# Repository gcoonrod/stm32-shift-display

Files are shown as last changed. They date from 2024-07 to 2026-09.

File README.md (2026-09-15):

# STM32 Shift Display

A proof-of-concept STM32 based development board designed for experimentation with 74x595 driven 7-segment LED character displays. The sponsored revision of the board is built out as a desk clock, the "STM32 Shift Clock".

> **Building or hacking on this?** [`docs/DEVELOPMENT.md`](./docs/DEVELOPMENT.md) covers prerequisites, build and flash, the USB command set, the pin map, and what is still unimplemented.

## Current Revision — rev 2
Sponsored by: 

PCBWay

Due to a generous sponsorship from PCBWay the current hardware revision (rev 2) includes a number of substantial design changes over the first revision:
-  All SMD components from rev 0 moved to the back.
-  Most THT components from rev 0 changed to hand-solder friendly SMD components.
-  Supercap backup for VBAT switched to more common CR2032 battery holder.
-  Addition of ESD IC for the USB connection and a correction for an issue with the USB FS series and pull-up resistors.
-  Move to a 4 layer PCB and use of via-in-pad resin plug with copper capping to simplify routing.
-  Addition of an aluminum sheet metal stand.
-  Remap latch OE pin and user LED pins to PWM capable outputs.
-  Break out UART3 "just in case".

Full schematic for this revision: [STM32ShiftDisplayRev2.pdf](./hardware/assets/STM32ShiftDisplayRev2.pdf)

### Revision Objectives
Issues with the USB connection in the first revision made a new revision necessary in order to support UART communication over the USB connection. While the USB termination bug was the primary driver for spinning a new board, there were also a few other short comings of the original design that became apparent during firmware development. The choice of shift registers to drive the LED displays instead of multiplexing made writing the display driver code simple but gave up the brightness control (from PoV) that comes "for free" with that approach. The 74HC595 has an output enable control signal that _maybe_ could be used to achieve a similar effect, so this revision includes a remapping of some of the signals, including the user LEDs, to pins on the MCU that support hardware PWM. 

As the objective of this project is as much learning as arriving at a finished "product", I took the opportunity to try out a number of new things as well. Did you know that PCBWay does sheet metal bending?

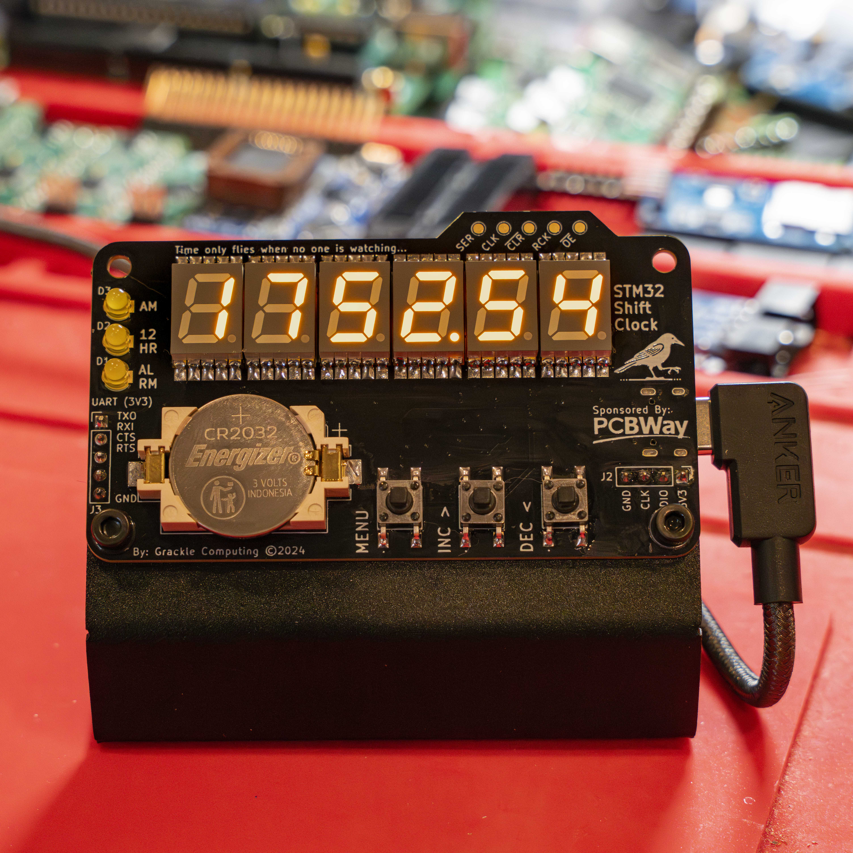
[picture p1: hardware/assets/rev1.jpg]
final product


### Pushing the Envelope
With a green light to "showcase capabilities" from PCBWay, I wanted to make something worth showing off. After reviewing the website and discovering their 3D printing/CNC milling service I decided to design something that would take advantage of more than just PCBWay's PCB printing capabilities. While the core of this project would remain a development board for STM32F1 hardware and software design, this sponsored revision would be the "STM32 Shift Clock". After a brief affair with a split board design I landed on the simple board and stand design above. This design allowed me to highlight three of PCBWay's capabilities that make them great board partners for hobbyists and professionals alike. First, the PCB is a 4-layer design utilizing [via-in-pad to simplify the routing](./hardware/assets/via-in-pad.PNG) between the shift registers and LEDs characters. PCBWay's engineers were great to work with on this and made the process of indicating which vias needed to be filled and capped simple. Which was really great because KiCad does not currently have a way to indicate if a specific via should be filled. Second, I moved all of the tiny (i.e. too hard to hand solder) components to the back of the board and relied on PCBWay's turnkey PCB assembly service to source the parts and do the hard work of getting all those tiny bits in the right spots. Again, PCBWay's engineers made the process of approving the parts selection and confirming placement and orientation easy. I used LCSC as the supplier for all of the parts on this board and all I had to do was indicate the LCSC part numbers and PCBWay took care of the rest. Their engineers even sent pictures of the boards in production so that I could visually inspect all of the parts placements. And finally, the stand. I've only ever dabbled in 3D printing and certainly never with metal. So when I saw that PCBWay could do low volume sheet metal bending I had to try it out. What followed was a caffeine fueled afternoon of YouTube tutorials and frustrating attempts to get the idea in my head out into FreeCAD. In the end I went with a very simple design that displays the PCB nicely while keeping it from tipping/sliding when pressing the buttons. I chose 5052 Aluminum with a bead blasted and anodized finish to match the PCB. Given the materials and manual labor involved I was really pleased with how reasonable the quoted cost was per piece. All in all I was very impressed with my interactions with PCBWay for this project. From the initial design submissions to the engineering verification and the customer service interactions PCBWay helped me take an idea from mind to matter and I look forward to working with them again on my future projects.

### A note on revision numbers

This board is called **rev 2** here and in `stm32-shift-display.kicad_sch`, but the
sources disagree and all of them describe this same physical board:

| Source | Says |
| --- | --- |
| Schematic title block, `STM32ShiftDisplayRev2.pdf` | rev 2 |
| Git branch `feature/board-rev2`, commit "Initial rev2 design" | rev 2 |
| `stm32-shift-display.kicad_pcb` title block | rev 1 *(stale)* |
| Photo and model assets — `rev1.jpg`, `board_and_stand_rev1.jpg`, `stm32-shift-display_rev1.step` | rev 1 *(same board)* |

The `.kicad_pcb` title block is corrected only when the board is next opened in
KiCad — see [Hardware files](./docs/DEVELOPMENT.md#hardware-files) for why that is
deliberately deferred.

## Firmware

The firmware keeps time on the MCU's RTC and exposes a small command console over
USB CDC, which [`software/timesync`](./software/timesync) uses to compare and correct
the clock against NTP. The on-device menu and display brightness control are not
finished. [`docs/DEVELOPMENT.md`](./docs/DEVELOPMENT.md) has the command set, the
known defects, and what is left to build.

## Schematic
current schematic

## Board Render
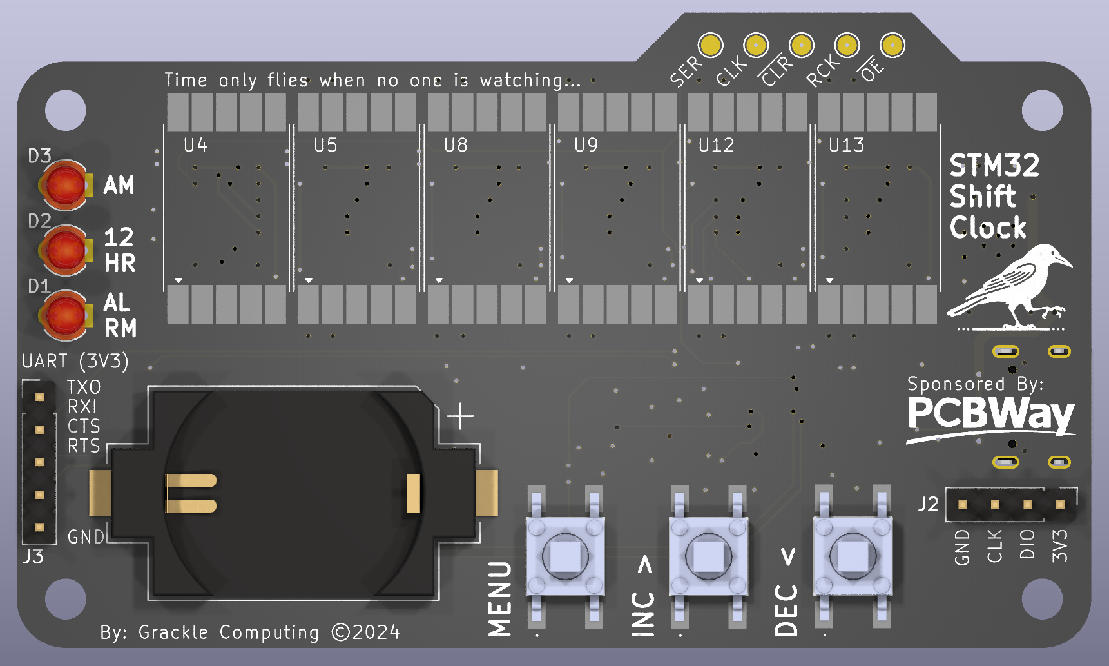
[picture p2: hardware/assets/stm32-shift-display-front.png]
current board


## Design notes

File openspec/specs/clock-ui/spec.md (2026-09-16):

# clock-ui Specification

## Purpose

Defines what the device shows and how it is operated from the board itself: the idle time display and its RTC-driven redraw, hours presented in the selected 12/24-hour mode, the three user LEDs as indicators of mode and alarm state, a three-button menu that can be entered, scrolled, backed out of, and timed out of, field editors that show which field is under edit, and a glyph table that covers every character the interface renders.

## Requirements

### Requirement: The display shows the current time at rest
When not in a menu, the display SHALL show the current time of day and SHALL update as the time advances. It SHALL be shown at the configured display brightness.

"At rest" excludes the brief fade that runs when the display returns from the menu. During that fade the digits are deliberately unequal in brightness; once it completes, they SHALL be equal again.

#### Scenario: Time is displayed and advances
- **WHEN** the device is powered and not in a menu
- **THEN** the display shows hours, minutes, and seconds, and the seconds change once per second

#### Scenario: Redraw is driven by the RTC, not by polling
- **WHEN** the time has not changed since the last redraw
- **THEN** the displayed content is not recomputed, so the idle path stays as cheap as it is today

#### Scenario: Shown at the configured brightness
- **WHEN** the display is showing the time and no fade is running
- **THEN** every lit segment is at the configured display brightness, and all six digits are equally bright

#### Scenario: Brightness and content are independent
- **WHEN** the brightness changes
- **THEN** the displayed characters are unaffected — nothing is re-shifted, no digit flickers or glitches, and the decimal point keeps its state

### Requirement: Hours are presented in the selected 12/24-hour mode
The display SHALL present hours according to the selected mode, showing 0–23 in 24-hour mode and 1–12 in 12-hour mode. The RTC SHALL remain configured in 24-hour format regardless of the selected display mode, so that the conversion is a presentation concern only.

In 12-hour mode the leading zero SHALL be suppressed: an hour below ten SHALL show a blank in the tens position rather than a zero. In 24-hour mode the leading zero SHALL be kept.

#### Scenario: Midnight in 12-hour mode
- **WHEN** the RTC hour is 0 and 12-hour mode is selected
- **THEN** the display shows 12, not 0

#### Scenario: Noon and afternoon in 12-hour mode
- **WHEN** the RTC hour is 12 and then 13, with 12-hour mode selected
- **THEN** the display shows 12 and then 1

#### Scenario: 24-hour mode is unaffected
- **WHEN** 24-hour mode is selected and the RTC hour is 0 or 13
- **THEN** the display shows 00 or 13 respectively

#### Scenario: The RTC format is untouched
- **WHEN** the display mode is changed
- **THEN** the RTC's own hour format is not reconfigured, and time read back over serial is unchanged by the switch

#### Scenario: Single-digit hours lose the leading zero
- **WHEN** the displayed hour is between 1 and 9 in 12-hour mode
- **THEN** the tens position is blank, with no segments lit

#### Scenario: Two-digit hours keep both digits
- **WHEN** the displayed hour is 10, 11 or 12 in 12-hour mode
- **THEN** both digits are shown

#### Scenario: The blank is consistent wherever the time appears
- **WHEN** the time is shown while an alarm is firing
- **THEN** the leading zero is suppressed exactly as it is on the idle display

### Requirement: The LEDs indicate mode and alarm state
The three user LEDs SHALL be driven from the authoritative device state, and SHALL be updated whenever that state changes. All three are active high, and each SHALL be driven at the configured indicator brightness rather than simply on or off.

#### Scenario: AM/PM indicator
- **WHEN** 12-hour mode is selected and the time is before 12:00
- **THEN** the top LED (PB8, schematic D3) is lit, and it is unlit from 12:00 onward

#### Scenario: AM/PM is meaningless in 24-hour mode
- **WHEN** 24-hour mode is selected
- **THEN** the top LED is unlit regardless of the time

#### Scenario: Mode indicator
- **WHEN** 12-hour mode is selected
- **THEN** the middle LED (PB7, schematic D2) is lit, and it is unlit in 24-hour mode

#### Scenario: Alarm indicator
- **WHEN** an alarm is armed
- **THEN** the bottom LED (PB6, schematic D1) is lit steadily

#### Scenario: Lit means the configured brightness
- **WHEN** any indicator is lit
- **THEN** it is driven at the configured indicator brightness, and an indicator that is unlit draws no current

#### Scenario: One writer owns the pins
- **WHEN** an indicator's state changes
- **THEN** it is changed through the single path that owns the LED pins, so no code path can reconfigure a pin away from its timer and silently stop the others

### Requirement: Indicator brightness is user-settable
The brightness of the three indicator LEDs SHALL be adjustable by the user as a single level covering all three, settable from the on-device menu and over the serial console, and SHALL persist across a power cycle.

#### Scenario: Adjusting from the menu
- **WHEN** the indicator brightness is changed through the menu and committed
- **THEN** the indicators are visibly dimmer or brighter, and reading the level back reports the new value

#### Scenario: Live preview while adjusting
- **WHEN** the level is being adjusted in the editor
- **THEN** the indicators track the value as it changes, so the choice is made by eye rather than by number

#### Scenario: Round-trips over serial
- **WHEN** the indicator level is set over serial and read back
- **THEN** the value read matches the value set, and a value outside the valid range is rejected without changing the level

#### Scenario: Survives a power cycle
- **WHEN** the level is set and power is removed and restored
- **THEN** the indicators return at the level that was set

#### Scenario: Levels are perceptually even
- **WHEN** the level is stepped from lowest to highest
- **THEN** each step is a comparable change in apparent brightness, rather than the whole range appearing to happen at the bottom of the scale

#### Scenario: The dimmest level is still visible
- **WHEN** the level is at its minimum
- **THEN** each lit indicator remains visible in a dark room, so the setting cannot be mistaken for a failed LED

### Requirement: Display brightness is user-settable
The brightness of the seven-segment display SHALL be adjustable by the user, settable from the on-device menu and over the serial console, and SHALL persist across a power cycle. It is a single level covering the whole display, because the output-enable line is shared by all six digits.

Per-digit brightness, where it is used, SHALL multiply this level rather than replace it: the user's display brightness setting SHALL remain the control that dims every digit together, and no per-digit level SHALL make a digit brighter than that setting allows.

#### Scenario: Adjusting from the menu
- **WHEN** the display brightness is changed through the menu and committed
- **THEN** the display is visibly dimmer or brighter, and reading the level back reports the new value

#### Scenario: The display previews itself
- **WHEN** the level is being adjusted in the editor
- **THEN** the display tracks the value as it changes, so the choice is made by eye against the thing being adjusted

#### Scenario: Round-trips over serial
- **WHEN** the display level is set over serial and read back
- **THEN** the value read matches the value set, and a value outside the valid range is rejected without changing the level

#### Scenario: Survives a power cycle
- **WHEN** the level is set and power is removed and restored
- **THEN** the display returns at the level that was set

#### Scenario: Levels are perceptually even
- **WHEN** the level is stepped from lowest to highest
- **THEN** each step is a comparable change in apparent brightness, rather than the whole range appearing to happen at the bottom of the scale

#### Scenario: The dimmest level is still legible
- **WHEN** the level is at its minimum
- **THEN** the time can still be read in a dark room, so a dimmed clock is never mistaken for a failed one

#### Scenario: No visible flicker
- **WHEN** the display is viewed at any brightness, including at the edge of vision and while the eyes are moving
- **THEN** no flicker is perceptible

#### Scenario: Indicator brightness is separate
- **WHEN** the display brightness is changed
- **THEN** the indicator LEDs are unaffected, and vice versa

#### Scenario: A per-digit level cannot escape the global one
- **WHEN** the global display brightness is set to its minimum while a digit is at full relative brightness
- **THEN** that digit is no brighter than the global minimum allows

### Requirement: Individual digits can be dimmed relative to the display
The display SHALL support dimming individual character positions relative to the rest of the display, by lighting a digit in only some of the refresh cycle's time slices rather than all of them.

A digit's relative brightness SHALL be proportional to the number of slices it is lit in, and SHALL be independent of which slices those are and of the phase relationship with the output-enable line.

A digit at full relative brightness SHALL be indistinguishable from the same digit on a display with no per-digit dimming in use.

#### Scenario: A dimmed digit is visibly dimmer
- **WHEN** one character position is set below full relative brightness while the others stay at full
- **THEN** that digit is visibly dimmer than the others, and remains legible

#### Scenario: Full relative brightness changes nothing
- **WHEN** every character position is at full relative brightness
- **THEN** the display is indistinguishable from the same content shown without per-digit dimming

#### Scenario: Relative brightness is proportional
- **WHEN** a digit's slice count is stepped from lowest to highest
- **THEN** its brightness increases monotonically, and equal slice counts on different character positions produce equal brightness

#### Scenario: A dimmed digit does not flicker
- **WHEN** a digit is held at a low relative brightness
- **THEN** it shows no flicker, beat or shimmer distinct from the rest of the display

#### Scenario: Zero slices blanks the digit
- **WHEN** a character position is set to zero slices
- **THEN** that position shows no lit segments, and the other positions are unaffected

### Requirement: The two brightness mechanisms compose without visible interaction
Global brightness on the output-enable line and per-digit brightness in the data path are independent modulations that multiply. Their periods SHALL be related such that every time slice contains a whole number of output-enable periods, so that each slice carries the same output-enable on-time regardless of the phase between them.

The timer constants that establish this relationship SHALL be derived at build time from the output-enable frequency and the core clock, rather than written as independent literals. The build SHALL fail if the relationship is not exact.

#### Scenario: No beat between the two rates
- **WHEN** the display is held at any combination of global brightness and per-digit brightness
- **THEN** no slow flutter, beat or breathing is visible that is not commanded

#### Scenario: Digits at equal slice counts are equally bright
- **WHEN** two character positions are set to the same slice count at any global brightness
- **THEN** they are equally bright, with no fixed difference attributable to where their slices fall

#### Scenario: Global brightness still covers everything
- **WHEN** the global display brightness is changed while per-digit levels are in use
- **THEN** every digit changes brightness together, keeping their relative proportions

#### Scenario: Retuning the output-enable frequency cannot silently break the lock
- **WHEN** the output-enable PWM frequency is changed and the slice period would no longer contain a whole number of output-enable periods
- **THEN** the build fails, rather than producing firmware with per-digit brightness errors

### Requirement: The output-enable line has a single owner
The shift registers' output-enable line SHALL be driven by exactly one mechanism. Any operation that blanks or restores the display SHALL go through that owner rather than writing the pin directly, because a direct write would reconfigure the pin away from its timer and silently stop the brightness control.

The output-enable line shares a GPIO port with the shift registers' data, clock, latch and clear lines. Code driving those lines SHALL address only the pins it owns, and SHALL NOT write the port as a whole, because a whole-port write reaches across the output-enable line whatever its intent.

This SHALL hold for writes performed by a peripheral as well as by the CPU. Where the port is driven from precomputed words replayed by hardware, those words SHALL be constructed so that they cannot address the output-enable pin, and that property SHALL be enforced at build time rather than left to inspection — nothing in the instruction stream shows such a mistake.

#### Scenario: Blanking and restoring go through the owner
- **WHEN** code blanks or re-enables the display
- **THEN** it does so through the brightness owner, and the pin is never written directly

#### Scenario: Restoring returns to the configured brightness
- **WHEN** the display is blanked and then re-enabled
- **THEN** it returns to the configured brightness rather than to full

#### Scenario: The display is blank through reset
- **WHEN** the MCU is in reset or has not yet configured the pin
- **THEN** the display is blank rather than showing whatever the shift registers powered up holding

#### Scenario: Shifting data does not disturb brightness
- **WHEN** data is shifted out, latched, or the registers are cleared
- **THEN** the output-enable line is unaffected and the display's brightness does not change

#### Scenario: Port-wide writes are not used
- **WHEN** the display driver drives its pins
- **THEN** it addresses them individually rather than writing the whole port, so no operation can reach a pin it does not own

#### Scenario: Peripheral-written words cannot reach the output-enable pin
- **WHEN** a word destined for the port is constructed for replay by hardware
- **THEN** it addresses only the data, clock, latch and clear pins, and a word that would set or clear the output-enable pin fails the build

### Requirement: The menu is reachable and navigable with three buttons
Clicking SET from the idle display SHALL open a top-level menu. PLUS and MINUS SHALL move between menu entries, wrapping at the ends. Clicking SET SHALL enter the highlighted entry. Holding SET SHALL leave the current level without committing a change.

#### Scenario: Entering the menu
- **WHEN** SET is clicked while the clock is displayed
- **THEN** the first menu entry is shown

#### Scenario: Scrolling wraps
- **WHEN** MINUS is pressed on the first menu entry
- **THEN** the last entry is shown

#### Scenario: Backing out discards
- **WHEN** SET is held while inside an entry whose value has been altered but not committed
- **THEN** the previous level is shown and the altered value is not saved

#### Scenario: Menu state actually advances
- **WHEN** a menu transition is requested
- **THEN** the state machine commits the pending menu state, so successive transitions move through the tree rather than repeating the same state

### Requirement: Field editors show which field is being edited
Inside an editor, the field under edit SHALL be visually distinguished by blinking. PLUS and MINUS SHALL adjust the field, wrapping at its limits, and SHALL repeat while held. Clicking SET SHALL advance to the next field, and SHALL commit the value after the last field.

#### Scenario: The edited field blinks
- **WHEN** the hour field is being edited
- **THEN** the hour digits alternate between visible and blank while the remaining digits stay lit

#### Scenario: Values wrap at their limits
- **WHEN** PLUS is pressed with the minute field at 59
- **THEN** the minute field becomes 0

#### Scenario: Holding repeats
- **WHEN** PLUS is held
- **THEN** the field advances repeatedly without further presses

#### Scenario: Committing writes through
- **WHEN** SET is clicked on the last field of the time editor
- **THEN** the new time is written to the RTC and the display returns to showing it

### Requirement: The menu does not strand the device
The menu SHALL return to the idle time display after a period with no button activity, so the device cannot be left showing a menu indefinitely.

#### Scenario: Inactivity returns to the clock
- **WHEN** no button is pressed for the inactivity period while a menu or editor is open
- **THEN** the display returns to the time, with no uncommitted value saved

### Requirement: Returning to the clock from the menu fades the digits in
When the display returns to the idle time display from the menu or an editor, the digits SHALL fade in one at a time, left to right, rather than appearing at once. This SHALL apply whether the return was by backing out, by committing an edit, or by the inactivity timeout.

The fade SHALL be driven by elapsed time rather than by counting steps, so that a delayed pass through the main loop shortens the fade rather than stretching it.

The fade SHALL change brightness only. The displayed content SHALL NOT be recomputed or re-shifted on its account.

The fade SHALL always end with every character position at full relative brightness and the display at the configured global brightness. If anything interrupts it — a button press, a re-entry to the menu, an alarm firing — it SHALL be abandoned and every position returned to full immediately, so that no path can leave a digit dim.

#### Scenario: Backing out of the menu fades in
- **WHEN** the menu is backed out of and the display returns to the time
- **THEN** the digits appear one at a time from left to right, and all six are at full brightness when the fade completes

#### Scenario: Committing an edit fades in
- **WHEN** an editor's last field is advanced past and the value is committed
- **THEN** the display returns to the time with the same fade

#### Scenario: Timing out fades in
- **WHEN** the inactivity timeout returns the display to the time
- **THEN** the display returns with the same fade

#### Scenario: Dismissing an alarm does not fade
- **WHEN** a firing alarm is dismissed and the display returns to the time
- **THEN** the time is shown at once, at full brightness, with no fade

#### Scenario: Interrupting the fade does not strand a dim digit
- **WHEN** a button is pressed, the menu is re-entered, or an alarm fires while the fade is running
- **THEN** the fade is abandoned and every character position is at full relative brightness immediately

#### Scenario: The fade ends at the user's brightness, not above or below it
- **WHEN** the fade completes at any configured display brightness, including the minimum
- **THEN** the display is at exactly the brightness it would have been had there been no fade

#### Scenario: A blanked position stays blank through the fade
- **WHEN** the leading hour position is blank in 12-hour mode and the fade runs
- **THEN** nothing appears at that position at any point in the fade, and the remaining digits keep their timing

#### Scenario: The fade does not recompute content
- **WHEN** the fade is running and the time has not changed
- **THEN** the displayed characters are not recomputed or re-shifted, so the idle path stays as cheap as it is today

#### Scenario: A slow loop shortens the fade rather than stretching it
- **WHEN** the main loop is delayed during a fade
- **THEN** the fade reaches full brightness at the time it would have anyway, skipping intermediate levels rather than running long

### Requirement: The glyph table covers the characters the UI renders
The display driver SHALL render every character the user interface asks it to draw. The glyph table and the character-range validation SHALL be extended together, so that a character added to one is never rejected by the other.

#### Scenario: Menu labels render
- **WHEN** a menu label is written to the display
- **THEN** every character in it renders as its intended glyph, not as the invalid-character indicator

#### Scenario: Unsupported characters still fail visibly
- **WHEN** a character with no glyph is written
- **THEN** the invalid-character indicator is shown, rather than a blank or an arbitrary pattern

### Requirement: The display refreshes without CPU involvement
The display SHALL be refreshed continuously by a hardware peripheral replaying a precomputed waveform, rather than by the CPU clocking bits out on demand. The refresh SHALL continue at its full rate while the CPU is busy elsewhere, and SHALL NOT require the main loop to run at any particular rate.

Changing what is displayed SHALL be a matter of writing to the waveform buffer. No caller SHALL be required to shift or latch anything for the change to appear.

#### Scenario: The refresh survives a busy CPU
- **WHEN** the main loop is occupied for longer than one refresh period
- **THEN** the display continues refreshing at the same rate, with no flicker, dimming or corruption

#### Scenario: Writing the buffer is enough
- **WHEN** new content is written to the display
- **THEN** it appears without the caller shifting or latching, within one refresh period

#### Scenario: The refresh rate is above the flicker threshold
- **WHEN** the display is viewed at the edge of vision, or while the eyes are moving across it
- **THEN** no flicker is perceptible at any brightness

#### Scenario: Nothing is shown before the engine is configured
- **WHEN** the MCU has reset and the engine has not yet been started
- **THEN** the display is blank rather than showing whatever the shift registers powered up holding

### Requirement: The shift-out stays within the shift registers' timing limits
The rate at which data is clocked into the shift registers SHALL be slow enough for the devices fitted, at the voltage they run at, with margin. The limit SHALL be established by measurement on the assembled board rather than by calculation alone, because the binding constraint is the serial propagation delay accumulated through a chain of six devices, and the parts are specified at a higher voltage than the board supplies.

Where the rate is set by a timer rather than by instruction timing, it SHALL be a chosen frequency derived from the core clock, not a consequence of what the compiler emitted. The chosen rate SHALL still be justified against the measured failure point.

#### Scenario: The safe rate is measured, not assumed
- **WHEN** the shift rate is chosen
- **THEN** it is derived from an observed failure point on the assembled hardware, and the margin between the two is recorded

#### Scenario: Corruption is made visible during measurement
- **WHEN** the shift rate is swept to find the failure point
- **THEN** the pattern on the display is one where corruption is unmistakable, since the end of the chain is not wired back and no electrical readback exists

#### Scenario: The display is correct at the chosen rate
- **WHEN** the display is exercised at the chosen rate across all six digits and the full glyph set
- **THEN** every character renders correctly, with no intermittent wrong segments

#### Scenario: The rate is stated where it can be found
- **WHEN** someone asks why the shift runs at the rate it does
- **THEN** the measured failure point, the chosen rate and the margin between them are recorded, rather than left as an unexplained constant

#### Scenario: A timer-set rate is exact
- **WHEN** the shift clock is produced by a timer
- **THEN** its frequency follows from the core clock and the timer's reload value, and is stated as a number rather than estimated from instruction counts

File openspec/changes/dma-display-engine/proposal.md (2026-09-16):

## Why

Brightness today is global because the hardware makes it so: `~OE` is a single net across
all six shift registers, so TIM2's PWM dims every digit together. There is no wire that
would let one digit be dimmer than another.

But brightness does not have to come from `~OE`. If the segment data is re-shifted fast
enough, a digit lit in three refreshes out of eight is three-eighths as bright as one lit
in all eight — brightness as a property of the *data* rather than the output-enable line.
That gives per-digit and per-segment control that the wiring cannot.

The obstacle is cost. Data-path dimming needs the display re-shifted continuously at
kilohertz rates, and doing that from the CPU means spending the loop on it forever.

DMA removes the obstacle entirely. `BSRR` takes a 32-bit word whose low half sets pins and
whose high half clears them, so an entire shift waveform can be precomputed as an array of
words and replayed by a DMA channel on a timer's tick, with the CPU uninvolved:

```
RAM buffer, one BSRR word per edge:

  [ SER set,   SRCLK clear ]   present the bit
  [ SRCLK set              ]   rising edge clocks it in
  [ SER clear, SRCLK clear ]
  [ SRCLK set              ]
  ... 96 words for 48 bits ...
  [ RCLK set ] [ RCLK clear ]  latch

  TIM1 update ──▶ DMA1 Ch5 ──▶ GPIOA->BSRR
    every N ticks   one word per event
```

In **circular** mode the buffer replays forever. The display stops being something the CPU
draws and becomes something that refreshes itself.

All seven DMA1 channels are free — the only DMA symbols in the current image are two-byte
default interrupt stubs. TIM1 and TIM3 are unused; TIM2 and TIM4 belong to display
brightness and the indicator LEDs and stay untouched.

## What Changes

- A timer-driven, circular DMA channel replays a precomputed `BSRR` waveform to GPIOA,
  refreshing the display continuously with no CPU involvement.
- The waveform holds **N time-slices**. A digit's brightness is how many slices it appears
  lit in, giving per-digit — and in principle per-segment — brightness.
- The timer period sets the shift clock **exactly**, which also settles the 74HC595-at-3.3 V
  timing question far better than instruction counting can: the rate is a number you choose
  rather than a consequence of what the compiler emitted.
- Global `~OE` brightness stays as it is. Per-digit brightness multiplies with it rather
  than replacing it.
- The first use is the one that prompted this: **dimming the leading hour digit in 12-hour
  mode** rather than blanking it.

## What this costs

The numbers are the argument, in both directions.

For a flicker-free cycle the whole slice set must repeat well above the eye's threshold.
At 8 slices and roughly 100 words per full shift, a 1 kHz cycle rate needs

```
8 slices × 100 words × 1000 Hz  =  800,000 words/second
                                =  ~400 kHz shift clock   (comfortably within the parts)
                                =  3,200 bytes of RAM      (8 × 100 × 4)
```

3.2 KB against 20 KB total, on top of the 4.9 KB already used — call it 39% of RAM. Four
slices halves it at the cost of coarser steps.

Against that: the CPU cost of refreshing the display drops to zero, and stays zero no
matter how fast it refreshes.

## Capabilities

### New Capabilities
_None._

### Modified Capabilities
- `clock-ui`: "Display brightness is user-settable" currently states that brightness is a
  single level for the whole display because the output-enable line is shared. That
  reasoning stops being the whole story once brightness can also come from the data path,
  so the requirement needs to say how the two interact. The capability also gains per-digit
  brightness, and a requirement that the display refreshes without CPU involvement.

## Impact

- **Firmware**: `firmware/lib/ShiftDisplay/` substantially — the driver stops shifting bits
  and starts maintaining a waveform buffer. `firmware/src/main.cpp` where brightness and
  rendering meet.
- **Peripherals**: claims a timer (TIM1 or TIM3) and a DMA1 channel. Neither is used today,
  and TIM2/TIM4 are deliberately left alone.
- **RAM**: 1.6–3.2 KB depending on slice count, against 15.6 KB free.
- **Risk**: this is the largest single change contemplated for this firmware. It replaces a
  working display driver with a peripheral configuration, and DMA faults are harder to
  diagnose than a wrong `digitalWrite`. There is also **no readback**: `U15`'s `QH'` is
  unconnected, so correctness is confirmed by eye.
- **Two PWMs multiplying**: data-path slices and `~OE` gating interact. Beat frequencies
  between the slice rate and the `~OE` rate are the thing to watch, and the reason the two
  rates should not be close or harmonically related.

## Ordering

`bsrr-shift-out` should land first. It establishes the cached port, the cached masks and
the explicit `BSRR` discipline that this engine builds on, and it produces the measured
safe clock rate that this change needs in order to choose a timer period. Doing this one
first would mean guessing that number twice.

## Not in scope

- **Blanking** the leading hour digit, which needs no engine at all — writing a space
  instead of a zero is a few lines in the render path and should not wait for this.
- Any change to what the display shows, beyond the brightness of individual digits.
- Replacing `analogWrite` on `~OE`; global brightness stays on TIM2 exactly as it is.

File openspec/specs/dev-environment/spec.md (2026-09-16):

# dev-environment Specification

## Purpose

Defines what a working development environment for this project must provide: PlatformIO Core invocable from a plain shell, a firmware build that succeeds from a clean tree, flashing over SWD via ST-Link, a board reachable over USB CDC, a reproducible Python environment for the host tooling in `software/timesync/`, explicit serial port selection, and a single documented readiness check.

## Requirements

### Requirement: PlatformIO Core is invocable from a shell
The development environment SHALL provide PlatformIO Core as a `pio` executable resolvable on `PATH` from a non-interactive shell, so that builds and flashes can be driven from a terminal or an agent session without an IDE.

#### Scenario: pio resolves in a fresh shell
- **WHEN** `pio --version` is run in a newly started shell
- **THEN** it prints a PlatformIO Core version and exits 0

#### Scenario: PlatformIO is not tied to an editor installation
- **WHEN** the `pio` executable's location is inspected
- **THEN** it resolves outside any VS Code extension directory, so terminal and IDE use do not depend on each other

### Requirement: Firmware builds from a clean tree
The repository SHALL build to completion with the toolchain installed on this machine, starting from a tree with no prior build artifacts.

#### Scenario: Clean build succeeds
- **WHEN** `firmware/.pio/` is removed and `pio run -d firmware` is run
- **THEN** PlatformIO fetches the `ststm32` platform, the ARM toolchain, and the three `lib_deps`, and the build exits 0

#### Scenario: Build produces a flashable image
- **WHEN** the build completes
- **THEN** `firmware/.pio/build/bluepill_f103c8_128k/firmware.elf` and `firmware.bin` exist and are newer than the build start

### Requirement: Firmware flashes over SWD
The environment SHALL flash the connected board through the attached ST-Link, since the board offers no DFU or bootloader upload path.

#### Scenario: Upload to the attached board
- **WHEN** the ST-Link is connected to the board's SWD header and `pio run -d firmware -t upload` is run
- **THEN** the upload completes successfully and the MCU restarts running the new image

#### Scenario: Missing debugger is reported clearly
- **WHEN** an upload is attempted with no ST-Link attached
- **THEN** the failure names the missing probe rather than presenting as a build error

### Requirement: The board answers over USB CDC
The environment SHALL be able to open the board's USB CDC port and exchange commands with the running firmware.

#### Scenario: Device reports its time
- **WHEN** `GT\r\n` is written to the board's CDC port
- **THEN** the device replies with a single integer Unix timestamp

#### Scenario: CDC port is discoverable
- **WHEN** the board is attached and serial devices are enumerated
- **THEN** the STM32 CDC device is identifiable by its USB descriptor rather than only by a machine-specific device-node name

### Requirement: Host tooling runs from a reproducible environment
The `software/timesync` tool SHALL run from an environment that pins its interpreter and dependencies and is recreatable from files committed to the repository, without depending on whichever interpreter happens to be first on `PATH`.

#### Scenario: Environment is recreated from a clean checkout
- **WHEN** the environment directory is absent and the documented setup command is run in `software/timesync/`
- **THEN** the environment is created with the pinned interpreter and `pyserial` and `ntplib` importable

#### Scenario: Tool runs against the device
- **WHEN** the board is attached and the timesync tool is run in read-only mode
- **THEN** it prints the NTP time, the device time, and the skew between them, and exits 0

#### Scenario: No dependence on an absent interpreter
- **WHEN** the environment is inspected for the interpreter it resolves to
- **THEN** that interpreter exists on this machine, and no committed file references a Homebrew `python@3.12.4` path

### Requirement: Serial port selection is explicit
The timesync tool SHALL NOT silently fall back to a device node hardcoded for one machine. It SHALL select a port that it discovered, or one the caller supplied, and SHALL fail with an actionable message when neither is available.

#### Scenario: Port supplied by the caller
- **WHEN** the tool is invoked with an explicit port argument
- **THEN** it uses that port and does not consult any default

#### Scenario: No device attached
- **WHEN** the tool is run with no port argument and no STM32 CDC device is present
- **THEN** it exits non-zero with a message naming the missing device and how to specify a port

### Requirement: Environment readiness is verifiable in one step
The repository SHALL provide a documented way to check the prerequisites for firmware and host-tool development, reporting each one's presence rather than failing at the first gap.

#### Scenario: Readiness check on a configured machine
- **WHEN** the documented check is run on a machine with the toolchain installed
- **THEN** it reports PlatformIO, the Python environment, the attached ST-Link, and the attached CDC device as present

#### Scenario: Readiness check on an unconfigured machine
- **WHEN** the check is run where PlatformIO is absent
- **THEN** it reports that specific prerequisite as missing and names the command that installs it

### Requirement: The toolchain is not pinned to a superseded core line
The firmware SHALL build against a currently published Arduino STM32 core, and SHALL NOT depend on a platform version whose framework package the PlatformIO registry no longer serves. Where a version constraint is kept, it SHALL be a floor or a range that continues to resolve, not a pin to a single superseded release.

#### Scenario: Build resolves without a platform pin
- **WHEN** `firmware/platformio.ini` names no exact platform version and `pio run -d firmware` is run
- **THEN** PlatformIO resolves the current `ststm32` platform and the build exits 0

#### Scenario: Library constraints admit the versions that work
- **WHEN** the `lib_deps` constraints are resolved against the registry
- **THEN** each one resolves to a version that compiles against the core in use, and no dependency is listed that the project neither includes nor calls

#### Scenario: Registry purge does not strand the build
- **WHEN** a framework package older than the one in use is purged from the registry
- **THEN** the project's own constraints still resolve, because they do not name it

### Requirement: A toolchain change is verified on hardware
A change that alters the compiler, core, or library versions the firmware is built against SHALL be verified by running the resulting image on the board, not by compilation alone. Compiling proves the source is accepted; it does not prove the peripherals still behave.

#### Scenario: The image runs after a toolchain change
- **WHEN** firmware built against the new toolchain is flashed to the board
- **THEN** the display shows the time and the digits advance, confirming the RTC seconds interrupt still fires

#### Scenario: The command console survives the change
- **WHEN** the board is addressed over USB CDC after the change
- **THEN** it enumerates with USB descriptor `0483:5740` and answers `TEST` with `TEST` and `GT` with an integer Unix timestamp

#### Scenario: Timekeeping survives the change
- **WHEN** the clock is set over CDC and read back after at least a minute
- **THEN** the time has advanced by the elapsed interval, confirming the LSE clock source and RTC configuration still work

#### Scenario: A regression is attributable
- **WHEN** behavior differs from before the toolchain change
- **THEN** the change under test contains no unrelated source edits, so the difference is attributable to the toolchain

### Requirement: Flash headroom is known and protected
The firmware's flash usage SHALL be reportable on demand, expressed against the device's fixed capacity. A change that materially increases it SHALL be a deliberate choice rather than something discovered when a build stops fitting.

#### Scenario: Usage is reportable
- **WHEN** the environment readiness check is run
- **THEN** it reports the current flash usage and the remaining headroom, without requiring a separate build step to be remembered

#### Scenario: A regression is attributable
- **WHEN** flash usage grows materially between two builds
- **THEN** the growth can be attributed to the change that caused it, because the figure is recorded per change rather than only observed at the end

#### Scenario: The budget is stated, not implied
- **WHEN** someone asks how much room is left
- **THEN** the answer comes from the documented capacity and current usage rather than from reading a build log

#### Scenario: Headroom survives a size-reduction effort
- **WHEN** space is reclaimed by a change whose purpose is reclaiming it
- **THEN** the new figure is recorded, so later work starts from a known baseline rather than from the last number anyone happened to notice

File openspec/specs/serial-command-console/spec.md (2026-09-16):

# serial-command-console Specification

## Purpose

Defines the USB CDC command console: the existing `TEST`, `GT`, `ST`, `SO`, and `GO` commands preserved exactly so host tooling keeps working, serial access to every setting the on-device menu can change, and argument validation that rejects missing or out-of-range values instead of applying partial or clamped ones.

## Requirements

### Requirement: The existing command set is preserved exactly
The commands `TEST`, `GT`, `ST`, `SO`, and `GO` SHALL keep their current names, arguments, replies, and framing. Host tooling written against them SHALL continue to work without modification. Their internal implementation may change freely, provided the bytes on the wire do not.

The one permitted exception is the calendar month, which SHALL be represented consistently as 1–12 by every path that reads or writes it. A date set over serial and a date set from the on-device menu SHALL agree with each other and with the RTC.

#### Scenario: Existing commands answer as before
- **WHEN** `TEST`, `GT`, and `GO` are sent
- **THEN** they reply `TEST`, a Unix timestamp, and the timezone offset respectively, as they did before this change

#### Scenario: Setting the time still works
- **WHEN** `ST` is sent with a Unix timestamp
- **THEN** it replies `OK` and the clock is set, and reading the time straight back with `GT` returns the timestamp that was set

#### Scenario: The host tool is unaffected
- **WHEN** the existing timesync tool is run against the device
- **THEN** it reports the device time and corrects it exactly as it did before this change, with no edit to the tool

#### Scenario: Framing is unchanged
- **WHEN** commands are sent terminated by carriage return and newline with space-separated arguments
- **THEN** they are parsed as before, within the existing receive buffer size

#### Scenario: The two ways of setting the date agree
- **WHEN** a date is set from the on-device menu and then read over serial
- **THEN** the month reported matches the month that was entered, and the same holds in reverse for a date set over serial and then viewed in the menu

#### Scenario: Replies are byte-identical
- **WHEN** any command's reply is compared against the same command's reply from the previous firmware
- **THEN** the bytes match exactly, including error messages, separators and line endings

### Requirement: The new device state is reachable over serial
Every setting the on-device menu can change SHALL also be readable and writable over the serial console, so the device can be configured and tested from a host.

#### Scenario: Display mode round-trips
- **WHEN** the 12/24-hour mode is set over serial and read back
- **THEN** the value read matches the value set, and the display and mode LED reflect it

#### Scenario: Alarm time round-trips
- **WHEN** the alarm time is set over serial and read back
- **THEN** the value read matches the value set

#### Scenario: Armed state round-trips
- **WHEN** the alarm is armed over serial and the armed state is read back
- **THEN** it reports armed, and the bottom LED is lit

#### Scenario: Menu changes are visible to the host
- **WHEN** a setting is changed using the buttons and then read over serial
- **THEN** the value read reflects the change made on the device

### Requirement: Commands validate their arguments
A command given a missing or out-of-range argument SHALL report an error and leave device state unchanged, rather than applying a partial or clamped value.

#### Scenario: Missing argument
- **WHEN** a command requiring an argument is sent without one
- **THEN** it replies with an error and no state changes

#### Scenario: Out-of-range argument
- **WHEN** a command is sent a value outside the valid range for its field
- **THEN** it replies with an error naming the problem and no state changes

#### Scenario: Unrecognized commands are still reported
- **WHEN** an unknown command is sent
- **THEN** the existing unrecognized-command reply is produced

### Requirement: Persisted settings are diagnosable from a host
The device SHALL report the raw contents of its settings storage over the serial console, including the values read at start-up before any code could overwrite them. Settings loss that cannot be reproduced on demand is otherwise indistinguishable from settings that were never saved, and the two have opposite causes.

#### Scenario: Start-up values are reported as they were read
- **WHEN** the raw settings storage is read over serial
- **THEN** the report includes what the start-up read returned, distinct from what the storage holds at the time of the query

#### Scenario: A self-inflicted overwrite is distinguishable from lost storage
- **WHEN** settings have unexpectedly returned to their defaults
- **THEN** the report shows whether start-up saw valid stored settings, which separates storage that failed to retain from firmware that overwrote good values with defaults

#### Scenario: The expected validity marker is reported alongside
- **WHEN** the report is read
- **THEN** it includes the value the firmware treats as marking initialised storage, so a mismatch is visible without consulting the source

### Requirement: Command replies do not depend on formatted-output machinery
Command replies SHALL be produced without pulling a general-purpose formatted-output implementation into the image. The text of every reply is fixed by "The existing command set is preserved exactly"; how it is assembled is not, and the assembly method SHALL be chosen so that the cost of the whole `printf` family is not paid for `%d` and `%s`.

#### Scenario: The formatted-output engine is absent
- **WHEN** the linked image is inspected for the general-purpose formatted-output implementation
- **THEN** it is not present

#### Scenario: Replies are unchanged by the substitution
- **WHEN** every command that previously used formatted output is exercised, including its error paths
- **THEN** each reply is byte-identical to the previous firmware's

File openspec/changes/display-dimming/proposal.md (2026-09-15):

## Why

The display runs at one brightness: full. Six digits are driven statically — six
74HC595s, 48 segment resistors, every lit segment conducting continuously — so a clock
showing `12 34 56` has upwards of twenty segments on at all times. On a desk that is
right. At 3am it is a lamp.

The hardware was built for this. `~OE` is on PA0, which is `TIM2_CH1`, and TIM2 is
entirely unclaimed (the variant reserves TIM3 for `tone()` and TIM4 for `Servo`). The
netlist shows `~OE` as a single net reaching all six registers:

```
        PA0 ──┬── R12 10k ── VCC        pull-up: blanked through reset
              │
              ├──▶ U6.13  ~OE  digit 1
              ├──▶ U7.13  ~OE  digit 2
              ├──▶ U10.13 ~OE  digit 3
              ├──▶ U11.13 ~OE  digit 4
              ├──▶ U14.13 ~OE  digit 5
              └──▶ U15.13 ~OE  digit 6
```

That topology makes PWM dimming close to an ideal case rather than a compromise. On a
multiplexed display, dimming fights the refresh scan — modulating a signal that is
already chopped, producing beats and uneven digits. Here there is no scan to fight.
Duty becomes the only variable and the instantaneous segment current stays at its design
point at every brightness, so the LEDs never drift toward the low-current region where
efficiency and colour go strange. `~OE` to output on an HC595 is tens of nanoseconds,
four orders of magnitude faster than the shortest duty step worth using, so the shift
registers are nowhere near the limit.

The dead `irq_timer_led()` in `main.cpp` is a software attempt at the same idea —
toggling `display.enable()`/`disable()` from a timer callback that nothing ever calls.
The hardware can do it properly.

## What Changes

- Drive `~OE` from TIM2_CH1 PWM, giving global display brightness across all six digits.
- **A brightness level in the menu**, persisted like the other settings, with the display
  itself as the live preview while adjusting — the one setting whose effect you can see
  as you change it.
- Gamma-mapped levels, for the same perceptual reason as the indicator LEDs.
- **A minimum brightness floor.** The lowest selectable level stays legible; a clock
  dimmed to nothing reads as a dead clock, and someone will conclude the board has
  failed.
- PWM frequency in the low kilohertz. Flicker, not resolution, is the constraint: at
  72 MHz even 10 kHz leaves 7,200 duty steps, far more than the handful of levels a user
  will ever see, whereas a few hundred hertz on a bright point source in a dark room is
  exactly where eye movement makes flicker visible.
- **`ShiftDisplay::enable()`/`disable()` become brightness operations.** They currently
  `digitalWrite` PA0, which once TIM2 owns the pin in alternate-function mode would
  reconfigure it back to plain GPIO and silently stop the PWM. Every caller has to go
  through the new path.
- Serial get/set for the brightness level.
- Consume the dead `irq_timer_led()` hook, which this change replaces with hardware.

## Capabilities

### New Capabilities
_None._

### Modified Capabilities
- `clock-ui`: "The display shows the current time at rest" gains brightness as a property
  of the display, and the capability gains a requirement that display brightness is
  user-settable, persisted, and floored above invisibility.
- `alarm`: only if the firing flash moves onto `~OE` — see below. If it stays
  buffer-based, `alarm` is untouched.

## Impact

- **Firmware**: `firmware/lib/ShiftDisplay/` (`enable()`/`disable()` semantics, timer
  ownership), `firmware/src/main.cpp` (timer setup, settings, menu, serial).
- **Timer**: claims TIM2. Note that PA0–PA3 are TIM2_CH1–CH4 and those are the `~OE`,
  `~SRCLR`, `RCLK` and `SER` lines — TIM2 is the shift-register timer by pin allocation,
  but only CH1 is wanted and the other channels staying unconfigured leaves those pins as
  ordinary GPIO.
- **Backup domain**: one more persisted value. DR8 and DR9 are free; DR1, DR4, DR6, DR7
  and DR10 are spoken for.
- **Flash**: about 17 KB free at 74.2% used.
- **Failsafe is already correct** and should stay that way: R12 pulls `~OE` high whenever
  PA0 is high-impedance, so the display is blank from power-on until firmware drives it,
  rather than showing whatever garbage the registers powered up with.

## Open question for the design

The alarm currently flashes by rewriting the six-character buffer and re-shifting 48
bits. With `~OE` as a brightness knob, flashing could instead be a duty change — cheaper,
and it would blank the decimal point too, which the buffer approach does not.

But the field-edit blink **cannot** move: it blanks only the field being edited, and
`~OE` is all-or-nothing across the whole display. So taking the cheap win for the alarm
means carrying two different blanking mechanisms. That tradeoff belongs in design.md, not
here.

## Not in scope

- Indicator LED brightness — that is `indicator-led-dimming`, on TIM4.
- Automatic dimming by time of day. A night schedule is a policy layered on top of this
  mechanism, and it needs this manual level to exist first: a schedule is just something
  that chooses between two of these values. Worth doing, worth doing separately.
- Per-digit or per-segment dimming, which the single `~OE` net makes impossible without
  cutting traces.

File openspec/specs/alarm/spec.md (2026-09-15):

# alarm Specification

## Purpose

Defines the device's single daily alarm: an alarm time settable from the on-device menu and over the serial console, an armed state independent of that time, firing at the set time each day without re-arming, a visual signal that any button dismisses, and persistence of the alarm and 12/24-hour settings across power loss in the backup domain.

## Requirements

### Requirement: A daily alarm time can be set
The device SHALL hold a single alarm time expressed as an hour and a minute, settable from the on-device menu and over the serial console.

#### Scenario: Setting from the menu
- **WHEN** the alarm time is set through the menu and committed
- **THEN** reading the alarm back reports the hour and minute that were set

#### Scenario: Setting over serial
- **WHEN** the alarm time is set over the serial console
- **THEN** the on-device menu shows the same value

#### Scenario: Out-of-range values are rejected
- **WHEN** an hour outside 0–23 or a minute outside 0–59 is supplied over serial
- **THEN** the command reports an error and the stored alarm time is unchanged

### Requirement: The alarm can be armed and disarmed
Arming SHALL be independent of the alarm time, so the time can be set without the alarm sounding and the alarm can be disarmed without losing the time. The armed state SHALL be reflected by the bottom LED.

#### Scenario: Arming lights the indicator
- **WHEN** the alarm is armed
- **THEN** the bottom LED is lit steadily

#### Scenario: Disarming clears the indicator
- **WHEN** the alarm is disarmed
- **THEN** the bottom LED is unlit and the alarm time is retained

#### Scenario: Changing the time while armed
- **WHEN** the alarm time is changed while armed
- **THEN** the alarm remains armed and will next fire at the new time

### Requirement: The alarm fires at the set time each day
While armed, the device SHALL signal when the time of day reaches the alarm time, and SHALL do so again on subsequent days without needing to be re-armed.

#### Scenario: Firing
- **WHEN** the time of day reaches the alarm time while armed
- **THEN** the device enters the firing state

#### Scenario: Firing repeats daily
- **WHEN** an alarm has fired and been dismissed, and twenty-four hours pass
- **THEN** the alarm fires again without the user re-arming it

#### Scenario: Disarmed alarms do not fire
- **WHEN** the time of day reaches the alarm time while disarmed
- **THEN** nothing happens

### Requirement: Firing is signalled visibly and can be dismissed
The board has no sounder, so the alarm SHALL signal visually: the display flashes and the bottom LED breathes, fading smoothly up and down rather than switching on and off. Any button press SHALL dismiss it.

#### Scenario: Visual signal
- **WHEN** the alarm is firing
- **THEN** the display flashes and the bottom LED breathes, distinguishing it from the steady armed indication

#### Scenario: Breathing is smooth
- **WHEN** the bottom LED is breathing
- **THEN** its brightness changes in steps fine enough that the fade reads as continuous rather than as visible stepping

#### Scenario: Breathing respects the configured brightness
- **WHEN** the alarm breathes while the indicator brightness is set low
- **THEN** the breath peaks at the configured brightness rather than overriding it to full

#### Scenario: Any button dismisses
- **WHEN** any of the three buttons is pressed while the alarm is firing
- **THEN** the signalling stops, the display returns to showing the time, and that button press does not also act on the menu

#### Scenario: The alarm stays armed after dismissal
- **WHEN** a firing alarm is dismissed
- **THEN** the alarm remains armed for the following day

#### Scenario: Timekeeping is unaffected
- **WHEN** the alarm fires and is left signalling
- **THEN** the clock continues to keep time, and the time read back over serial is correct

#### Scenario: Firing is observable from a host
- **WHEN** the alarm is firing and the LED state is read over serial repeatedly
- **THEN** the reported bottom-LED value varies as the LED breathes, so a firing alarm can be detected without looking at the board

### Requirement: Alarm and mode settings survive power loss
The alarm time, the armed state, and the 12/24-hour mode SHALL persist across a power cycle, stored in backup domain registers held up by the coin cell. Storage SHALL NOT use the registers the RTC library reserves for its own date storage.

#### Scenario: Settings survive a power cycle
- **WHEN** the alarm is armed at a set time in 12-hour mode and power is removed and restored
- **THEN** the alarm is still armed at the same time and the display is still in 12-hour mode

#### Scenario: The date is not corrupted
- **WHEN** settings are written and the device is power cycled
- **THEN** the date read back is the date that was set, confirming the settings did not overwrite the library's reserved date registers

#### Scenario: Uninitialized backup memory is detected
- **WHEN** the device starts with backup memory that has never held settings
- **THEN** defaults are applied rather than arbitrary values being treated as settings

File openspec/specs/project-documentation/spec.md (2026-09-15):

# project-documentation Specification

## Purpose

Defines what the repository's committed documentation must assert and keep true: the current hardware revision, the MCU pin map, the USB CDC command set, commands that run as written, honest labeling of unfinished firmware behavior and toolchain version drift, clear marking of machine-specific facts, and agent-facing context that reflects the project.

## Requirements

### Requirement: Documentation states the current hardware revision
The committed documentation SHALL identify the current board revision as the one the KiCad source describes, and SHALL present superseded revisions as history rather than as the current state.

#### Scenario: Current revision matches the design files
- **WHEN** the README's stated current revision is compared with the `rev` field in `hardware/stm32-shift-display.kicad_sch`
- **THEN** they agree

#### Scenario: Earlier revision history is preserved
- **WHEN** the README is read after the correction
- **THEN** the rev 1 design narrative and the PCBWay sponsorship acknowledgement are still present, marked as prior-revision history

#### Scenario: Revision assets are reachable
- **WHEN** a reader looks for the current schematic
- **THEN** the documentation links the rev 2 schematic asset rather than only rev 1 renders

### Requirement: Documented pin map matches the firmware
Documentation of the MCU-to-peripheral pin assignments SHALL match the pin definitions in the firmware source, and SHALL name the source file as the authority.

#### Scenario: Pin map agrees with source
- **WHEN** each documented pin assignment is compared with the corresponding `#define` in `firmware/src/main.cpp`
- **THEN** every assignment agrees

#### Scenario: Authority is named
- **WHEN** a reader needs to confirm a pin assignment
- **THEN** the documentation points at the firmware defines and the KiCad schematic as the source of truth

### Requirement: Documented serial protocol matches the firmware
The documented USB CDC command set SHALL list exactly the commands the firmware registers, with their arguments, replies, and framing.

#### Scenario: Command list is complete and accurate
- **WHEN** the documented commands are compared with the `SerialCommand` objects registered in `setup()`
- **THEN** the sets match, and each documented command's argument and reply match its handler

#### Scenario: Framing is documented
- **WHEN** a reader wants to talk to the board by hand
- **THEN** the documentation states the `\r\n` terminator, the space-separated argument format, and the command buffer size

#### Scenario: Unregistered handlers are not presented as available
- **WHEN** handlers exist in the source but are never registered
- **THEN** the documentation does not list them as usable commands

### Requirement: Documented commands are executable as written
Every build, flash, monitor, and host-tool command in the documentation SHALL run as written on a machine configured per the environment setup, with no undocumented prerequisite.

#### Scenario: Commands run verbatim
- **WHEN** each documented command is copied and run from the stated directory on a configured machine
- **THEN** it executes without modification

#### Scenario: Missing prerequisites are stated, not assumed
- **WHEN** a documented command depends on a tool that is not installed by default
- **THEN** the documentation names that prerequisite and how to install it

### Requirement: Unfinished firmware behavior is labeled
The documentation SHALL distinguish firmware behavior that works today from behavior that is incomplete, so a reader is not misled by aspirational description.

#### Scenario: Incomplete areas are called out
- **WHEN** a reader looks for the state of the on-device menu and display brightness control
- **THEN** the documentation identifies them as unimplemented and names the code that would carry them

#### Scenario: Known defects are recorded
- **WHEN** a defect has been identified in committed code but not yet fixed
- **THEN** the documentation records it with enough detail to locate it in the source

### Requirement: Toolchain version drift is recorded
The documentation SHALL record where an installed tool's version differs from the format of the committed files it opens, together with the consequence of using it.

#### Scenario: KiCad version mismatch is documented
- **WHEN** a reader opens the hardware design
- **THEN** the documentation states the KiCad file-format version of the committed files, the version installed on this machine, and that saving migrates the files irreversibly

#### Scenario: Stance on migration is explicit
- **WHEN** a reader decides whether to open the hardware files
- **THEN** the documentation states that the files are deliberately left unmigrated and what to do if migration becomes necessary

### Requirement: Machine-specific facts are marked as such
Documentation SHALL distinguish facts about this particular workstation from facts about the project, so a reader on another machine knows what will not transfer.

#### Scenario: Device identifiers are attributed
- **WHEN** a specific serial device node or USB serial number appears in the documentation
- **THEN** it is identified as observed on this machine, alongside how to discover the equivalent elsewhere

### Requirement: Agent and planning context reflect the project
The repository's agent-facing context SHALL describe the project's stack, workflow, and conventions, so generated artifacts inherit them instead of re-deriving them.

#### Scenario: OpenSpec context is populated
- **WHEN** `openspec/config.yaml` is read
- **THEN** its `context` block describes the firmware stack, the host tooling, and the repository's branch and licensing conventions

#### Scenario: Agent guidance agrees with the corrected documentation
- **WHEN** `CLAUDE.md` is compared with the README and the environment setup documentation
- **THEN** they state the same hardware revision, commands, and prerequisites

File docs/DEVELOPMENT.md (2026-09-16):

# Development

How to build, flash, and talk to the STM32 Shift Clock. Every command here was run
on macOS (Darwin 25.6.0, Apple Silicon) on 2026-09-15; where something could not be
verified from a script, it says so.

## Prerequisites

| Tool | Why | Install |
| --- | --- | --- |
| [uv](https://docs.astral.sh/uv/) | installs PlatformIO and manages the Python tool environment | `curl -LsSf https://astral.sh/uv/install.sh \| sh` |
| PlatformIO Core | builds and flashes the firmware | `uv tool install platformio` |
| ST-Link probe | the only way to flash — the board has no DFU or serial bootloader path | hardware |
| KiCad 8 | *optional*, only to open `hardware/` — see [Hardware files](#hardware-files) first | [kicad.org](https://www.kicad.org/) |
| FreeCAD | *optional*, only to edit `mechanical/desk-stand.FCStd` | [freecad.org](https://www.freecad.org/) |

PlatformIO is installed as a standalone CLI rather than through the VS Code
PlatformIO IDE extension, so builds work from any terminal and from agent sessions.
`firmware/.vscode/extensions.json` still recommends the extension; installing it is
optional and independent. If you do, keep in mind it carries its own PlatformIO
copy in `~/.platformio/penv`, which can drift from the CLI one.

### Check the environment

```bash
./scripts/check-dev-env.sh
```

Reports PlatformIO, uv, the Python environment, the ST-Link, and the board's CDC
interface. It checks all of them before exiting, names the fix for anything
missing, and exits non-zero if there is a gap.

## Firmware

All PlatformIO commands work from the repo root with `-d firmware`, or from inside
`firmware/` without it.

```bash
pio run -d firmware                # build
pio run -d firmware -t upload      # build + flash over the ST-Link
pio run -d firmware -t clean       # drop build output
pio device list --serial           # find the board's CDC port
```

The first build downloads the platform, the ARM toolchain, and the libraries —
several hundred MB, a few minutes. Later builds take about 25 seconds. A successful
build reports roughly:

```
RAM:   [===       ]  31.6% (used 6476 bytes from 20480 bytes)
Flash: [======    ]  58.5% (used 38360 bytes from 65536 bytes)
```

Uploading needs the ST-Link on the SWD header. The board's default upload protocol
is already `stlink`, so no `upload_protocol` setting is needed. A good flash ends
with `** Verified OK **` and `** Resetting Target **`.

> **Do not pipe `pio run` through `tee`.** The exit status you get back is `tee`'s,
> so a failed build looks like a success. Redirect instead: `pio run > build.log 2>&1`.

### The display shift-out

The driver writes the shift registers through `BSRR` rather than `digitalWrite`. `begin()`
resolves each pin to its port and bit once and precomputes the `BSRR` words; the inner loop
is then a select and two stores, about **9 instructions per bit** against roughly 117
before. A full 48-bit refresh went from **~117 µs to ~9 µs**, a shift clock of roughly
410 kHz to about **5.3 MHz**.

> These figures were first written as 78 µs → 6.7 µs and 615 kHz → 7 MHz. That was
> arithmetic done at an assumed 72 MHz; **this board runs at 48 MHz** (`SystemCoreClock`
> reports 48000000, and `WD` prints it). 117 instructions × 48 bits ÷ 72 MHz is 78 µs
> exactly, which is how the original numbers arose. The conclusion is unchanged — no
> failure was observed at the fastest rate the loop can produce — only the rate that
> describes it.

`~OE` shares GPIOA with the data, clock, latch and clear lines and belongs to the
brightness timer, so **every write names the pins it owns**. A port-wide write
(`GPIOA->ODR = …`) would reach across it however careful the intent.

## The DMA display engine

The display refreshes itself. TIM1 and two DMA1 channels replay a precomputed waveform
into `GPIOA->BSRR`; the CPU writes content into a buffer and is otherwise uninvolved.

```
TIM1 update -> DMA1 ch5 -> GPIOA->BSRR   48 words per slice, incrementing
TIM1 CC1    -> DMA1 ch2 -> GPIOA->BSRR   one constant word (SRCLK high), no increment
```

| | | |
|---|---|---|
| Core clock | **48 MHz** | not 72; `SystemCoreClock` says so |
| Timer reload | ARR 249, CCR1 125 | derived, never written as literals |
| Bit clock | 192 kHz | `PWM_FREQ_HZ x 48`; 28x margin |
| Frame rate | 500 Hz | `PWM_FREQ_HZ / slices`; measured |
| Slices | 8 | = per-digit brightness levels |
| Buffer | 1536 bytes | `slices x 48 x 4` |
| Rebuild cost | 186 µs | the tearing window |

**Why a slice is exactly one `~OE` period.** Per-digit brightness (data path) and global
brightness (`~OE` PWM) are two modulations that multiply. Unrelated periods beat — 4 kHz
against a 1001 Hz frame is a visible 4 Hz flutter. Locked but with a slice shorter than an
`~OE` period is worse: every digit's slices land at a fixed phase and take a systematically
wrong share of the on-time, which never averages out and looks like a hardware fault. A slice
holding a whole number of `~OE` periods removes the phase term entirely. With
`PWM_FREQ_HZ` 4000 at 48 MHz it works out to exactly one: 12000 counts, 48 bits, 250 counts
per bit. Verified on hardware — six digits at 4/8, 2/8 and 6/8 with none standing out.

**The constants are derived, never written down.** `ShiftDisplayEngine.h` computes them from
`PWM_FREQ_HZ` and `SHIFT_ENGINE_CORE_CLOCK_HZ`, with `static_assert`s that fail the build if
a slice stops dividing into 48 whole bit periods, if the frame rate drops below 200 Hz, or if
the bit clock exceeds 1 MHz. Retuning the LED PWM frequency therefore breaks the build rather
than quietly skewing per-digit brightness. `F_CPU` cannot be used: on this core it expands to
the runtime `SystemCoreClock`, so `shift_engine_clock_ok()` checks it at startup instead and
the engine refuses to run — leaving the display blank — if the board disagrees.

**Falling back.** `-D SHIFT_ENGINE_DMA=0` restores the bit-banged shift-out, which stays
compiled in so a bad peripheral configuration is one rebuild from a working clock.

**Menu-exit fade.** Leaving the menu brings the six digits in one at a time from the left:
110 ms stagger, 260 ms ramp, 810 ms total, chosen by eye from five candidates. Driven from
elapsed time, so a slow loop shortens it rather than stretching it. It changes brightness
only — `render()` is untouched and the `time_dirty` path is as cheap as it ever was.

**On the rate.** Six 74HC595s on 3.3 V: the family is characterised at 4.5 V, and for a
chain this deep the limit is each stage's serial propagation delay plus the next stage's
setup time, six times over. The far end of the chain is not wired back — `U15`'s `QH'` goes
nowhere — so there is no electrical readback and a marginal rate would show up only as the
occasional wrong segment.

The rate was therefore established by measurement. Two patterns were displayed
continuously, re-shifting every pass so a marginal rate had many chances to fail:
`888888` (every segment lit, so a dropped bit shows as a gap) and `012345` (six distinct
digits, so a shifted stream shows as wrong positions — which `888888` cannot reveal, every
digit being identical).

**Result: no failure at the fastest rate the loop can produce.** The throttle constant is
therefore zero. Note what that does and does not establish: it shows ~7 MHz works on this
board, at room temperature, with these parts. It does **not** quantify the margin, because
no failure point was found to measure back from. If wrong segments ever appear, the first
thing to try is a throttle.

```
-D SHIFT_EDGE_NOPS=n   insert n NOPs between clock edges (default 0)
-D SHIFT_SWEEP         runtime-settable rate plus the SN and TP commands,
                       for re-measuring; absent from the production build
```

### Flash budget

`./scripts/check-dev-env.sh` reports usage and headroom from the last build. Note it reads a
few hundred bytes higher than PlatformIO's build line, which counts only `.text`, `.data`
and `.rodata` and omits the vector table and the init arrays — those occupy flash too.

The `reduce-flash-footprint` change took usage from **53,924 bytes (82.3%)** to **36,832
(56.2%)** as PlatformIO counts it, without altering behaviour:

| | bytes saved |
| --- | --- |
| integer date arithmetic in place of `localtime`/`mktime` | 8,788 |
| `print()` in place of `Print::printf` | 3,632 |
| link-time optimisation | 4,672 |
| **total** | **17,092** |

The `bsrr-shift-out` change later added **364 bytes** back: resolving ports and masks once
costs more state than the removed `digitalWrite` call sites saved. That change buys speed,
not size.

The first figure is the one worth understanding. `localtime()` reaches `tzset`, which reaches
`sscanf` to parse a `TZ` string this firmware never sets, which drags in the whole
formatted-input engine — and `assert` → `fprintf` hung off the same chain. Roughly 8.8 KB for
a conversion that is forty lines of integer arithmetic.

`-flto` is enabled in `platformio.ini`. It was adopted on evidence rather than by default:
it saved 4,672 bytes and the board passed the same verification as every other stage,
including the RTC seconds interrupt, which is the sort of thing LTO can quietly break.

### Why the platform version is constrained

`firmware/platformio.ini` sets `platform = ststm32@^20.0.0` — a range, not a pin. The
range holds the major line this firmware has been verified against while still accepting
20.x updates; moving to a future platform 21 is then a deliberate change with its own
hardware verification, rather than a silent jump.

Note that PlatformIO's framework *package* version is not the Arduino core version it
carries. Conflating the two is easy and was the source of an earlier misdiagnosis here:

| PlatformIO package | Arduino core (`platform.txt`) |
| --- | --- |
| `framework-arduinoststm32@4.30000.0` | **3.0.0** — current, what this builds against |
| `framework-arduinoststm32@4.21200.0` | **2.12.0** — the previously pinned line |

This project was briefly pinned to `ststm32@19.7.1` (core 2.12.0) because the build
failed against core 3.0.0. The cause was library drift, not the core:
`STM32duino RTC@1.9.0` declared its own `voidFuncPtr` as `void (*)(void*)`, colliding
with the core's `api/Common.h` `typedef void (*voidFuncPtr)(void)`. `STM32duino RTC@2.0.0`
drops that typedef and takes `voidFuncPtrParam` (`void (*)(void*)`) for
`attachSecondsInterrupt`, which is the shape `main.cpp`'s `irq_rtc_seconds(void *data)`
already had — so the upgrade needed no source change. `STM32duino Low Power` also failed
to compile against core 3.0.0 and was referenced nowhere in `src/`, `lib/`, or
`include/`, so it was removed from `lib_deps` rather than ported.

Do not try to pin *backward* to a platform contemporary with the original 2024
development. 17.x and 18.x cannot be installed at all: their framework packages
(`~4.20801.0`, `~4.20900.0`) are no longer in the registry and resolution fails with
`UnknownPackageError`. That purge is why this project tracks a current range instead of
an exact old release.

Versions resolved by the verified build:

```
ststm32@20.0.0              framework-arduinoststm32@4.30000.0 (Arduino core 3.0.0)
STM32duino RTC@2.0.0        AceButton@1.10.1
SerialCommands@2.2.0
```

Two warnings are expected and benign: `SerialCommands` uses the deprecated `boolean`
type, and `STM32RTC` emits `#warning "only BCD mode is supported"`, which is simply true
of the STM32F1 RTC.

One stale reference remains on purpose: commit `109d621`, which introduced the original
pin, describes core 3.0.0 as "Arduino core 4.x". Its message is wrong but the history is
merged, so it is left alone rather than rewritten. This section is the correct account.

## Talking to the board

The firmware exposes a command console over USB CDC. Commands are `\r\n`-terminated
with space-separated arguments, and the receive buffer is 32 bytes
(`serial_command_buffer_` in `main.cpp`).

| Command | Argument | Reply | Notes |
| --- | --- | --- | --- |
| `TEST` | — | `TEST` | liveness check |
| `GT` | — | Unix timestamp | reads the RTC, converts using the timezone offset |
| `ST` | Unix timestamp | `OK` | sets the RTC |
| `GO` | — | offset in hours | signed integer, defaults to `-6` |
| `SO` | offset in hours | `OK` | signed integer |
| `GM` | — | `12` or `24` | display hour format |
| `SM` | `12` or `24` | `OK` | display only; the RTC always runs in 24-hour format |
| `GA` | — | `hh mm armed` | alarm time and whether it is armed (`0`/`1`) |
| `SA` | `hh` `mm` | `OK` | 0–23 and 0–59; out of range is rejected and changes nothing |
| `AE` | `0` or `1` | `OK` | arm or disarm; `AE 0` also silences a firing alarm |
| `GL` | — | `top mid bot` | indicator **duty**, 0–4095 each (12-bit); lit means non-zero |
| `GI` | — | `1`–`8` | indicator brightness level |
| `SI` | `1`–`8` | `OK` | indicator brightness; out of range is rejected and changes nothing |
| `GD` | — | `level duty` | display brightness level and its duty |
| `SD` | `1`–`8` | `OK` | display brightness; out of range is rejected and changes nothing |
| `GB` | — | see below | raw settings storage, for diagnosing settings loss |

An unrecognized command replies `Unrecognized command [<cmd>]`.

`cmd_set_hour`, `cmd_set_minute`, and `cmd_set_second` are implemented in `main.cpp`
but never registered, so they are not reachable. Registering one needs a
`SerialCommand` object and an `AddCommand()` call in `setup()`.

### Interactively

```bash
pio device monitor -p /dev/cu.usbmodemXXXXXXXXXXXX -b 115200
```

This needs a real interactive terminal — it refuses to run with redirected input, so
it cannot be driven from a script or an agent session. The baud rate is ignored by
USB CDC but pyserial requires one.

### From a script

```python
import serial
with serial.Serial(port, 115200, timeout=2) as ser:
    ser.write(b"GT\r\n")
    print(ser.readline().decode().strip())
```

Verified round-trip on the attached board:

```
TEST -> 'TEST'
GT   -> '1789580671'
GO   -> '-6'
```

## Time sync

`software/timesync/` compares the board's RTC against NTP and can correct it.

```bash
cd software/timesync
uv sync                                   # create/refresh the environment
uv run python timesync.py -H              # human-readable NTP vs device vs skew
uv run python timesync.py -U              # push NTP time to the device
uv run python timesync.py --csv           # append a row to timesync.csv
uv run python timesync.py --com /dev/cu.usbmodemXXXXXXXXXXXX
```

The environment is uv-managed: `pyproject.toml` pins the dependencies, `uv.lock`
pins their resolution, and `.python-version` pins CPython 3.12.13. There is no
activation step and no `requirements.txt` — run `uv export --format requirements-txt`
if you need one for pip.

Without `--com`, the tool finds the board by USB descriptor (`0483:5740`). It exits
non-zero and names the problem when no board is attached, and when more than one is
attached it lists them and asks you to choose rather than guessing. `--com` bypasses
discovery entirely.

The timezone is hardcoded to `America/Chicago` and the script adds the DST offset
itself before sending — the firmware has no DST logic.

## Pin map

Board rev 2, from the `#define`s at the top of `firmware/src/main.cpp`. Those defines
and `hardware/stm32-shift-display.kicad_sch` are the authority; this table is a copy.

| Function | Pin | |
| --- | --- | --- |
| `SER` | `PA3` | 74HC595 serial data |
| `SRCLK` | `PA4` | 74HC595 shift clock |
| `SRCLRB` | `PA1` | 74HC595 clear, active low |
| `RCLK` | `PA2` | 74HC595 latch clock |
| `OEB` | `PA0` | 74HC595 output enable, active low |
| `LED_TOP` | `PB8` | user LED |
| `LED_MID` | `PB7` | user LED |
| `LED_BOT` | `PB6` | user LED |
| `BTN_SET` | `PB5` | button, `INPUT_PULLUP` |
| `BTN_PLUS` | `PB4` | button, `INPUT_PULLUP` |
| `BTN_MINUS` | `PB3` | button, `INPUT_PULLUP` |

The rev 2 remap put the LED and `OE` pins on PWM-capable outputs specifically to
allow brightness control. That is not implemented yet — see below.

### LEDs

The firmware's positional names run **opposite** to the schematic's D-numbering, so
cross-reference with care. All three are active high (cathodes to GND).

| Firmware | Pin | Net | Schematic | Indicates |
| --- | --- | --- | --- | --- |
| `LED_TOP` | `PB8` | `/LED3` | **D3** | AM — lit before 12:00, and only in 12-hour mode |
| `LED_MID` | `PB7` | `/LED2` | **D2** | 12-hour mode is active |
| `LED_BOT` | `PB6` | `/LED1` | **D1** | alarm armed (steady) or firing (breathing) |

The indicators are PWM-driven, not switched: PB6/PB7/PB8 are TIM4_CH1/CH2/CH3, reached
through `analogWrite()` at **12-bit** resolution (`analogWriteResolution(12)`) rather than
the core's 8-bit default. Eight bits is plenty for steady indicators but not for fading
between them — at the dim end one duty step is a large fraction of the light, so a breath
built on 256 steps visibly staircases no matter how fast it updates. "Lit" therefore means a duty,
set by the brightness level and mapped through a gamma curve so the eight levels feel
evenly spaced. A firing alarm breathes rather than blinking, peaking at the configured
brightness rather than overriding it.

Every write to those pins goes through one path. A stray `digitalWrite` would reconfigure
its pin back to plain output and silently stop the timer driving it.

`GL` reports the duty of all three over serial, which is both faster than reading them off
the board and the only reliable way to do it — `digitalRead()` on a pin the timer is
driving samples the live PWM waveform at an arbitrary phase.

Note that the generic variant defines `TIMER_SERVO TIM4`. That only matters if the Servo
library is ever used; nothing here touches a timer otherwise.

### Display brightness

The shift registers' `~OE` line is PWM-driven from PA0 (TIM2_CH1), so brightness applies to
all six digits at once — it is a single net across all six registers, which is also why
per-digit dimming is not possible.

`~OE` belongs to `ShiftDisplay`, which owns the pin and the **active-low inversion**: `~OE`
high blanks the outputs, so the duty written to the pin is the complement of the
brightness. `enable()` and `disable()` are brightness operations, not pin writes, and
`enable()` restores the configured level rather than going to full. Nothing else may write
PA0 — a `digitalWrite` would reconfigure it away from the timer and blank the display.

`analogWrite`'s resolution and frequency are **global**, shared by the indicator LEDs on
TIM4 and the display on TIM2. Both are set once in `setup()`: 12-bit at 4 kHz. 1 kHz would
likely do, but a bright source at low duty seen at the edge of vision is where PWM flicker
gets noticed. 4 kHz costs nothing — the timer reload is about 18,000 counts against 4,096
duty steps, so resolution is untouched; it would only suffer above roughly 17 kHz.

The alarm flash and the field-edit blink stay buffer-based rather than moving to `~OE`.
The field blink has to blank one field and `~OE` is all-or-nothing, so moving only the
alarm would leave two blanking mechanisms for one idea. `~OE` means brightness and nothing
else.

### Menu

Click **SET** from the clock to open the menu. **PLUS**/**MINUS** scroll and wrap;
**SET** enters an entry; **holding SET** backs out one level without saving. Ten
seconds without a press returns to the clock, discarding anything uncommitted.

| Entry | Shown | Fields |
| --- | --- | --- |
| Clock | `CLOC` | hours, minutes, seconds |
| Date | `DAtE` | day, month, year |
| Hour format | `12-24` | `12Hr` / `24Hr` |
| Alarm | `ALArn` | hour, minute, `On`/`OFF` |
| Indicator brightness | `LEd` | level 1–8, previewed live on the LEDs |
| Display brightness | `dISP` | level 1–8, previewed live on the display itself |

Inside an editor the field being edited blinks. PLUS/MINUS adjust it and wrap at the
field's limits; holding either repeats. SET advances to the next field and commits
after the last, returning to the clock.

A firing alarm flashes the whole display and blinks D1 until any button is pressed —
or until `AE 0` disarms it from a host.

### Diagnosing settings loss

`GB` reports the backup registers twice over:

```
boot:C10C 0003 032F 0206 now:C10C 0003 032F 0206 expect_magic:C10C
      magic flags alarm bright
```

The `boot:` values are what `settings_load()` read at start-up, captured before anything
could overwrite them; `now:` is what the registers hold at the time of the query.

The distinction matters because the two ways settings can vanish look identical afterwards.
If the backup domain failed to retain, `boot:` shows a bad magic and zeroed registers. If
the firmware misread the magic and took the uninitialised branch, it rewrote defaults over
good values — and every later boot then reads a *valid* magic with default contents, hiding
the cause completely. Only the start-up capture separates them.

It exists because settings were twice reported as returning to defaults without either
instance reproducing. A controlled power cycle with distinctive values in all four settings,
both cables out, preserved everything including the clock — so the cause is still unknown,
and this is the instrument for catching it next time.

### Settings storage

12/24-hour mode, the alarm time, the armed flag and the indicator brightness live in
backup-domain registers on VBAT, so they survive a power cut exactly as the time does.
**DR2, DR3, DR5 and DR8** are used; a magic value in DR2 distinguishes configured backup
memory from a fresh coin cell. DR8 holds both brightness levels: the indicator level in
the low byte, stored as-is, and the display level in the high byte, stored **offset by
one** so that zero means "never written". The low byte shipped first with the high byte
zeroed, and storing the display level raw would make that indistinguishable from a
deliberate level 0 — the dimmest — so devices already in the field would come up looking
blank.

Most of the backup domain is already claimed and must not be reused: the core takes
**DR1** (`RTC_BKP_INDEX`), **DR4** (`HID_MAGIC_NUMBER_BKP_INDEX`) and **DR10** in
`backup.h`, and STM32RTC stores the F1's emulated date across **DR6 and DR7**
(`RTC_BKP_DATE`). Writing the date registers would surface as a clock bug rather than
a settings bug. Access goes through the core's `getBackupRegister`/`setBackupRegister`
from `backup.h`; STM32RTC's own helpers are internal to `rtc.c`.

## Hardware files

`hardware/` is in **KiCad 8** format: the schematic is `version 20231120` and the
board is `version 20240108`. Opening them in a newer KiCad and saving migrates them
irreversibly, with a large diff against a design that is already fabricated and
assembled.

These files are deliberately left unmigrated. Nothing in the firmware work needs
them edited. If a hardware change ever becomes necessary: branch first, migrate
deliberately, and commit the format migration on its own so it can be reviewed
separately from the design change.

The machine this was last set up on has KiCad 10.0.3 installed, which will migrate
on save.

**Known inconsistency:** the current board is rev 2, but the sources disagree about
that and all of them describe the same physical board — the schematic and
`STM32ShiftDisplayRev2.pdf` say rev 2, while `stm32-shift-display.kicad_pcb`'s title
block and the photo/model assets (`rev1.jpg`, `stm32-shift-display_rev1.step`) say
rev 1. The README has the full mapping. Correcting the `.kicad_pcb` field means
opening the board in KiCad, so it is left for whenever the hardware is next touched.

`mechanical/desk-stand.FCStd` needs FreeCAD, which is not installed on this machine.
`desk-stand-Body.step` and `desk-stand.xhtml` are exports that need no FreeCAD to view.

## Known defects

Verified in the current source and deliberately **not** fixed by the environment pass,
so that "the unchanged firmware still builds and flashes" stayed a usable signal:

- **`timesync.py` writes the clock without `-U`.** The guard is
  `abs(skew) > 1 & args.update`, which binds as `abs(skew) > (1 & args.update)`. With
  `-U` absent that is `abs(skew) > 0`, so any nonzero skew triggers a write. Running
  what looks like a read-only `-H` will set the device clock.
- **A bad `--com` port raises `UnboundLocalError`.** `get_device_time()` and
  `set_device_time()` reference `ser` in their `finally` blocks, which is unbound when
  `serial.Serial()` itself raises, masking the real `SerialException`.
- **No DST on the device.** The timezone offset is applied as a fixed number of seconds
  either side of the date conversion. The host script compensates; anything else talking
  to the board does not.

### Fixed, and what the old description got wrong

The month *was* recorded here as "off by one over the wire — `ST` followed by `GT` does not
round-trip the date". That description was wrong in an interesting way: `ST` → `GT` always
round-tripped, verified across ten timestamps including leap days and year boundaries. The
same offset was applied on both sides, so the serial path was self-consistent.

The actual fault was that the two paths which set the month disagreed with *each other* —
`ST` stored 0–11, the menu editor stored 1–12 — so a date set in one place read back a month
out in the other, while any test confined to a single path looked perfect. That is also why
`timesync` reporting zero skew never revealed it.

Month is now 1–12 everywhere, converted only where a `tm`-shaped value is produced.

## Unimplemented

- **Brightness.** The `OE` line is on a PWM-capable pin and `irq_timer_led()` exists to
  toggle it, but the `HardwareTimer` setup in `setup_user_leds()` is commented out and
  nothing calls the ISR.
- **`lib/ShiftClock`** is a standalone software clock, superseded by `STM32RTC` and
  referenced by nothing.

## This machine

Facts specific to the Mac this was set up on — they will differ elsewhere. Use
`pio device list --serial` or `./scripts/check-dev-env.sh` to find the equivalents.

| | |
| --- | --- |
| Board CDC | `/dev/cu.usbmodem49795F7330551` — USB `0483:5740`, serial `49795F733055`, "GENERIC_F103C8TX CDC in FS Mode" |
| ST-Link | `/dev/cu.usbmodem14102` — USB `0483:3752`, serial `0673FF373841423043111349` |
| PlatformIO | Core 6.2.0 at `~/.local/bin/pio` (uv tool install) |
| Python | CPython 3.12.13 via pyenv; uv 0.11.12 |
| KiCad | 10.0.3 |

The USB vendor id `0483` is shared by the board and the ST-Link; they differ by
product id, which is why port discovery matches on both.

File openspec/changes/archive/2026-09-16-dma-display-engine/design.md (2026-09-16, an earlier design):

## Context

The display is driven by six daisy-chained 74HC595s on a single 48-bit chain. Since
`bsrr-shift-out`, the CPU clocks all 48 bits out by hand — two stores per bit into
`GPIOA->BSRR`, roughly 100 stores per redraw — and it does this only when `time_dirty`
says something changed. Brightness comes from TIM2 PWM on `~OE` (PA0), which is one net
across all six registers, so it dims every digit together.

The pins are all on GPIOA:

```
  PA0  ~OE     TIM2_CH1, PWM brightness  -- NOT ours to write
  PA1  ~SRCLR  active low
  PA2  RCLK    latch
  PA3  SER     data
  PA4  SRCLK   bit clock
```

Two constraints follow from that map and shape everything below.

**There is no byte-oriented peripheral available.** SPI1 is SCK/MOSI on PA5/PA7; the
remap puts it on PB3/PB4/PB5, which are the three buttons. `SER` and `SRCLK` are on PA3
and PA4, which are SPI1_NSS and nothing. The board wires the shift registers to plain
GPIO, so the waveform has to be synthesized edge by edge. That is the single fact that
makes this change expensive rather than trivial — an SPI-wired board would need a
16-word buffer and one DMA channel.

**`~OE` shares the port.** Every word the DMA writes to `GPIOA->BSRR` is a word that
could reach across PA0 and blank the display or fight TIM2 for the pin. The existing
"address only the pins you own" rule now has to hold for words computed at build time
and replayed by a peripheral, where nothing in the instruction stream shows the mistake.

## Goals / Non-Goals

**Goals:**

- Refresh the display continuously from a peripheral, with the CPU uninvolved.
- Make per-digit brightness possible by modulating the data rather than `~OE`.
- Set the bit clock to an exact, chosen frequency rather than an emergent one.
- Leave global `~OE` brightness working exactly as it does today.
- Demonstrate per-digit brightness with one visible behaviour: returning from the menu
  fades the digits in, left to right.

**Non-Goals:**

- Per-*segment* brightness. The mechanism allows it; nothing asks for it yet.
- Replacing `analogWrite` on `~OE`. TIM2 keeps the pin.
- Changing what the display shows. Only how brightly individual digits show it.
- Dimming the leading hour digit in 12-hour mode. The proposal named this as the first
  use; it has since been dropped. `blank-leading-hour-zero` shipped the blank, the blank
  is the better result, and it is now a `clock-ui` requirement. This change leaves it
  alone.

## Decisions

### Two DMA channels, not one

The obvious construction is one channel and one word per edge: 96 words per pass over
the chain. Half of those words are the same constant — `SRCLK` high — because the rising
edge carries no data.

So: two channels off the same timer, both writing `GPIOA->BSRR`.

| | Trigger | DMA1 ch | Memory increment | Writes |
|---|---|---|---|---|
| Data | TIM1_CH1 compare | 2 | **on** | `SER` set-or-clear \| `SRCLK` clear |
| Clock | TIM1_CH2 compare | 3 | **off** | `SRCLK` set (one constant word) |

The clock channel reads the same word forever, so it costs four bytes regardless of
buffer length. That halves the waveform to **48 words per slice**.

*Alternative considered:* one channel, 96 words per slice. Simpler to reason about and
one less peripheral to configure, but it doubles the buffer — the dominant cost of this
whole change — to save a channel that is otherwise idle. Rejected.

### Latch the previous slice, so latching costs nothing

`RCLK` has to pulse once per 48 bits. Appending latch words to the stream does not work:
the clock channel keeps firing during them, and extra clocks push data off the end of a
chain that is exactly as long as the data.

Instead the `RCLK` bits ride inside the data words. Word 0 of each slice carries
`RCLK` set alongside its data bit; word 1 carries `RCLK` clear. The rising edge at the
start of slice *k+1* latches what slice *k* shifted in.

```
   slice k        slice k+1      slice k+2
  [48 words]     [48 words]     [48 words]
   |              |              |
   |              RCLK^          RCLK^      <- latches the PREVIOUS slice
   |              shows slice k  shows k+1
```

The display runs one slice behind. The stream is circular and never ends, so "one slice
behind" is not a state anything can observe — at 500 Hz it is 2 ms of constant offset.

*Alternative considered:* a third DMA channel on TIM1_CH3 (DMA1 ch 6) pulsing `RCLK`.
More moving parts, another channel, another compare to phase correctly, for a problem
that two spare bits in an existing word already solve.

### The slice period is exactly one `~OE` PWM period

This is the decision that makes the two brightness mechanisms compose instead of fight,
and it is worth stating why the obvious alternatives are worse.

Data-path dimming and `~OE` dimming are two modulations multiplying. If their periods
are unrelated, the phase between them drifts, and any near-coincidence of harmonics
produces a slow beat — 4 kHz `~OE` against a 1001 Hz frame rate gives a visible 4 Hz
flutter. If they are locked but a slice spans only a fraction of an `~OE` period, each
digit's slices land at a fixed `~OE` phase and get a systematically wrong share of the
on-time — a per-digit brightness error that never averages out, which is worse than
flutter because it looks like a hardware fault.

Both problems disappear if **a slice contains a whole number of `~OE` periods**. Then
every slice carries exactly the same `~OE` on-time, whatever the phase, and a digit lit
in *k* of *N* slices is exactly *k/N* as bright. No phase term survives.

The arithmetic lands on one period exactly, which is a pleasant accident of the existing
constants:

```
  ~OE:  4 kHz from TIM2 at 48 MHz          -> 12000 counts per period
  TIM1: ARR+1 = 250, two compares per bit  ->   250 counts per bit
        48 bits per slice                  -> 12000 counts per slice
                                              ^^^^^ equal
```

**48 MHz, not 72.** This was written first at 72 MHz, which is what an F103 is usually
assumed to run at; the board reports `SystemCoreClock == 48000000`, and the runtime guard
found it before any peripheral was configured — the first flashed build answered `clkok=0`.
It also means `docs/DEVELOPMENT.md`'s shift-rate figures from `bsrr-shift-out` were 72 MHz
arithmetic and about 1.5x optimistic; corrected there.

Less changes than it looks. The bit clock is `PWM_FREQ_HZ x 48` and the frame rate is
`PWM_FREQ_HZ / slices`, both independent of the core clock, so both survive untouched. Only
the reload and compare move — 374/187 becomes 249/125 — and the lock survives because
48000000 / 4000 = 12000 still divides by 48 exactly.

So with **TIM1 ARR = 249** (250 counts), CH1 compare near 0 and CH2 near 125:

- bit clock **192 kHz** — a 28x margin under the ~5.3 MHz `bsrr-shift-out` ran at without
  failure, and that 5.3 MHz is itself only a floor on the true limit, since no failure
  point was found to measure back from
- slice **250 µs**, exactly one `~OE` period
- frame **500 Hz** at N = 8 slices, comfortably flicker-free

Both timers count from the same 72 MHz, so the relationship is exact and permanent
rather than nominal.

**Measured, and it moved two arguments** (task 3.3/3.4). A CPU replay of the finished
waveform, writing exactly the words the DMA will, runs one 8-slice frame in **111 µs** —
9,011 frames/second flat out, a 3.46 MHz bit clock, reproducible to 1 µs across runs.

That is 18x the 500 Hz the engine targets, and it is why the replay showed no flicker at
all. Sustaining the target 500 Hz from the CPU would cost **5.5% of it**, not the whole
loop. The proposal's framing — "doing that from the CPU means spending the loop on it
forever" — is wrong, and the honest case for DMA is narrower: exact jitter-free timing that
does not depend on what else the loop is doing, and CPU attention that does not have to be
budgeted at all. Both are real. Neither is "the CPU cannot do this."

**And the uniformity result does not validate the lock.** At 111 µs per frame a whole frame
fits inside one 250 µs `~OE` period, so a replay slice is 13.9 µs — 5.5% of an `~OE`
period, exactly the fraction-of-a-period case described above as the bad one. Six digits at
4/8 nevertheless looked uniform, because the CPU replay is **free-running**: nothing locks
it to `~OE`, the phase drifts continuously, and over the eye's integration time the error
averages away. The DMA will avoid the same problem by the opposite means, locking so that
the error never arises. Two mechanisms, same outcome — so uniformity under replay is
evidence that per-digit dimming works, and no evidence at all about the lock. That stays
unverified until the engine runs at 500 Hz.

The consequence for the code: these numbers must be **derived from `PWM_FREQ_HZ` and the
core clock at build time, not written down**. Someone re-tuning `~OE` frequency for the
LEDs would otherwise silently break the lock, and the symptom would be a per-digit
brightness error nobody would connect to the edit.

One wrinkle found in implementation (task 2.1): **`F_CPU` on this core expands to
`SystemCoreClock`, a runtime variable**, so nothing derived from it is a constant expression
and none of this could have been checked at build time. The core clock is therefore a
declared constant, `SHIFT_ENGINE_CORE_CLOCK_HZ`, with everything else derived from it and
`PWM_FREQ_HZ`; `shift_engine_clock_ok()` checks the running system against it before the
engine is allowed to start. It is the one relationship that has to be verified at runtime,
and it is verified rather than assumed.

### N = 8 slices

Buffer size is `N × 48 × 4` bytes.

| N | Buffer | Frame rate | Brightness steps |
|---|---|---|---|
| 4 | 768 B | 1000 Hz | 4 |
| **8** | **1536 B** | **500 Hz** | **8** |
| 16 | 3072 B | 250 Hz | 16 |

8 is the pick: 1536 B is 7.5% of RAM, taking the build from 4,920 to about 6,456 bytes
(24% → 32%), and 500 Hz is well clear of flicker. 16 doubles the cost and drops the frame
rate to where flicker starts being arguable at the edge of vision. 4 keeps the frame rate
high and the cost low, and is the fallback if 1536 B turns out to be wanted elsewhere; it
is not the default only because four levels is a thin range to demonstrate the mechanism
with.

Note this is a *linear* 8-step scale, not the gamma-mapped 8 the `~OE` levels use. Per-digit
levels will bunch at the top perceptually. That is acceptable for relative dimming of one
digit against the others; it is not a second user-facing brightness control.
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

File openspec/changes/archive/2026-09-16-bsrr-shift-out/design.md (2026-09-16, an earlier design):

## Context

`shiftOutByte` calls `digitalWrite` three times per bit. The disassembly of the shipped
image shows what each call costs: a bounds check, two table lookups, bitfield extraction to
recover the port and pin mask, and finally one `str` to `BSRR`. About 35 cycles to reach a
single-cycle store, and the answer is identical every time — the pins are fixed at
construction.

```
per bit   3 × bl digitalWrite  ~105 cycles
          3 × _delay_us checks   always zero, never taken
          loop overhead
                              ≈ 117 cycles
48 bits                       ≈ 5,600 cycles ≈ 78 µs   (~615 kHz shift clock)
```

Two facts shape the rewrite.

**The pins share a port.** `~OE` PA0, `~SRCLR` PA1, `RCLK` PA2, `SER` PA3, `SRCLK` PA4 are
all GPIOA. That is what makes one `BSRR` write able to present a data bit and drop the
clock together — and it is also why the driver must never write the port as a whole, since
`~OE` is in alternate-function mode under TIM2 and belongs to the brightness control.

**The parts are the limit, not the CPU.** Six 74HC595s on 3.3 V. The HC family is
characterised at 4.5 V, and for a daisy chain the binding constraint is not the rated
`fmax` but the serial propagation delay of each stage plus the next stage's setup time,
repeated six times. An unthrottled `BSRR` loop would clock at roughly 9–12 MHz, which is
plausibly at or past that edge.

And there is no way to check electrically: **`U15`'s `QH'` is unconnected**, so the far end
of the chain returns nothing. Correctness is confirmed by eye or not at all.

## Goals / Non-Goals

**Goals:**
- Replace the per-bit `digitalWrite` calls with direct `BSRR` writes.
- Establish the safe shift rate by measurement on this board, and record it.
- Leave everything the display shows exactly as it is.

**Non-Goals:**
- Timer + DMA, which is `dma-display-engine` and a different idea.
- Per-digit brightness, which needs that engine.
- Blanking the leading hour digit, which needs none of this.
- Hardware SPI, which cannot reach these pins.

## Decisions
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

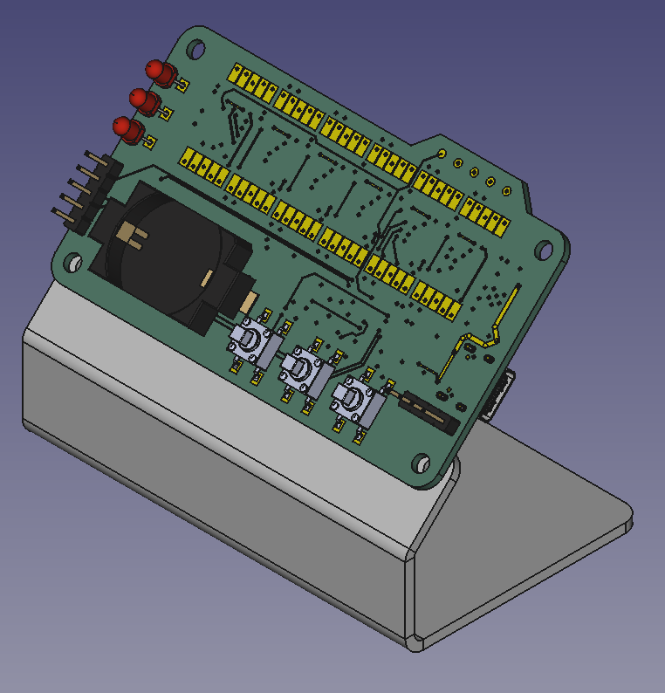
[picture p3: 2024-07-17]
hardware/assets/board-and-stand-render.png

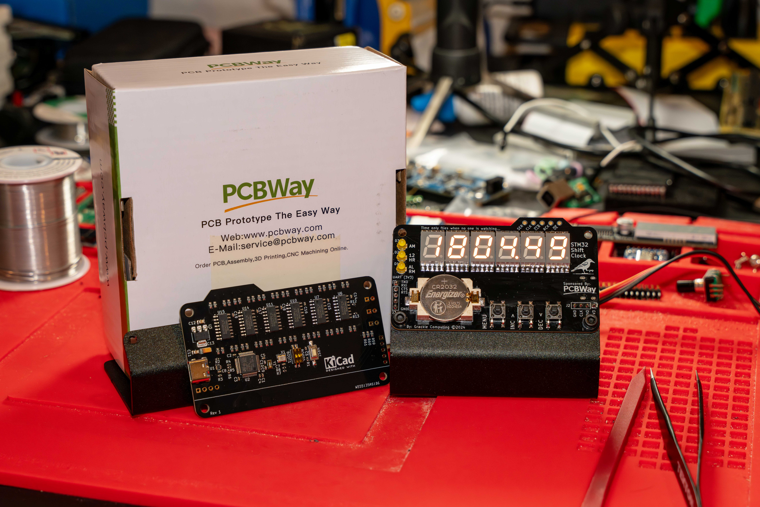
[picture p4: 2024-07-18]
hardware/assets/board_both_sides_rev1.jpg

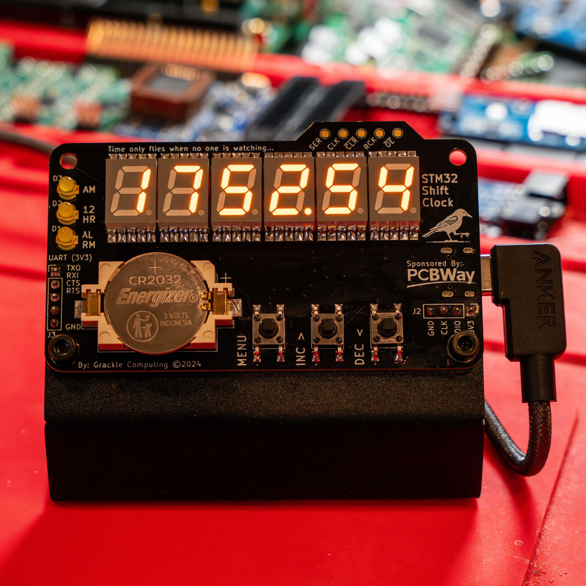
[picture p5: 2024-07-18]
hardware/assets/board_and_stand_rev1.jpg

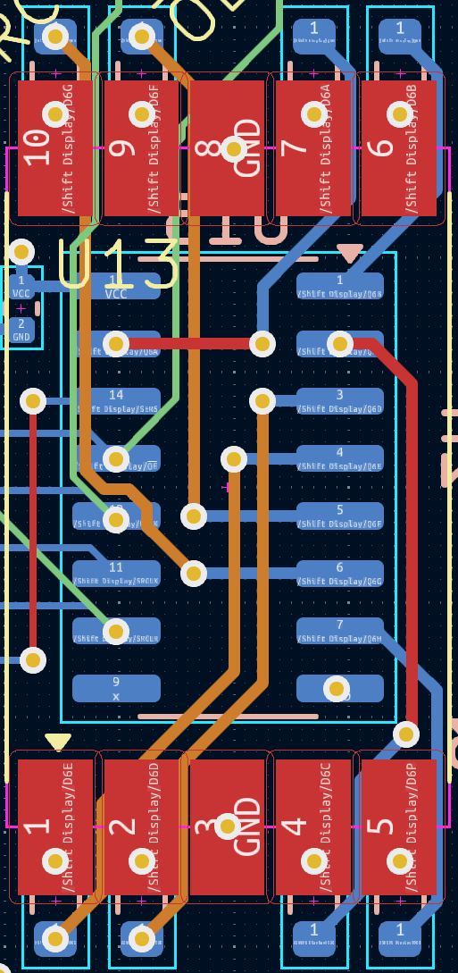
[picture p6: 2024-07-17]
hardware/assets/via-in-pad.PNG

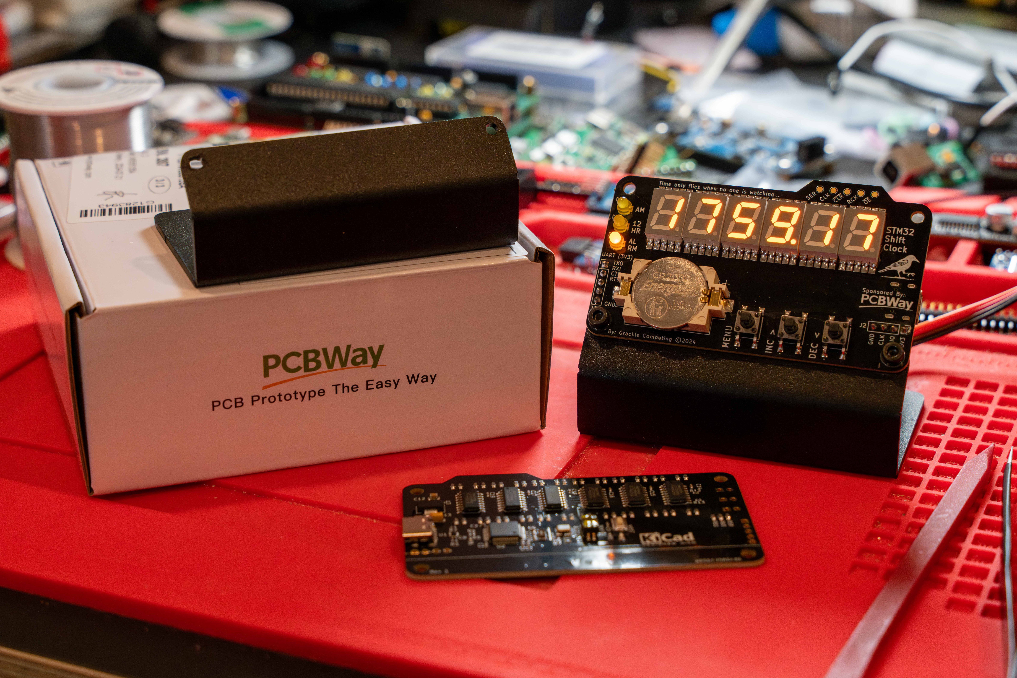
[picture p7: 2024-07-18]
hardware/assets/board_full_stand_rev1.jpg

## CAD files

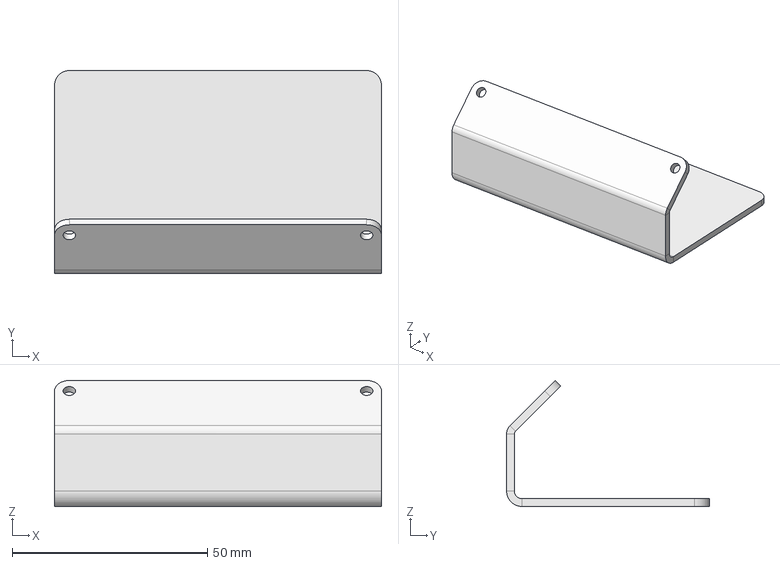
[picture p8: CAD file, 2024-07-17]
mechanical/desk-stand-Body.step
83.8 x 52.0 x 32.3 mm

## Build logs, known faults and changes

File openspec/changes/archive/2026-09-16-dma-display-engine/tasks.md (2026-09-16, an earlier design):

## 1. Settle the unknowns before writing any code

- [x] 1.1 Determine whether the Arduino core claims TIM1 for the HAL timebase, tone or servo; if it does, switch the design to TIM3 (CH3 → DMA1 ch 2, CH4 → DMA1 ch 3) and record which timer was chosen and why. *It does not — every TIM1 reference is generic dispatch. The variant names TIM3 `TIMER_TONE` and TIM4 `TIMER_SERVO`, so TIM1 stays the choice and TIM3 is a costlier fallback than assumed. Recorded in design.md.*
- [x] 1.2 Confirm DMA1 channels 2 and 3 are unclaimed in the current image, the same way the proposal confirmed all seven were — by symbol, not by assumption. *Both DMA1 literals in the image are in `HAL_UART_IRQHandler`; the console is USB CDC, so no channel is configured.*
- [x] 1.3 Confirm nothing else in the build calls `analogWriteFrequency` after `setup()`, since the slice lock depends on the output-enable frequency not moving. *Called exactly once, `main.cpp:263`, before `display.begin()`.*
- [x] 1.4 Record the baseline flash and RAM figures, and correct the stale block in `docs/DEVELOPMENT.md` that still quotes the pre-flash-reduction numbers. *Baseline RAM 4,920 / 20,480 and Flash 37,220 / 65,536; docs corrected from 5052 / 47348.*

## 2. Derive the constants

- [x] 2.1 Express the timer reload, the compare values and the slice length as expressions over `PWM_FREQ_HZ` and the core clock, so none of them is an independent literal. *`ShiftDisplayEngine.h`. `F_CPU` turned out to be the runtime `SystemCoreClock`, so the core clock is a declared constant checked at runtime by `shift_engine_clock_ok()`; everything else derives.*
- [x] 2.2 Add a static assertion that the slice period is an exact whole number of output-enable periods, so retuning the PWM frequency fails the build rather than producing per-digit brightness errors. *Verified to bite: `PWM_FREQ_HZ` 7000 fails the divides-the-clock assert, 3600 fails the divides-into-48 assert, 32 slices fails the 200 Hz flicker floor, 12 slices fails the power-of-two check.*
- [x] 2.3 Add a static assertion that no constructed word can set or clear bit 0 or bit 16 of the port, so nothing replayed by the DMA can reach `~OE`. *Two layers, because the masks resolve at runtime: a `static_assert` in main.cpp that the five pin defines are distinct (verified to fail when OEB is aliased onto SER), and `ShiftDisplay::oe_collides()` in `begin()` proving no driven pin shares a port bit with `~OE` — the driver refuses to initialise if one does. Checking the four masks once is equivalent to checking every word, since every word is composed from them.*
- [x] 2.4 Confirm the derived bit clock against the rate measured in `bsrr-shift-out`, and record the margin. *192 kHz against ~7 MHz: a 36x margin, and the 7 MHz is a floor rather than a measured limit. A `static_assert` caps the derived bit clock at 1 MHz.*

## 3. Build the waveform, with the engine stopped

- [x] 3.1 Add the buffer and the word builder: one data word per bit, `SER` set-or-clear with `SRCLK` low, and the `RCLK` set/clear bits in words 0 and 1 of each slice. *`build_waveform()`. Bit order matches `update_display()`/`shiftOutByte()` exactly — bytes `_buffer[5]`..`_buffer[0]`, LSB first, DP in bit 0. Verified from the device: `w0=00180004` (clear SER|SRCLK, set RCLK), `w1` releases RCLK, `w2+` carry no latch bits, and no word sets bit 0 or 16.*
- [x] 3.2 Add the single constant clock-high word the second channel will replay. *`_clk_high_word`, a member so the DMA channel has a source address.*
- [x] 3.3 Render the current display buffer into one slice and shift that slice out through the *existing* bit-banged path; confirm the display is identical to today. *Confirmed on hardware at 12:34:56 in 24-hour mode — correct digits, nothing garbled.*
- [x] 3.4 Confirm the latch-the-previous-slice arrangement produces the right content when slices are shifted back to back, still by hand. *Confirmed — content in the right positions, not shifted by one. Per-digit dimming also works: a single digit steps visibly dimmer, a 1-2-3-4-6-8 gradient reads as a ramp, and a hand-driven fade read as a flourish rather than as steps.*

## 4. Start the engine

- [x] 4.1 Put the existing bit-banged path behind a build flag, so a bad configuration is one rebuild from a working clock. *`SHIFT_ENGINE_DMA`, default 1; `-D SHIFT_ENGINE_DMA=0` restores the bit-banged shift-out. `WE 0`/`WE 1` also swap them at runtime in the verify build.*
- [x] 4.2 Configure the timer: reload, the two compare channels, and DMA requests enabled on both. *Changed from the design: data rides the **update** event rather than CH1, because CH1 would need `CCR1 = 0` — a compare coinciding with the counter wrap, an edge case not worth betting a hard-to-debug peripheral on. Update *is* the wrap. So TIM1 update → DMA1 ch5 and TIM1 CC1 (at mid-period) → DMA1 ch2; both channels equally free.*
- [x] 4.3 Configure the data channel — memory-to-peripheral, 32-bit both ends, memory increment on, circular, destination `GPIOA->BSRR`. *DMA1 ch5. Verified live: CNDTR counts down and reloads.*
- [x] 4.4 Configure the clock channel — same, but memory increment off, pointed at the single constant word. *DMA1 ch2, source `_clk_high_word`.*
- [x] 4.5 Start with every digit at full brightness in every slice; confirm the display is indistinguishable from the bit-banged build. *Confirmed on hardware — "it looks correct". Measured frame rate 500 Hz exactly across three runs, counted from CNDTR reloads, matching the derived target.*
- [x] 4.6 Confirm the CPU is genuinely out of it: hold the main loop busy for longer than a frame and confirm the display does not flicker, dim or corrupt. *Confirmed: a 1-2-3-4-6-8 per-digit gradient held steady through 5 s with the main loop unable to execute an instruction. The first version of this test was weak — the display is non-multiplexed, so the 595s hold their last latch and a blocked loop leaves any build lit and frozen. A **dimmed** digit is the discriminating case, since it exists only while something re-shifts continuously.*
- [x] 4.7 Confirm the display is blank before the engine starts and through reset, rather than showing whatever the registers powered up holding. *Confirmed over two software resets — dark, then the time, with no flash of garbage. The ordering that guarantees it: `~OE` pulled up by 10k at reset, `begin()` sets duty 0, the engine starts against an all-spaces buffer, and brightness comes up only afterwards.*

## 5. Rework the driver's entry points

- [x] 5.1 Make `writeDisplay()` and the `Print` path write the waveform buffer rather than shift; confirm content appears within one frame with no caller latching anything. *`writeDisplay()` skips the shift loop under the engine. The `Print` path needed real work: `shiftOutByte()` declines to fight the engine for the pins, so `print()` would have returned success and displayed nothing. It now moves the buffer along instead, carrying the decimal points, reproducing the streaming model.*
- [x] 5.2 Decide what `latch()` means now that latching is continuous, and either keep it as a no-op with a comment or remove it, having checked every caller. *Kept as a guarded no-op. Removing it would break the bit-banged fallback, which is the whole point of keeping that path compiled in. Only caller is `display_write()`, on the non-engine branch.*
- [x] 5.3 Rework `clear()` — the `~SRCLR` pulse no longer persists, since the next frame overwrites it — and find every caller relying on the old semantics. *No live callers: `clear()` is called nowhere, and its one call inside `write()` was already commented out. Reworked anyway so it means the same thing in both modes — it now clears the buffer, with the `~SRCLR` pulse retained on the bit-banged path to make that immediate. Previously it emptied the registers while leaving `_buffer` stale.*
- [x] 5.4 Confirm `enable()`/`disable()` still work, since they are `~OE` operations and should be untouched by any of this. *Confirmed — the display stepped visibly across five levels, and `SD`/`GD` round-trip the gamma table (1→128, 3→546, 5→1529, 8→4095). Only caller of `enable()`/`disable()` is `irq_timer_led()`, which is documented as unused.*
- [x] 5.5 Confirm a mid-frame buffer rewrite produces at most one torn frame and nothing worse. *Confirmed under a torture test rebuilding the waveform ~5,400x/second beneath an actively reading DMA channel — nothing worse than momentary flicker. Each word is a single aligned 32-bit store, so no partially written word can be read. Rebuild cost measured at 254 µs, then cut to 186 µs by hoisting the latch placement out of the per-word loop; that duration is the tearing window, so it was worth shortening.*

## 6. Per-digit brightness

- [x] 6.1 Add a per-position slice count, defaulting to full, and render each slice according to it. *`_digit_levels[]`, seeded full in `begin()`; `build_waveform()` lights a digit in slices 0..level-1.*
- [x] 6.2 Confirm a single dimmed digit is visibly dimmer and still legible, with the others unaffected. *Confirmed under the engine.*
- [x] 6.3 Confirm zero slices blanks a position and leaves the others alone. *Confirmed.*
- [x] 6.4 Confirm equal slice counts on different positions look equally bright — the check that the slice/output-enable lock actually holds. **Done under the DMA engine, not the replay.** *Confirmed at 4/8, 2/8 and 6/8 — no position stood out. This is the design's central claim and the one thing that could not be established by reasoning: because the engine is phase-locked, a slice not spanning a whole `~OE` period would give each digit a fixed, non-averaging share of the on-time. 2/8 is the exposed case, a quarter of the digit's light.*
- [x] 6.5 Watch a dimmed digit for a spell at several global brightness levels, looking for beat or shimmer that is not commanded. *Confirmed — one digit at 3/8 held 7 s at each of global 8, 6, 4, 2, 1. No beat.*
- [x] 6.6 Confirm the global brightness setting still dims everything together and keeps the relative proportions, and that a digit at full relative brightness is no brighter than the global minimum allows. *Confirmed both ways.*

## 7. The menu-exit fade

- [x] 7.1 Add the transition detection: compare the state either side of `stateMachine.update()` and recognise `MENU`/`EDIT` → `IDLE`, so backing out, committing and timing out all trigger alike. *Confirmed on the buttons after the self-abort fix.*
- [x] 7.2 Confirm `FIRING` → `IDLE` does not trigger it — dismissing an alarm shows the time at once. *Confirmed with a real alarm: levels held 8 8 8 8 8 8 through firing and dismissal.*
- [x] 7.3 Add the fade stepper as its own call in the loop tail alongside `update_leds()`, driven from `millis()` against a start stamp rather than by counting steps.
- [x] 7.4 Confirm `render()` is untouched and nothing is re-shifted for the fade; the `time_dirty` path must stay exactly as cheap as it is. *`render()` is unmodified. The fade moves per-digit levels, which are independent of the character buffer.*
- [x] 7.5 Wire the per-position ramp: position *p* starts at `p × STAGGER` and reaches full over `FADE`.
- [x] 7.6 Add the abort: any button press, menu re-entry or alarm fire snaps every position to full immediately. *Confirmed on the buttons. Needed a fix first: the abort also fired on the pass that started the fade, because leaving the menu is **caused** by a button and the button states are not cleared until the end of the loop. The fade aborted itself instantly on every route out of the menu — and `WF` hid it completely, since no button is involved in a serial trigger.*
- [x] 7.7 Add a build-flagged serial command to trigger the fade without walking the menu, so it can be watched repeatedly; confirm it is absent from the production image. *`WF`, optionally taking stagger and ramp so the timings could be compared live rather than one reflash per candidate.*
- [x] 7.8 Watch the fade and judge whether 8 levels reads as a flourish or as steps. If it steps, work the remedies in the design's order — the global `~OE` ramp first, since it costs no RAM and buys more than more slices do — and record which was needed and why. *It reads as a flourish. **No remedy was needed**, and the choice of timing is the evidence: of five candidates the slowest was preferred, where visible stepping would have made the slowest the worst.*
- [x] 7.9 Confirm the fade ends at the configured brightness at every level including the minimum, and that a digit is never left dim by any exit path. *Confirmed at global 8, 5, 3 and 1; levels returned to full every time.*
- [x] 7.10 Confirm the blanked leading position stays blank throughout in 12-hour mode, and that the remaining digits keep their timing. *Confirmed at 09:34 in 12-hour mode — the blank position keeps its slot in the rhythm and lights nothing.*
- [x] 7.11 Hold the loop busy mid-fade and confirm the fade shortens rather than stretching. *Confirmed — fade triggered then the loop blocked 1 s; it completed on schedule rather than resuming where it left off.*
- [x] 7.12 Tune `STAGGER` and `FADE` by eye from the 70 ms / 180 ms starting point, and record the values chosen. ***110 ms stagger / 260 ms ramp, 810 ms total***, chosen from five candidates spanning 320–810 ms.*

## 8. Verification

- [x] 8.1 Diff the serial command output against a golden capture taken before the change; nothing outside the display should have moved. *58 of 59 lines byte-identical. The one difference is the `GB` line, which the capture script annotates as boot-dependent, and it decodes to the alarm time set during the 7.2 test (0x0924 = 09:36).*
- [x] 8.2 Exercise the full glyph set in all six positions and confirm no intermittent wrong segments, using the all-segments and six-distinct-digits patterns rather than the time. *Digits 0–9 driven across all six positions via timestamps; menu labels confirmed separately in 8.4.*
- [x] 8.3 Confirm the alarm flash and the field-edit blink still render, since both drive the display harder than the idle path. *Both confirmed — the alarm flash during the 7.2 dismissal test, the field-edit blink on the buttons.*
- [x] 8.4 Walk the menu and confirm every label renders. *Confirmed.*
- [x] 8.5 Confirm the leading hour zero is still blanked in 12-hour mode and still present in 24-hour mode — this change must not disturb behaviour that already shipped. *Confirmed across 09:34, 10:35, 12:36, 13:37 in 12-hour mode and 09:34 in 24-hour.*
- [x] 8.6 Record final flash and RAM against the baseline, and state the buffer's share of RAM. *Flash 37,220 → 38,360 (+1,140, 58.5%). RAM 4,920 → 6,476 (+1,556, 31.6%), of which 1,536 is the waveform — within 20 bytes of the design's prediction of 6,456.*
- [x] 8.7 Update `CLAUDE.md` where it describes the display pipeline, which currently says the shift loop is two stores per bit driven by the CPU.
- [x] 8.8 Update `docs/DEVELOPMENT.md` with the timer, the two DMA channels, the derived constants, the reason the slice period is locked to the output-enable period, and the fade's tuned timings.
- [x] 8.9 Run `openspec validate dma-display-engine`. *6 passed, 0 failed.*

## 9. Deferred, deliberately

- [x] 9.1 Decide whether per-digit levels should persist in backup registers, once there is something to judge by eye. ***No.*** *Nothing in the production build exposes a per-digit level to the user — `WL` is verify-only — and the fade's use is transient, always ending at full. There is no user setting here to persist. Revisit only if per-digit brightness becomes something the user sets.*

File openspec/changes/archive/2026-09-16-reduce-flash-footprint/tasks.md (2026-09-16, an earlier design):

## 1. Golden baseline, before touching anything

- [x] 1.1 Record the starting figures: flash bytes and percentage, RAM, and the sizes of the symbols this change expects to remove
- [x] 1.2 Capture every command's reply from the **current** firmware into a file — `TEST`, `GT`, `ST`, `SO`, `GO`, `GM`, `SM`, `GA`, `SA`, `AE`, `GL`, `GI`, `SI`, `GD`, `SD`, `GB` — including an unrecognized command
- [x] 1.3 Capture every error path too: missing argument and out-of-range argument for each command that takes one
- [x] 1.4 Capture a set of `ST` → `GT` round-trips across awkward dates: a leap day, the end of a 30- and a 31-day month, a year boundary, and a time either side of midnight
- [x] 1.5 Confirm the capture is reproducible — run it twice and diff, so that fields which legitimately change (the clock) are known and excluded from later comparisons

## 2. Integer date arithmetic

- [x] 2.1 Add days-from-civil and civil-from-days helpers, integer only, no tables
- [x] 2.2 Verify the helpers against known-good values computed on the host, across the same awkward dates as the golden capture, before wiring them into anything
- [x] 2.3 Replace `unixTimestampToTime`'s `localtime()` with the new conversion, preserving the existing timezone-offset handling exactly
- [x] 2.4 Replace `cmd_get_time`'s `mktime()` with the reverse conversion, preserving its offset handling exactly
- [x] 2.5 Confirm `localtime`, `mktime`, `tzset` and the `scanf` family are gone from the linked image
- [x] 2.6 Check whether `__udivmoddi4` went with them, and note what still needs 64-bit division if it did not
- [x] 2.7 Diff every reply against the golden capture; measure and record the flash delta

## 3. Month consistency

- [x] 3.1 Make 1–12 canonical in `date_time_buf` and the RTC, converting only where a `tm`-shaped value is produced or consumed
- [x] 3.2 Update the date editor path so the menu and serial agree
- [x] 3.3 Check `setup_rtc`'s epoch comparison against `RTC_MONTH_JANUARY` still means what it says under the canonical representation
- [x] 3.4 Check the RTC seconds interrupt, which reads the month back every second
- [x] 3.5 Verify on the device: set a date over serial, read it in the menu, set one in the menu, read it over serial — the month must agree in both directions
- [x] 3.6 Confirm `ST` → `GT` still round-trips to the same timestamp it did before
- [x] 3.7 Confirm the unmodified `timesync.py` still reports zero skew

## 4. Remove the formatted-output chain

- [x] 4.1 Add the two small helpers `print()` lacks: two-digit zero padding and four-digit zero-padded hex
- [x] 4.2 Replace all eleven `printf` call sites with `print()` sequences, preserving every byte — including the error replies that deliberately have no trailing newline
- [x] 4.3 Confirm `vdprintf`, `vasnprintf`, `svfprintf` and `printf_i` are gone from the linked image
- [x] 4.4 Check whether the float `vfprintf` variant survives via `assert`, and record what still reaches it
- [x] 4.5 Diff every reply against the golden capture, error paths included; measure and record the flash delta

## 5. Link-time optimisation

- [x] 5.1 Enable `-flto` and confirm the image builds
- [x] 5.2 Measure the delta; if it is negligible, note that and drop it rather than carrying the risk
- [x] 5.3 Flash and run the full verification — replies, display, menu, alarm, LEDs, brightness
- [x] 5.4 Decide on the evidence: keep it only if it both saves meaningfully and behaves identically, and record the decision either way

## 6. Flash budget reporting

- [x] 6.1 Report flash usage and remaining headroom from `scripts/check-dev-env.sh`
- [x] 6.2 Make it work without requiring a fresh build, or say plainly that it reflects the last build
- [x] 6.3 Record the change's own before and after figures in the docs

## 7. Verification

- [x] 7.1 Full golden diff: every command, every error path, every round-trip date, against the baseline from group 1
- [x] 7.2 Walk the menu on the device: every entry, wrap, long-press exit, timeout
- [x] 7.3 Confirm the display, the alarm breathing, both brightness controls and all three LEDs are unchanged
- [x] 7.4 Power-cycle and confirm settings and the clock survive, using `GB` to check the stored values
- [x] 7.5 Record the final flash and RAM against the 82.3% / 24.6% starting point
- [x] 7.6 Update `docs/DEVELOPMENT.md`: the size figures, the LTO decision, the flash reporting, and remove the month defect from the known-defects list
- [x] 7.7 Update `CLAUDE.md` where it describes the date handling or the known defects
- [x] 7.8 Run `openspec validate reduce-flash-footprint`

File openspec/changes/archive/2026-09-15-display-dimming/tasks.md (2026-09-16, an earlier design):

## 1. Move ~OE into ShiftDisplay

- [x] 1.1 Give `ShiftDisplay` a brightness value and a setter, with the active-low inversion handled inside the class so callers never write the complement themselves
- [x] 1.2 Drive `~OE` with `analogWrite` on PA0 (TIM2_CH1) in `begin()`, replacing the `pinMode`/`digitalWrite` setup
- [x] 1.3 Reimplement `enable()` and `disable()` as brightness operations — `enable()` restores the configured brightness, not full
- [x] 1.4 Confirm no `digitalWrite` to the `~OE` pin survives anywhere in `src/` or `lib/`
- [x] 1.5 Confirm the display still shows the same content after ~OE moved into ShiftDisplay. *Done via the end state rather than the planned fixed-full-brightness intermediate build, which was skipped: the intermediate was not separately observable, and the configured-level behaviour is.*

## 2. Shared PWM settings

- [x] 2.1 Raise the global `analogWriteFrequency` to 4 kHz, with a comment that resolution and frequency are shared with the indicator LEDs
- [x] 2.2 Confirm the timer reload still exceeds the 12-bit duty range at 4 kHz, so resolution is not silently reduced
- [x] 2.3 Flash and confirm the indicator LEDs are unaffected — brightness levels and alarm breathing unchanged

## 3. Brightness level

- [x] 3.1 Add a display level to the settings struct, with a defined default
- [x] 3.2 Persist it in the **high** byte of DR8, preserving the indicator level in the low byte; confirm DR1, DR4, DR6, DR7 and DR10 remain untouched
- [x] 3.3 Map levels to duty on the same gamma curve as the indicators, with a floor chosen for legibility rather than mere visibility
- [x] 3.4 Apply the level so the display shows at the configured brightness, and confirm all six digits are equally bright
- [x] 3.5 Confirm changing brightness does not disturb content — nothing re-shifts, no digit glitches, the decimal point holds

## 4. Glyphs and menu

- [x] 4.1 Define `I` and `S` in the glyph table, filling slots that are already zeroed
- [x] 4.2 Re-run the label audit from the previous change over every label string, so a missing glyph is caught before it reaches the board
- [x] 4.3 Add the `dISP` menu entry and its editor, with the level as a single adjustable field
- [x] 4.4 Make the display preview itself live while the level is being adjusted
- [x] 4.5 Confirm backing out with a long press discards the change and restores the previous brightness
- [x] 4.6 Confirm the inactivity timeout also restores the previous brightness rather than leaving the preview applied

## 4b. Glyph table hardening (folded in)

- [x] 4b.1 Replace the raw binary literals in `segment_data[]` with named `SEG_A`..`SEG_G` constants, so each glyph reads as the segments it lights
- [x] 4b.2 Fix `'B'`, which was missing segment C and was byte-identical to `'T'` — the last of three glyph bugs that literals made easy to write and hard to see
- [x] 4b.3 Regenerate the table from the verified decode rather than retyping it, and diff the result byte-for-byte against the previous values
- [x] 4b.4 Confirm exactly one byte changed (`'B'`) and that flash is unchanged, since the compiler folds the constants

## 5. Serial

- [x] 5.1 Add get/set commands for the display level, rejecting out-of-range values without changing state
- [x] 5.2 Use the read-back to confirm the inversion is the right way round before judging it by eye — level 1 must be dim and level 8 bright
- [x] 5.3 Verify `TEST`, `GT`, `ST`, `SO` and `GO` are untouched, and that the unmodified `timesync.py` still reports skew 0

## 5b. Settings diagnostic (folded in)

- [x] 5b.1 Capture what the first backup-register read returns at start-up, before `settings_load()` can overwrite it
- [x] 5b.2 Add a command reporting both the start-up values and the current ones, plus the expected validity marker
- [x] 5b.3 Use it to test a genuine power cycle with distinctive values in all four settings, both cables out
- [x] 5b.4 Record the result: all settings and the clock survived; the reported loss did not reproduce

## 6. Verification

- [x] 6.1 Confirm the dimmest level is still legible in a dark room; raise the floor if it is not
- [x] 6.2 Confirm the brightest level is not unpleasant in a lit room
- [x] 6.3 Check for flicker at several levels, including at the edge of vision and while moving the eyes
- [x] 6.4 Confirm the alarm still flashes the display, at the configured brightness rather than overriding to full
- [x] 6.5 Confirm the field-edit blink still blanks only the field being edited
- [x] 6.6 Power-cycle and confirm both brightness levels survive alongside the other settings and the date
- [x] 6.7 Walk the full menu and confirm the new entry has not disturbed scrolling, wrap, long-press exit or the timeout
- [x] 6.8 Record the final flash and RAM against the 81.1% / 24.3% starting point
- [x] 6.9 Update `docs/DEVELOPMENT.md`: the new commands, the menu entry, the brightness section, the shared PWM frequency, and the settings diagnostic
- [x] 6.10 Update `CLAUDE.md` where it describes the display driver and `enable()`/`disable()`
- [x] 6.11 Run `openspec validate display-dimming`

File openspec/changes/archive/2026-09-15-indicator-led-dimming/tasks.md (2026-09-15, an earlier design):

## 1. PWM drive, no behaviour change yet

- [x] 1.1 Replace the three `digitalWrite` calls in `update_leds()` with `analogWrite`, lit meaning full duty, so the change is invisible on the board at this stage
- [x] 1.2 Change `setup_user_leds()` to establish the off state through the same path rather than `pinMode` plus `digitalWrite(LOW)`, so nothing reconfigures a PWM pin back to plain output
- [x] 1.3 Delete the `AlrmLEDTim` global and the commented-out `setPWM` block, which this change supersedes
- [x] 1.4 Build and record the flash delta from the 74.2% starting point — `analogWrite` links PWM machinery this firmware has not used before
- [x] 1.5 Flash and confirm all three indicators still behave exactly as before

## 2. Brightness level

- [x] 2.1 Add an indicator level to the settings struct, with a defined default
- [x] 2.2 Persist it in the low byte of DR8, leaving the high byte free for `display-dimming`; re-confirm DR1, DR4, DR6, DR7 and DR10 are still untouched
- [x] 2.3 Add the gamma lookup table mapping user levels to duty values
- [x] 2.4 Apply the level in `update_leds()` so "lit" means the configured duty
- [x] 2.5 Confirm the dimmest level is still clearly visible in a dark room, and raise the floor if it is not

## 3. Serial

- [x] 3.1 Add get/set commands for the indicator level, rejecting out-of-range values without changing state
- [x] 3.2 Change `GL` to report each LED's duty instead of `digitalRead`, which samples the live PWM waveform and returns noise on an alternate-function pin
- [x] 3.3 Confirm the existing `serial-command-console` scenarios still hold with duty values — "lit" now means non-zero
- [x] 3.4 Verify `TEST`, `GT`, `ST`, `SO` and `GO` are untouched, and that the unmodified `timesync.py` still reports skew 0

## 4. Menu

- [x] 4.1 Add the brightness entry to the menu tree, with a label renderable from the existing glyph set
- [x] 4.2 Add its editor, with the level as a single adjustable field
- [x] 4.3 Make the indicators track the value live while it is being adjusted, so the choice is made by eye
- [x] 4.4 Confirm backing out with a long press discards an uncommitted level change and restores the previous brightness
- [x] 4.5 Confirm the inactivity timeout also restores the previous brightness rather than leaving the preview applied

## 5. Breathing

- [x] 5.1 Replace the `blink_on()` source for the firing indicator with a breathing waveform computed from `millis()`
- [x] 5.2 Scale the breath so its peak is the configured indicator brightness rather than full duty
- [x] 5.3 Keep the trough slightly above zero so a glance mid-breath does not read as "not armed"
- [x] 5.4 Confirm the armed indicator still sits steady, visibly distinct from breathing
- [x] 5.5 Confirm the fade reads as continuous rather than stepped at both the highest and lowest brightness levels
- [x] 5.6 Verify a real firing on the board, and confirm `GL` shows the bottom LED's duty varying so firing stays detectable from a host

## 6. Verification and documentation

- [x] 6.1 Power-cycle and confirm the indicator level survives alongside the existing settings and the date
- [x] 6.2 Walk the full menu and confirm the new entry has not disturbed scrolling, wrap, long-press exit or the timeout
- [x] 6.3 Confirm all three indicators still show the right thing: AM only in 12-hour mode, mode indicator, alarm armed
- [x] 6.4 Record the final flash and RAM figures
- [x] 6.5 Update `docs/DEVELOPMENT.md`: the `GL` reply format, the new commands, the menu entry, the LED table, and a note that TIM4 is nominally `TIMER_SERVO`
- [x] 6.6 Update `CLAUDE.md` where it describes the LEDs as driven on or off
- [x] 6.7 Run `openspec validate indicator-led-dimming`

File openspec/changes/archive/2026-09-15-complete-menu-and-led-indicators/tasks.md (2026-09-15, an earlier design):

## 1. State machine foundation

- [x] 1.1 Add `currentMenuState = nextMenuState;` to `ShiftDisplayFSM::update()` — without this every menu transition is computed and discarded
- [x] 1.2 Add a `getMenuState()` accessor so `main.cpp` can render from the committed menu state
- [x] 1.3 Fill in the `MENU_UP` and `MENU_DOWN` actions, which are currently empty cases, with wrapping movement across the top-level entries
- [x] 1.4 Extend `execute()` so `MENU_SELECT` descends from each top-level entry into its editor, and `MENU_EXIT` ascends one level rather than always returning to `IDLE`
- [x] 1.5 Build and confirm the FSM still compiles into the existing main loop with no behavior change yet visible

## 2. Display glyphs

- [x] 2.1 Replace `segment_data[]` plus the hand-written range check in `map_ascii()` with a single ASCII-indexed lookup, so a glyph is renderable exactly when it is defined
- [x] 2.2 Add glyphs for `-`, `L`, `n`, `o`, `P`, `r`, `t`, `U`, keeping the existing `0-9`, `A-H` and space unchanged
- [x] 2.3 Keep the invalid-character indicator for anything with no glyph, so an unrenderable character still fails visibly
- [x] 2.4 Fix the `char buffer[6]` stack overflows at `main.cpp:248` and `:324` — both `sprintf` six characters plus a NUL into six bytes
- [x] 2.5 Flash a scratch build that writes each new glyph and confirm on the display that every one renders as intended, not as the invalid-character bars

## 3. Settings storage and LEDs

- [x] 3.1 Add a settings struct holding 12/24-hour mode, alarm hour, alarm minute, and armed state
- [x] 3.2 Implement load/save against backup registers DR2 (magic), DR3 (flags), DR4 (packed alarm time) via `LL_RTC_BAK_SetRegister`/`GetRegister`; the library's own helpers are internal to `rtc.c`
- [x] 3.3 Confirm in `rtc.h` that `RTC_BKP_DATE` is still `LL_RTC_BKP_DR6` and that nothing in this change writes DR6 or DR7 — those hold the emulated date on the F1
- [x] 3.4 Apply a magic value on load so uninitialized backup memory yields defaults rather than arbitrary settings
- [x] 3.5 Implement `update_leds()` driven from state: top/PB8/D3 = PM in 12-hour mode, mid/PB7/D2 = 12-hour mode active, bottom/PB6/D1 = alarm armed. All active high
- [x] 3.6 Call `update_leds()` once per loop rather than writing LEDs from individual handlers
- [x] 3.7 Verify persistence on hardware: set mode and alarm, pull USB power, reconnect, and confirm the settings and the date both survived

## 4. 12/24-hour display

- [x] 4.1 Apply the 12-hour conversion at the point digits are formatted, leaving the RTC in `HOUR_24`
- [x] 4.2 Handle the two boundaries explicitly: RTC hour 0 displays as 12, RTC hour 12 displays as 12, RTC hour 13 displays as 1
- [x] 4.3 Confirm `rtc.begin()` is still called with `STM32RTC::HOUR_24` and that no code path reconfigures the RTC's hour format
- [x] 4.4 Verify on hardware across a mode switch that `GT` returns the same timestamp before and after

## 5. Buttons and menu

- [x] 5.1 Remove `kFeatureDoubleClick` from `ButtonConfig` — nothing uses it and it delays every click by the double-click window
- [x] 5.2 Handle `kEventLongPressed` and `kEventRepeatPressed` in `handleEvent()` alongside `kEventClicked`, latching them the way click events are latched today
- [x] 5.3 Implement the top-level menu: SET enters, PLUS/MINUS scroll with wrap, SET selects, long-press SET backs out
- [x] 5.4 Choose menu labels renderable with the extended glyph set and confirm each on the display
- [x] 5.5 Implement the time editor: active field blinks, PLUS/MINUS adjust with wrap, repeat-press drives hold-to-adjust, SET advances field and commits after the last
- [x] 5.6 Implement the date editor on the same pattern
- [x] 5.7 Implement the 12/24 toggle entry, writing through to settings and refreshing the LEDs
- [x] 5.8 Drive blinking from a single `millis()`-derived phase shared with the alarm blink, and re-render only on content or phase change so the idle path does not re-shift every loop
- [x] 5.9 Add the inactivity timeout that returns to the clock without committing a pending value
- [x] 5.10 Confirm backing out of an edited-but-uncommitted field discards the change

## 6. Alarm

- [x] 6.1 Add the alarm entry to the menu: set hour and minute, then arm or disarm
- [x] 6.2 Raise the firing flag from `irq_rtc_seconds` when armed and `seconds == 0` and hour/minute match, so it fires once per day with no re-arming
- [x] 6.3 Implement the firing signal: display flashes and the bottom LED blinks, visibly distinct from the steady armed indication
- [x] 6.4 Dismiss on any button, and consume that press so it does not also act on the menu
- [x] 6.5 Confirm the alarm stays armed after dismissal and fires again the next day
- [x] 6.6 Confirm the clock keeps time while the alarm is left signalling, and that `GT` is still correct
- [x] 6.7 Verify a real firing on hardware by setting the alarm a minute or two ahead and watching it

## 7. Serial commands

- [x] 7.1 Add get/set commands for 12/24-hour mode
- [x] 7.2 Add get/set commands for the alarm time, rejecting hours outside 0–23 and minutes outside 0–59 without changing state
- [x] 7.3 Add an arm/disarm command and a way to read the armed state
- [x] 7.4 Add a command that reports LED state, so the indicators can be checked from the host rather than only by eye
- [x] 7.5 Register every new command with `AddCommand()` — note the existing `cmd_set_hour`/`cmd_set_minute`/`cmd_set_second` are implemented but never registered, which is the trap to avoid repeating
- [x] 7.6 Confirm the receive buffer still holds the longest new command with its arguments
- [x] 7.7 Leave `TEST`, `GT`, `ST`, `SO`, `GO` handlers untouched; diff them against the previous revision to prove it

## 8. Verification

- [x] 8.1 Run the unmodified `timesync.py -H` against the device as the serial regression test — it must report the time and skew exactly as before, with no edit to the tool
- [x] 8.2 Round-trip every new setting over serial, and confirm a setting changed with the buttons reads back correctly over serial
- [x] 8.3 Walk the whole menu on the device: every entry reachable, wrap works at both ends, long-press backs out, timeout returns to the clock
- [x] 8.4 Confirm all three LEDs against their table: PM in 12-hour mode only, mode indicator, armed indicator
- [x] 8.5 Power-cycle and confirm mode, alarm time, armed state, and the date all survive
- [x] 8.6 Record final flash and RAM against the 69.8% / 23.3% starting point
- [x] 8.7 Update `docs/DEVELOPMENT.md`: CDC command table, LED map with the D-number mapping, menu walkthrough, and remove the two buffer overflows and the "menu unimplemented" entry from known defects
- [x] 8.8 Update `CLAUDE.md` where it describes the FSM as having an unreachable menu tree and the LEDs as unused
- [x] 8.9 Run `openspec validate complete-menu-and-led-indicators`

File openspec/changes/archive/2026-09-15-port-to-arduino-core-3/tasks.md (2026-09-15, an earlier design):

## 1. Dependency changes

- [x] 1.1 In `firmware/platformio.ini`, replace the `platform = ststm32@19.7.1` pin and its explanatory comment block with `platform = ststm32@^20.0.0`
- [x] 1.2 Move `stm32duino/STM32duino RTC` from `@ ^1.4.0` to `@ ^2.0.0`
- [x] 1.3 Remove the `stm32duino/STM32duino Low Power @ ^1.2.5` line; re-confirm with `grep -rn "LowPower\|STM32LowPower" firmware/src firmware/lib firmware/include` that nothing references it
- [x] 1.4 Confirm `firmware/src/` and `firmware/lib/` are untouched — this change edits one file

## 2. Build

- [x] 2.1 Remove `firmware/.pio/` and run `pio run -d firmware` (redirect to a log; do not pipe through `tee` or the exit status is lost)
- [x] 2.2 Confirm the build exits 0 with no `error:` lines
- [x] 2.3 Confirm the resolved versions: `ststm32@20.x`, `framework-arduinoststm32@4.30000.0` (Arduino core 3.0.0), `STM32duino RTC@2.x`, `AceButton@1.10.1`, `SerialCommands@2.2.0`, and no Low Power
- [x] 2.4 Record the RAM/flash figures and compare against the pre-change 24.7% / 72.2%; the experiment predicts roughly 23.3% / 69.8%
- [x] 2.5 Note any new warnings, in particular whether `SerialCommands`' deprecated `boolean` is still only a warning

## 3. Hardware verification

- [x] 3.1 Record the device time with `GT` before flashing, so the clock can be restored if the port misbehaves
- [x] 3.2 Flash with `pio run -d firmware -t upload`; confirm `** Verified OK **` and `** Resetting Target **`
- [x] 3.3 Watch the display: it shows the time and the digits advance — this is the proof that the RTC seconds interrupt still fires and `time_dirty` still drives redraws
- [x] 3.4 Confirm the board re-enumerates as USB `0483:5740` and `pio device list --serial` still shows it
- [x] 3.5 CDC round-trip: `TEST` replies `TEST`, `GT` replies an integer timestamp, `GO` replies the offset
- [x] 3.6 Set the clock with `ST <timestamp>`, wait at least a minute, read it back with `GT`, and confirm it advanced by the elapsed interval — proves the LSE source and RTC configuration survived
- [x] 3.7 Press the SET button and confirm the menu branch still draws, so AceButton's dispatch is intact under the new core
- [x] 3.8 If any of 3.3–3.7 fails, stop and revert rather than patching forward; the failure is the result this change exists to find

## 4. Documentation

- [x] 4.1 Replace `docs/DEVELOPMENT.md`'s "Why the platform version is pinned" section with what is true afterward: what the constraint now is and why it is a range rather than a pin
- [x] 4.2 Correct the "Arduino core 4.x" naming in `docs/DEVELOPMENT.md` — state both the PlatformIO package version and the Arduino core version it carries (`4.30000.0` = core 3.0.0, `4.21200.0` = core 2.12.0), since conflating them is what caused the original misdiagnosis
- [x] 4.3 Update the resolved-versions block in `docs/DEVELOPMENT.md` to the versions recorded in 2.3
- [x] 4.4 Remove the note that `STM32duino Low Power` is an unused `lib_deps` entry that can still break a build — it is no longer a dependency
- [x] 4.5 Update `CLAUDE.md`: drop the "don't unpin it" trap, correct the core naming, and keep the `tee` warning
- [x] 4.6 Update the platform-pin sentence in `openspec/config.yaml`'s context block
- [x] 4.7 Record in `docs/DEVELOPMENT.md` that commit `109d621`'s message still says "core 4.x" and is left uncorrected because the history is merged

## 5. Close out

- [x] 5.1 Confirm the final diff touches only `firmware/platformio.ini`, `docs/DEVELOPMENT.md`, `CLAUDE.md`, and `openspec/`
- [x] 5.2 Run `./scripts/check-dev-env.sh` and confirm it still passes
- [x] 5.3 Commit as a single unit so the change reverts atomically, and say in the message that rolling back requires reverting the whole commit, not just the platform line
- [x] 5.4 Run `openspec validate port-to-arduino-core-3`

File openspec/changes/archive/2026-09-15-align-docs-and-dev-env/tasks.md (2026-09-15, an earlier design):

## 1. Firmware toolchain

- [x] 1.1 Install PlatformIO Core with `uv tool install platformio`; verify `pio --version` exits 0 in a fresh shell and `which pio` resolves outside any VS Code extension directory
- [x] 1.2 Remove the stale `firmware/.pio/` carried over from the previous machine (it references toolchain paths that do not exist here)
- [x] 1.3 Run `pio run -d firmware` to completion; expect a long first run while the `ststm32` platform, ARM toolchain, and the four `lib_deps` download
- [x] 1.4 If 1.3 fails on platform or Arduino-core drift, pin `platform = ststm32@<version>` in `firmware/platformio.ini` to a release contemporary with the last known-good 2024 build, re-run, and record the pinned version and the failure it resolved
- [x] 1.5 Confirm `firmware/.pio/build/bluepill_f103c8_128k/firmware.elf` and `firmware.bin` exist and post-date the build

## 2. Hardware in the loop

- [x] 2.1 Confirm the ST-Link (VID `0x0483`, PID `0x3752`, serial `0673FF373841423043111349`) and the board CDC (VID `0x0483`, PID `0x5740`, serial `49795F733055`) are both enumerated
- [x] 2.2 Flash the unchanged firmware with `pio run -d firmware -t upload`; confirm it completes and the display runs after reset
- [x] 2.3 Open the CDC port and send `TEST\r\n`; confirm the device replies `TEST`
- [x] 2.4 Send `GT\r\n`; confirm a single integer Unix timestamp comes back
- [x] 2.5 Record the exact working monitor invocation for the documentation

## 3. Python host environment

- [x] 3.1 Delete the dead `software/.venv` (untracked; its interpreter and `bin/python*` symlinks are gone)
- [x] 3.2 Create `software/timesync/pyproject.toml` with a pinned `requires-python` and `pyserial==3.5` / `ntplib==0.4.0`; generate `uv.lock`
- [x] 3.3 Remove `software/timesync/requirements.txt`, now fully represented by the lockfile; note the `uv export` fallback for pip users in the docs
- [x] 3.4 Verify from a clean state: remove the environment, run the documented setup command, and confirm `serial` and `ntplib` import
- [x] 3.5 Run `uv run python timesync.py -H` against the attached board; confirm it prints NTP time, device time, and skew and exits 0
- [x] 3.6 Update `software/timesync/.gitignore` if the uv layout changes what should be ignored

## 4. Serial port discovery

- [x] 4.1 Replace the hardcoded `/dev/cu.usbmodem49795F7330551` default with `serial.tools.list_ports` enumeration matching VID `0x0483` / PID `0x5740`
- [x] 4.2 Keep `--com` as an override that bypasses discovery entirely
- [x] 4.3 Exit non-zero with a message naming the missing device and how to pass a port when nothing matches; verify by unplugging the board
- [x] 4.4 Report the ambiguity rather than guessing when more than one matching device is present
- [x] 4.5 Re-run `-H` both with and without `--com` to confirm both paths still reach the device; leave `-U` and `--csv` behavior untouched

## 5. Readiness check

- [x] 5.1 Write `scripts/check-dev-env.sh` reporting on `pio`, the uv environment, the ST-Link, and the board CDC device
- [x] 5.2 Check every prerequisite before exiting, so one gap does not mask another; exit non-zero if any is missing
- [x] 5.3 Name the install command for each missing prerequisite in its failure line
- [x] 5.4 Verify it passes on this machine, and that it correctly reports a gap (e.g. with the board unplugged)

## 6. Documentation

- [x] 6.1 Write `docs/DEVELOPMENT.md` from the commands actually run in groups 1–5: prerequisites, install, build, flash, monitor, timesync workflow
- [x] 6.2 Add the CDC command table (`TEST`, `GT`, `ST <unix_ts>`, `SO <hours>`, `GO`) with framing — `\r\n` terminator, space-separated args, 32-byte buffer — and note that `cmd_set_hour`/`cmd_set_minute`/`cmd_set_second` exist but are unregistered
- [x] 6.3 Add the rev 2 pin map from `firmware/src/main.cpp`, naming the defines and the schematic as the authority
- [x] 6.4 Label machine-specific facts (device nodes, USB serial numbers) as observed on this Mac, with how to discover the equivalents elsewhere
- [x] 6.5 Document the KiCad 10.0.3 vs KiCad 8 file-format mismatch, that saving migrates irreversibly, that the files are deliberately unmigrated, and what to do if a hardware edit becomes necessary
- [x] 6.6 Record the known-but-unfixed defects: the `tm_mon` off-by-one across `ST`/`GT`, `setup_rtc()` testing uninitialized `day`/`month`/`year`, and `timesync.py`'s `abs(skew) > 1 & args.update` precedence bug
- [x] 6.7 Record that the menu FSM and display brightness/PWM are unimplemented, naming `lib/ShiftDisplayFSM` and the commented-out `HardwareTimer` setup
- [x] 6.8 Note that FreeCAD is not installed here and that `mechanical/` ships `.step`/`.xhtml` exports for anyone who does not need to edit the stand

## 7. README and agent context

- [x] 7.1 Correct `README.md` to lead with rev 2 as the current revision, linking `hardware/assets/STM32ShiftDisplayRev2.pdf`
- [x] 7.2 Retain the rev 1 design narrative and the PCBWay sponsorship acknowledgement as revision history rather than deleting them
- [x] 7.3 Note the `.kicad_pcb` title block's rev 1 vs the schematic's rev 2 as a known inconsistency left for a future hardware change
- [x] 7.4 Point the README at `docs/DEVELOPMENT.md` for setup instead of repeating them
- [x] 7.5 Trim `CLAUDE.md` to reference `docs/DEVELOPMENT.md` for commands, keeping architecture and conventions, so the two cannot drift
- [x] 7.6 Fill in `openspec/config.yaml`'s `context:` block with the firmware stack, host tooling, and branch/licensing conventions
- [x] 7.7 Add `.DS_Store` and local editor/agent artifacts to `.gitignore` so the working tree shows only real changes

## 8. Verification

- [x] 8.1 Walk `docs/DEVELOPMENT.md` top to bottom, running each command verbatim from the stated directory; fix anything that needs modification to work
- [x] 8.2 Diff the documented pin map against `main.cpp` defines and the documented commands against the registered `SerialCommand` objects
- [x] 8.3 Confirm `README.md`, `CLAUDE.md`, and `docs/DEVELOPMENT.md` agree on hardware revision, commands, and prerequisites
- [x] 8.4 Run `scripts/check-dev-env.sh` once more on the finished state
- [x] 8.5 Confirm `firmware/src/`, `firmware/lib/`, `hardware/`, and `mechanical/` are unchanged in the final diff (`platformio.ini` only if 1.4 pinned a version)
- [x] 8.6 Run `openspec validate align-docs-and-dev-env`

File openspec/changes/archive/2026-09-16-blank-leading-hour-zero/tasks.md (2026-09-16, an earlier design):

## 1. Implementation

- [x] 1.1 Add a helper that writes the hour into the buffer, applying the 12-hour conversion and suppressing the leading zero below ten
- [x] 1.2 Use it in the idle render path
- [x] 1.3 Use it in the alarm-firing render path, so the flash cannot disagree with the clock
- [x] 1.4 Confirm no other place renders the hour

## 2. Verification on the device

- [x] 2.1 Set the clock to a single-digit hour in 12-hour mode and confirm the tens position is dark, with no segments lit
- [x] 2.2 Confirm ten and twelve o'clock still show both digits — the threshold cases most likely to be wrong
- [x] 2.3 Confirm one in the afternoon shows as a blank and a 1, not 13
- [x] 2.4 Switch to 24-hour mode and confirm the leading zero returns
- [x] 2.5 Arm an alarm at a single-digit hour and confirm the flash blanks the same way the clock does
- [x] 2.6 Confirm the time editor still shows both hour digits, since it is deliberately unchanged. *Marked on the general "checks pass" rather than a separate confirmation.*
- [x] 2.7 Restore the clock to the correct time afterwards

## 3. Close out

- [x] 3.1 Confirm the change touches only the render path
- [x] 3.2 Run the unmodified `timesync.py` as the serial regression check
- [x] 3.3 Record the flash figure against the 56.8% starting point
- [x] 3.4 Run `openspec validate blank-leading-hour-zero`

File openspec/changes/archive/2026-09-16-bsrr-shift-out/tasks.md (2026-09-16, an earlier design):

## 1. Baseline

- [x] 1.1 Record the starting flash and RAM figures, and the current shift-out cost from the disassembly, so the change can be judged against something
- [x] 1.2 Capture the golden command output as before, so it can be confirmed that nothing outside the display driver moved
- [x] 1.3 Note the current shift clock rate implied by the instruction count, as the figure the measurement will replace

## 2. Resolve ports and masks, without changing the writes

- [x] 2.1 Resolve each control pin to its GPIO port and bit in `begin()`, alongside the existing `pinMode` calls
- [x] 2.2 Precompute the `BSRR` words the inner loop will need, including the combined data-and-clock-low pair
- [x] 2.3 Detect whether the data and clock pins share a port, and record which path applies
- [x] 2.4 Build and flash with the writes still going through `digitalWrite`; confirm the display is unchanged

## 3. Convert the writes

- [x] 3.1 Replace the per-bit `digitalWrite` triple in `shiftOutByte` with `BSRR` writes, using the combined path when the ports match and per-pin writes when they do not
- [x] 3.2 Convert `latch()` to `BSRR`
- [x] 3.3 Convert `clear()` to `BSRR`
- [x] 3.4 Move the inter-edge delay out of the inner loop's conditional and make it the deliberate throttle; remove the unused `_delay_ms`
- [x] 3.5 Confirm no write addresses the port as a whole — every store names only the driver's own pins, so `~OE` is untouched
- [x] 3.6 Build and flash at a deliberately slow rate; confirm all six digits are correct before going near the limit

## 4. Measure the safe rate

- [x] 4.1 Add the sweep build: a runtime-settable inter-edge delay and a temporary command to change it, both behind a build flag so production carries neither
- [x] 4.2 Add the two test patterns — all-segments-lit to expose dropped bits, and six distinct digits to expose a shifted stream
- [x] 4.3 Flash the sweep build and step the delay down while watching the display, alternating patterns, until corruption appears
- [x] 4.4 Record the failure point, and note whether it was a segment fault or a shift fault — they implicate different timings
- [x] 4.5 If no failure appears at the fastest achievable rate, record that instead; the constant is then zero and the margin is whatever the loop can do
- [x] 4.6 Choose the shipping rate with margin over the measured edge, and record the reasoning

## 5. Settle the production build

- [x] 5.1 Bake the chosen delay in as a compile-time constant and rebuild without the sweep flag
- [x] 5.2 Confirm the sweep command and the runtime variable are absent from the shipped image
- [x] 5.3 Exercise the full glyph set in all six positions at the chosen rate, watching for intermittent wrong segments
- [x] 5.4 Leave the display running for a spell and check it again, since the failure this guards against is occasional rather than immediate. *Accepted on the evidence available rather than on a long soak: the display ran continuously through the pattern sweep and the on-device checks with nothing observed, which is minutes rather than days. Closed by explicit decision that the testing was sufficient, not by a completed multi-day run.*

## 6. Verification

- [x] 6.1 Diff the command output against the golden capture; nothing outside the display driver should have moved
- [x] 6.2 Confirm brightness still works across its full range, and that changing it mid-refresh disturbs nothing
- [x] 6.3 Confirm the alarm flash and the field-edit blink still render correctly, since both drive the display harder than the idle path
- [x] 6.4 Walk the menu and confirm every label still renders
- [x] 6.5 Record the final flash and RAM figures, and the measured shift rate against the 615 kHz starting point
- [x] 6.6 Update `docs/DEVELOPMENT.md` with the measured failure point, the chosen rate and the margin, so the constant is not an unexplained number
- [x] 6.7 Update `CLAUDE.md` where it describes the display driver
- [x] 6.8 Run `openspec validate bsrr-shift-out`

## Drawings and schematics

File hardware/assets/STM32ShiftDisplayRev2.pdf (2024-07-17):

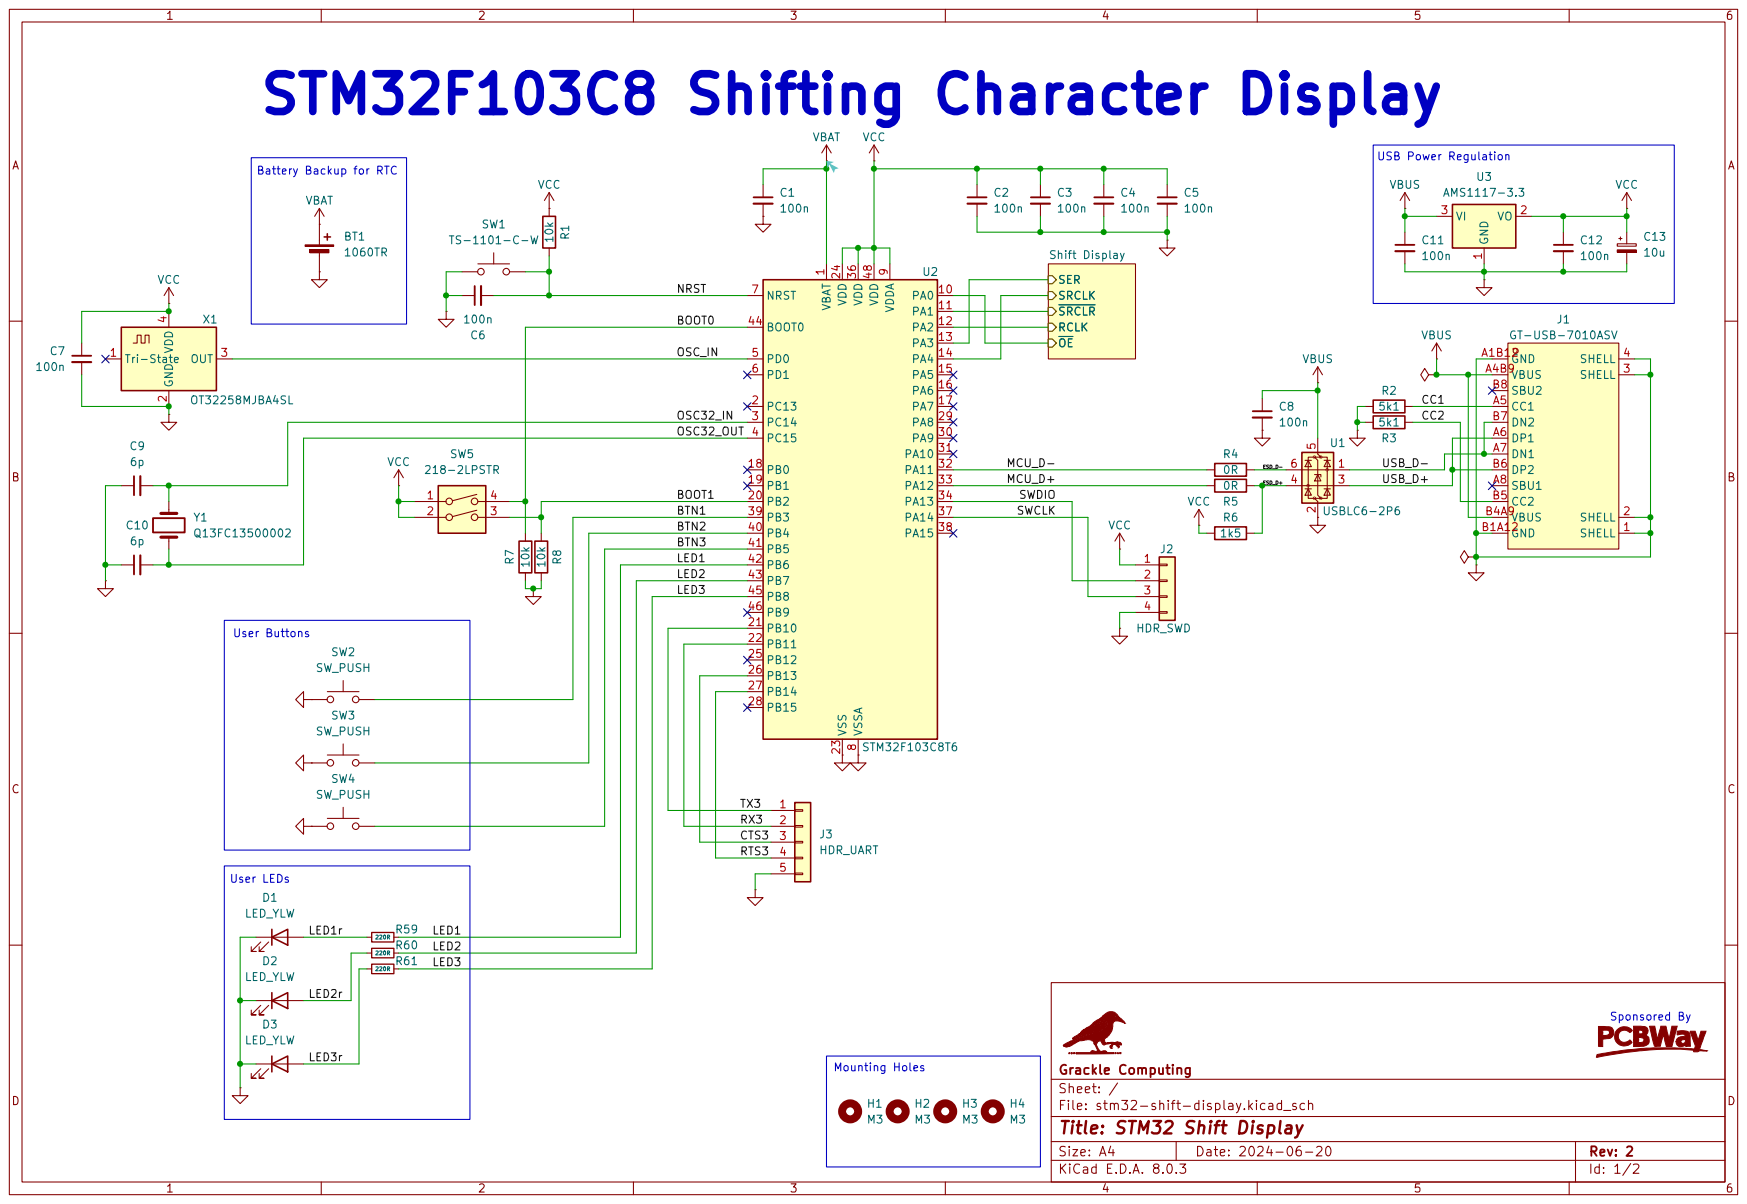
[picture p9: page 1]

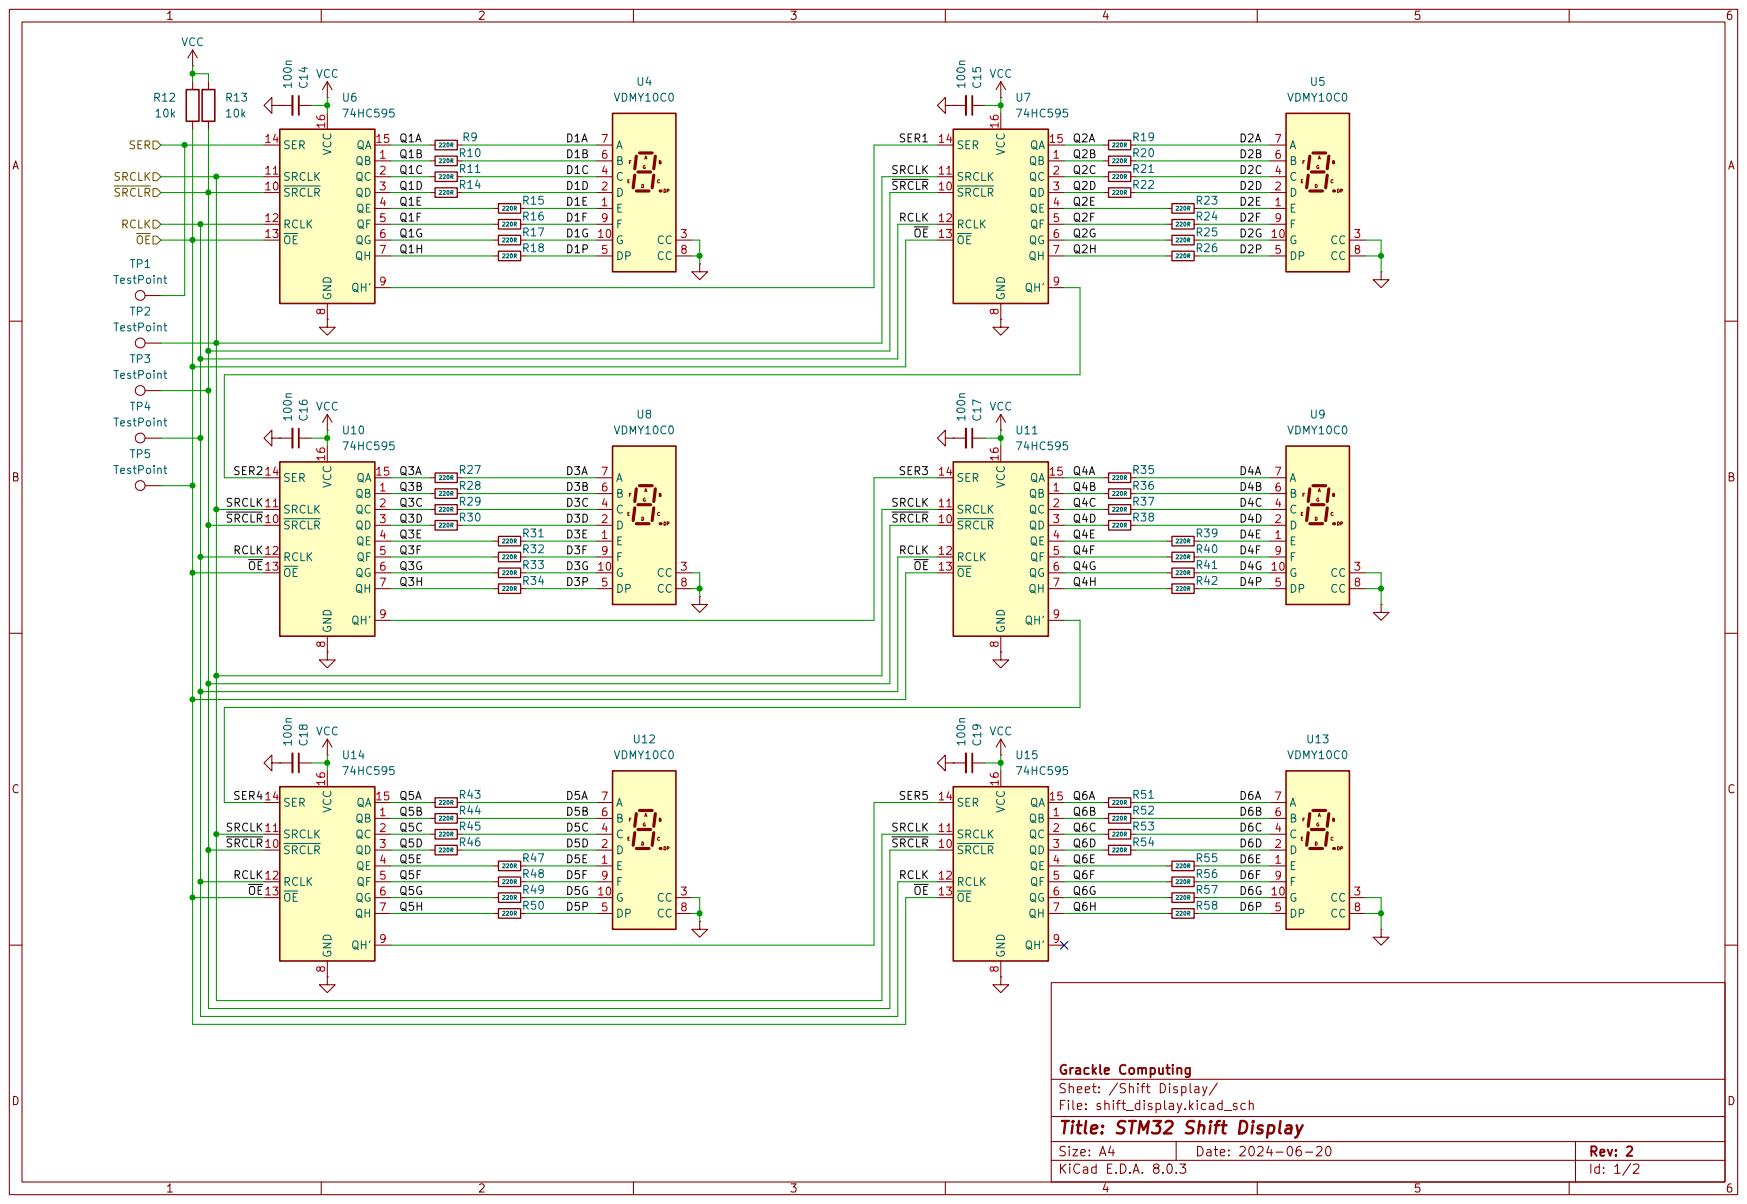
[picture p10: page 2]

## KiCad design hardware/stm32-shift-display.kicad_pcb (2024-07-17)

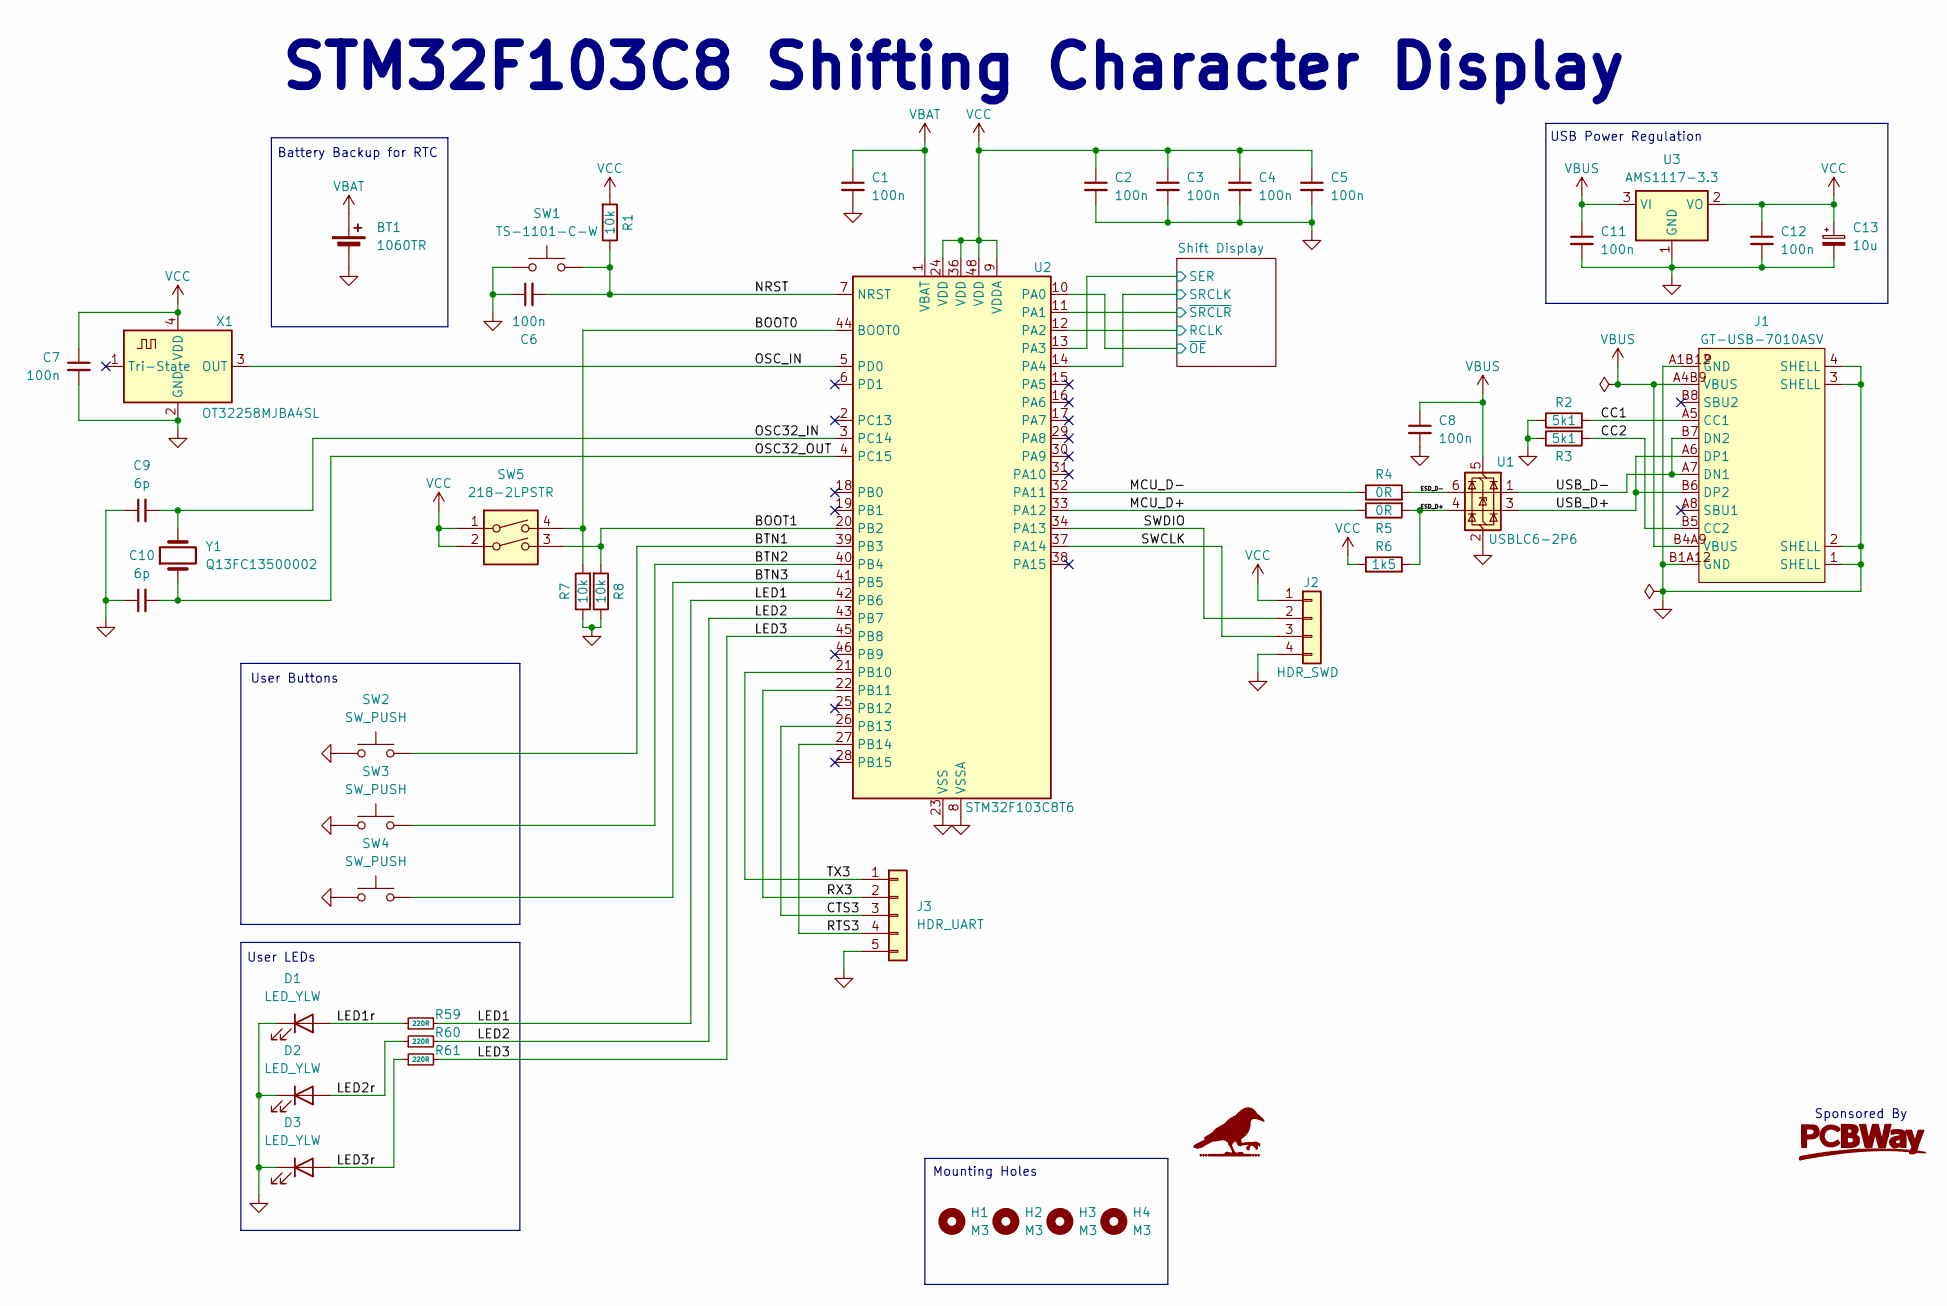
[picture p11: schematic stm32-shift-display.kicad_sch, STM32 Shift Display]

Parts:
BT1: 1060TR; BatteryHolder_Keystone_1060_1x2032; Mouser Part 534-1060TR
C1, C2, C3, C4, C5, C6, C7, C8: 100n; C_0402_1005Metric; LCSC Part C307331
C9, C10: 6p; C_0402_1005Metric; LCSC Part C2894321
C11, C12: 100n; C_0805_2012Metric; LCSC Part C28233
C13: 10u; CP_EIA-3216-18_Kemet-A; LCSC Part C7171
D1, D2, D3: LED_YLW; LED_D3.0mm
H1, H2, H3, H4: M3; MountingHole_3.2mm_M3_ISO7380
J1: GT-USB-7010ASV; USB-C-SMD_G-SWITCH_GT-USB-7010ASV; LCSC Part C2988369
J2: HDR_SWD; PinHeader_1x04_P2.54mm_Vertical
J3: HDR_UART; PinHeader_1x05_P2.54mm_Vertical
R1, R7, R8: 10k; R_0402_1005Metric; LCSC Part C25744
R2, R3: 5k1; R_0402_1005Metric; LCSC Part C25905
R4, R5: 0R; R_0402_1005Metric; LCSC Part C17168
R6: 1k5; R_0402_1005Metric; LCSC Part C25867
R59, R60, R61: 220R; R_0603_1608Metric; MFR Part 0603WAF2200T5E; LCSC Part C22962
SW1: TS-1101-C-W; SW-SMD_L6.0-W3.3-LS8.0; LCSC Part C318938
SW2, SW3, SW4: SW_PUSH; TS046643BK160SMT; Mouser Part 179-TS046673BK260SMT
SW5: 218-2LPSTR; SW_DIP_SPSTx02_Slide_Copal_CHS-02B_W7.62mm_P1.27mm; LCSC Part C2961921
U1: USBLC6-2P6; SOT-666; LCSC Part C2827693
U2: STM32F103C8T6; LQFP-48_7x7mm_P0.5mm; LCSC Part C8734
U3: AMS1117-3.3; SOT-223-3_TabPin2; LCSC Part C6186
X1: OT32258MJBA4SL; Crystal_SMD_3225-4Pin_3.2x2.5mm; LCSC Part C717687
Y1: Q13FC13500002; Crystal_SMD_3215-2Pin_3.2x1.5mm; LCSC Part C48615

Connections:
/BOOT0: R7.2, SW5.4, U2.44 (BOOT0)
/BOOT1: R8.2, SW5.3, U2.20 (PB2)
/BTN1: SW2.2, U2.39 (PB3)
/BTN2: SW3.2, U2.40 (PB4)
/BTN3: SW4.2, U2.41 (PB5)
/CC1: J1.A5 (CC1), R2.2
/CC2: J1.B5 (CC2), R3.2
/CTS3: J3.3, U2.26 (PB13)
/ESD_D+: R5.2, R6.2, U1.4 (I/O2)
/ESD_D-: R4.2, U1.6 (I/O1)
/LED1: R59.2, U2.42 (PB6)
/LED1r: D1.2 (A), R59.1
/LED2: R60.2, U2.43 (PB7)
/LED2r: D2.2 (A), R60.1
/LED3: R61.2, U2.45 (PB8)
/LED3r: D3.2 (A), R61.1
/MCU_D+: R5.1, U2.33 (PA12)
/MCU_D-: R4.1, U2.32 (PA11)
/NRST: C6.2, R1.1, SW1.2, U2.7 (NRST)
/OSC32_IN: C9.2, U2.3 (PC14), Y1.2
/OSC32_OUT: C10.2, U2.4 (PC15), Y1.1
/OSC_IN: U2.5 (PD0), X1.3 (OUT)
/RTS3: J3.4, U2.27 (PB14)
/RX3: J3.2, U2.22 (PB11)
/SWCLK: J2.3, U2.37 (PA14)
/SWDIO: J2.2, U2.34 (PA13)
/Shift Display/RCLK: U2.12 (PA2); also elsewhere on the board
/Shift Display/SER: U2.13 (PA3); also elsewhere on the board
/Shift Display/SRCLK: U2.14 (PA4); also elsewhere on the board
/Shift Display/~OE: U2.10 (PA0); also elsewhere on the board
/Shift Display/~SRCLR: U2.11 (PA1); also elsewhere on the board
/TX3: J3.1, U2.21 (PB10)
/USB_D+: J1.A6 (DP1), J1.B6 (DP2), U1.3 (I/O2)
/USB_D-: J1.A7 (DN1), J1.B7 (DN2), U1.1 (I/O1)
GND: BT1.2 (-), C1.2, C2.2, C3.2, C4.2, C5.2, C6.1, C7.2, C8.2, C9.1, C10.1, C11.2, C12.2, C13.2, D1.1 (K), D2.1 (K), D3.1 (K), J1.1 (SHELL), J1.2 (SHELL), J1.3 (SHELL), J1.4 (SHELL), J1.A1B12 (GND), J1.B1A12 (GND), J2.4, J3.5, R2.1, R3.1, R7.1, R8.1, SW1.1, SW2.1, SW3.1, SW4.1, U1.2 (GND), U2.8 (VSSA), U2.23 (VSS), U2.35 (VSS), U2.47 (VSS), U3.1 (GND), X1.2 (GND); also elsewhere on the board
VBAT: BT1.1 (+), C1.1, U2.1 (VBAT)
VBUS: C8.1, C11.1, J1.A4B9 (VBUS), J1.B4A9 (VBUS), U1.5 (VBUS), U3.3 (VI)
VCC: C2.1, C3.1, C4.1, C5.1, C7.1, C12.1, C13.1, J2.1, R1.2, R6.1, SW5.1, SW5.2, U2.9 (VDDA), U2.24 (VDD), U2.36 (VDD), U2.48 (VDD), U3.2 (VO), X1.4 (VDD); also elsewhere on the board

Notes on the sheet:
Battery Backup for RTC
Mounting Holes
User LEDs
USB Power Regulation
User Buttons
Sponsored By
STM32F103C8 Shifting Character Display

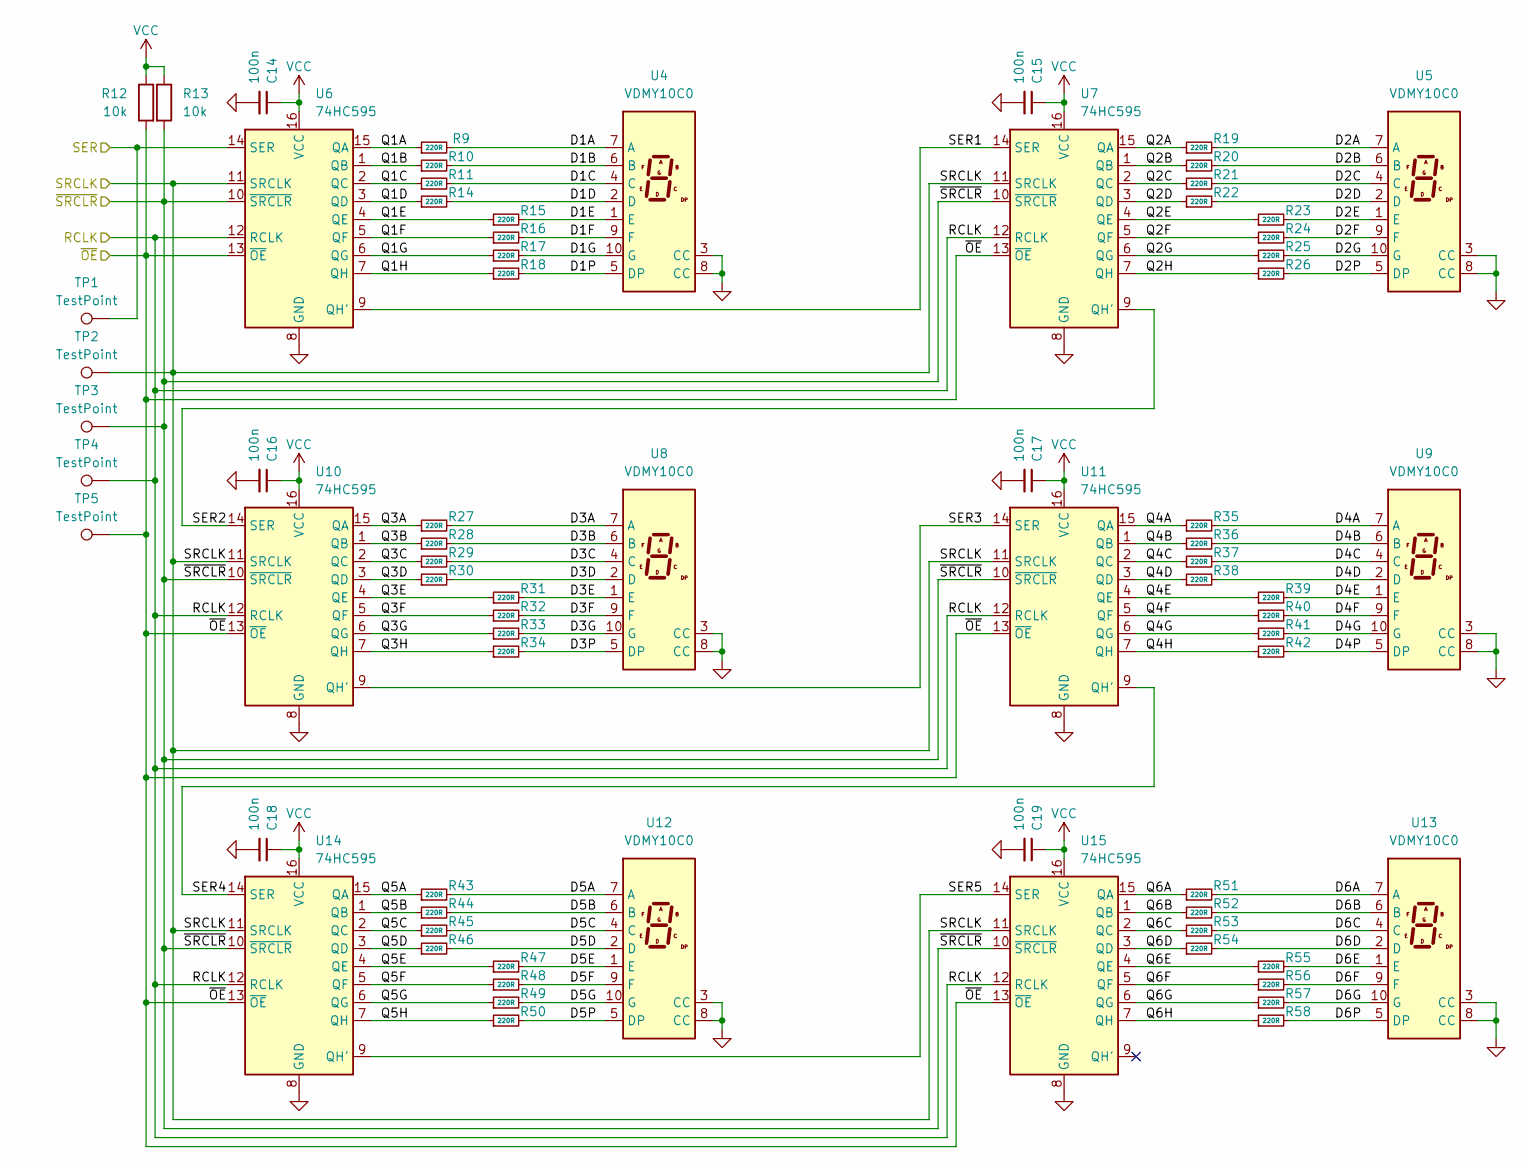
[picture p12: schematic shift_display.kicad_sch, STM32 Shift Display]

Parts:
C14, C15, C16, C17, C18, C19: 100n; C_0402_1005Metric; LCSC Part C307331
R9, R10, R11, R14, R15, R16, R17, R18, R19, R20, R21, R22, R23, R24, R25, R26, R27, R28, R29, R30, R31, R32, R33, R34, R35, R36, R37, R38, R39, R40, R41, R42, R43, R44, R45, R46, R47, R48, R49, R50, R51, R52, R53, R54, R55, R56, R57, R58: 220R; R_0603_1608Metric; MFR Part 0603WAF2200T5E; LCSC Part C22962
R12, R13: 10k; R_0402_1005Metric; LCSC Part C25744
TP1, TP2, TP3, TP4, TP5: TestPoint; TestPoint_Pad_D1.5mm
U4, U5, U8, U9, U12, U13: VDMY10C0; VDMx10x0; MFR Part VDMY10C0; Mouser Part 78-VDMY10C0
U6, U7, U10, U11, U14, U15: 74HC595; SOIC-16_3.9x9.9mm_P1.27mm; LCSC Part C5947

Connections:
/Shift Display/D1A: R9.2, U4.7 (A)
/Shift Display/D1B: R10.2, U4.6 (B)
/Shift Display/D1C: R11.2, U4.4 (C)
/Shift Display/D1D: R14.2, U4.2 (D)
/Shift Display/D1E: R15.2, U4.1 (E)
/Shift Display/D1F: R16.2, U4.9 (F)
/Shift Display/D1G: R17.2, U4.10 (G)
/Shift Display/D1P: R18.2, U4.5 (DP)
/Shift Display/D2A: R19.2, U5.7 (A)
/Shift Display/D2B: R20.2, U5.6 (B)
/Shift Display/D2C: R21.2, U5.4 (C)
/Shift Display/D2D: R22.2, U5.2 (D)
/Shift Display/D2E: R23.2, U5.1 (E)
/Shift Display/D2F: R24.2, U5.9 (F)
/Shift Display/D2G: R25.2, U5.10 (G)
/Shift Display/D2P: R26.2, U5.5 (DP)
/Shift Display/D3A: R27.2, U8.7 (A)
/Shift Display/D3B: R28.2, U8.6 (B)
/Shift Display/D3C: R29.2, U8.4 (C)
/Shift Display/D3D: R30.2, U8.2 (D)
/Shift Display/D3E: R31.2, U8.1 (E)
/Shift Display/D3F: R32.2, U8.9 (F)
/Shift Display/D3G: R33.2, U8.10 (G)
/Shift Display/D3P: R34.2, U8.5 (DP)
/Shift Display/D4A: R35.2, U9.7 (A)
/Shift Display/D4B: R36.2, U9.6 (B)
/Shift Display/D4C: R37.2, U9.4 (C)
/Shift Display/D4D: R38.2, U9.2 (D)
/Shift Display/D4E: R39.2, U9.1 (E)
/Shift Display/D4F: R40.2, U9.9 (F)
/Shift Display/D4G: R41.2, U9.10 (G)
/Shift Display/D4P: R42.2, U9.5 (DP)
/Shift Display/D5A: R43.2, U12.7 (A)
/Shift Display/D5B: R44.2, U12.6 (B)
/Shift Display/D5C: R45.2, U12.4 (C)
/Shift Display/D5D: R46.2, U12.2 (D)
/Shift Display/D5E: R47.2, U12.1 (E)
/Shift Display/D5F: R48.2, U12.9 (F)
/Shift Display/D5G: R49.2, U12.10 (G)
/Shift Display/D5P: R50.2, U12.5 (DP)
/Shift Display/D6A: R51.2, U13.7 (A)
/Shift Display/D6B: R52.2, U13.6 (B)
/Shift Display/D6C: R53.2, U13.4 (C)
/Shift Display/D6D: R54.2, U13.2 (D)
/Shift Display/D6E: R55.2, U13.1 (E)
/Shift Display/D6F: R56.2, U13.9 (F)
/Shift Display/D6G: R57.2, U13.10 (G)
/Shift Display/D6P: R58.2, U13.5 (DP)
/Shift Display/Q1A: R9.1, U6.15 (QA)
/Shift Display/Q1B: R10.1, U6.1 (QB)
/Shift Display/Q1C: R11.1, U6.2 (QC)
/Shift Display/Q1D: R14.1, U6.3 (QD)
/Shift Display/Q1E: R15.1, U6.4 (QE)
/Shift Display/Q1F: R16.1, U6.5 (QF)
/Shift Display/Q1G: R17.1, U6.6 (QG)
/Shift Display/Q1H: R18.1, U6.7 (QH)
/Shift Display/Q2A: R19.1, U7.15 (QA)
/Shift Display/Q2B: R20.1, U7.1 (QB)
/Shift Display/Q2C: R21.1, U7.2 (QC)
/Shift Display/Q2D: R22.1, U7.3 (QD)
/Shift Display/Q2E: R23.1, U7.4 (QE)
/Shift Display/Q2F: R24.1, U7.5 (QF)
/Shift Display/Q2G: R25.1, U7.6 (QG)
/Shift Display/Q2H: R26.1, U7.7 (QH)
/Shift Display/Q3A: R27.1, U10.15 (QA)
/Shift Display/Q3B: R28.1, U10.1 (QB)
/Shift Display/Q3C: R29.1, U10.2 (QC)
/Shift Display/Q3D: R30.1, U10.3 (QD)
/Shift Display/Q3E: R31.1, U10.4 (QE)
/Shift Display/Q3F: R32.1, U10.5 (QF)
/Shift Display/Q3G: R33.1, U10.6 (QG)
/Shift Display/Q3H: R34.1, U10.7 (QH)
/Shift Display/Q4A: R35.1, U11.15 (QA)
/Shift Display/Q4B: R36.1, U11.1 (QB)
/Shift Display/Q4C: R37.1, U11.2 (QC)
/Shift Display/Q4D: R38.1, U11.3 (QD)
/Shift Display/Q4E: R39.1, U11.4 (QE)
/Shift Display/Q4F: R40.1, U11.5 (QF)
/Shift Display/Q4G: R41.1, U11.6 (QG)
/Shift Display/Q4H: R42.1, U11.7 (QH)
/Shift Display/Q5A: R43.1, U14.15 (QA)
/Shift Display/Q5B: R44.1, U14.1 (QB)
/Shift Display/Q5C: R45.1, U14.2 (QC)
/Shift Display/Q5D: R46.1, U14.3 (QD)
/Shift Display/Q5E: R47.1, U14.4 (QE)
/Shift Display/Q5F: R48.1, U14.5 (QF)
/Shift Display/Q5G: R49.1, U14.6 (QG)
/Shift Display/Q5H: R50.1, U14.7 (QH)
/Shift Display/Q6A: R51.1, U15.15 (QA)
/Shift Display/Q6B: R52.1, U15.1 (QB)
/Shift Display/Q6C: R53.1, U15.2 (QC)
/Shift Display/Q6D: R54.1, U15.3 (QD)
/Shift Display/Q6E: R55.1, U15.4 (QE)
/Shift Display/Q6F: R56.1, U15.5 (QF)
/Shift Display/Q6G: R57.1, U15.6 (QG)
/Shift Display/Q6H: R58.1, U15.7 (QH)
/Shift Display/RCLK: TP4.1, U6.12 (RCLK), U7.12 (RCLK), U10.12 (RCLK), U11.12 (RCLK), U14.12 (RCLK), U15.12 (RCLK); also elsewhere on the board
/Shift Display/SER: TP1.1, U6.14 (SER); also elsewhere on the board
/Shift Display/SER1: U6.9 (QH'), U7.14 (SER)
/Shift Display/SER2: U7.9 (QH'), U10.14 (SER)
/Shift Display/SER3: U10.9 (QH'), U11.14 (SER)
/Shift Display/SER4: U11.9 (QH'), U14.14 (SER)
/Shift Display/SER5: U14.9 (QH'), U15.14 (SER)
/Shift Display/SRCLK: TP2.1, U6.11 (SRCLK), U7.11 (SRCLK), U10.11 (SRCLK), U11.11 (SRCLK), U14.11 (SRCLK), U15.11 (SRCLK); also elsewhere on the board
/Shift Display/~OE: R12.2, TP5.1, U6.13 (~OE), U7.13 (~OE), U10.13 (~OE), U11.13 (~OE), U14.13 (~OE), U15.13 (~OE); also elsewhere on the board
/Shift Display/~SRCLR: R13.2, TP3.1, U6.10 (~SRCLR), U7.10 (~SRCLR), U10.10 (~SRCLR), U11.10 (~SRCLR), U14.10 (~SRCLR), U15.10 (~SRCLR); also elsewhere on the board
GND: C14.2, C15.2, C16.2, C17.2, C18.2, C19.2, U4.3 (CC), U4.8 (CC), U5.3 (CC), U5.8 (CC), U6.8 (GND), U7.8 (GND), U8.3 (CC), U8.8 (CC), U9.3 (CC), U9.8 (CC), U10.8 (GND), U11.8 (GND), U12.3 (CC), U12.8 (CC), U13.3 (CC), U13.8 (CC), U14.8 (GND), U15.8 (GND); also elsewhere on the board
VCC: C14.1, C15.1, C16.1, C17.1, C18.1, C19.1, R12.1, R13.1, U6.16 (VCC), U7.16 (VCC), U10.16 (VCC), U11.16 (VCC), U14.16 (VCC), U15.16 (VCC); also elsewhere on the board

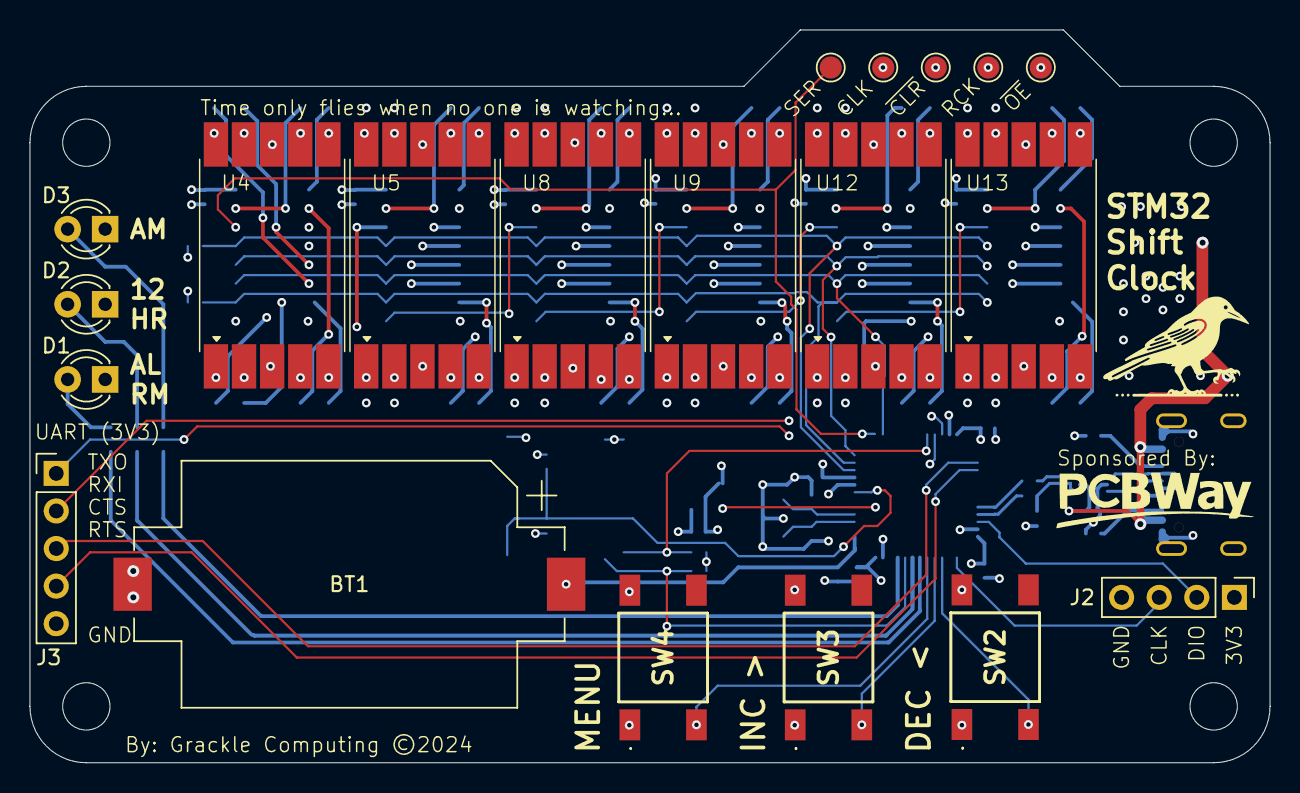
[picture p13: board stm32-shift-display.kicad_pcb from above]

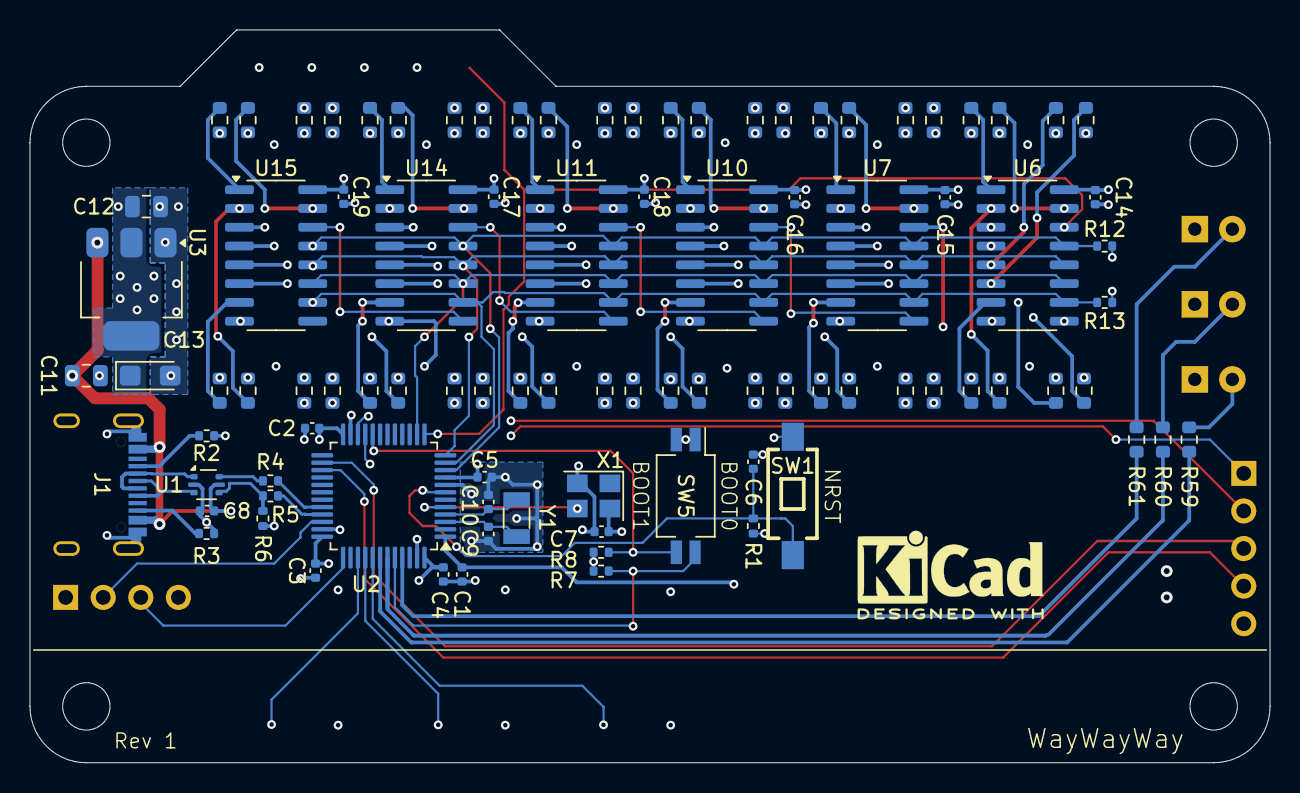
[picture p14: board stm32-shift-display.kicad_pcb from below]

Board: 4 copper layers, 83.8 x 49.5 mm, 118 parts (94 on the bottom side), 139 nets.

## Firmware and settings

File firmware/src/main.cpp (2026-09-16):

#include <Arduino.h>
#include <ShiftDisplay.h>
#include <ShiftDisplayFSM.h>
#include <STM32RTC.h>
#include <AceButton.h>
#include <SerialCommands.h>
#include <stdlib.h>
#include "header.h"

#define SERIAL_COMMANDS_DEBUG

using namespace ace_button;

#define SER PA3
#define SRCLK PA4
#define SRCLRB PA1
#define RCLK PA2
#define OEB PA0

/**
 * ~OE must not be one of the shift-register control pins, and none of them may
 * alias another.
 *
 * ~OE shares GPIOA with all four, and the driver reaches its pins through BSRR
 * words composed from their masks. If a pin define were ever edited to collide
 * with OEB, those words would reach across the brightness timer's pin -- and
 * once the display engine replays them from a DMA buffer there is nothing in
 * the instruction stream to show it. The failure would look like a display that
 * dims wrongly, not like a bug.
 *
 * This catches an alias at build time. ShiftDisplay::begin() catches the subtler
 * case of two distinct pin numbers landing on the same port bit, which only the
 * variant's pin map knows.
 */
static_assert(OEB != SER && OEB != SRCLK && OEB != SRCLRB && OEB != RCLK,
              "The output-enable pin collides with a shift-register control pin");
static_assert(SER != SRCLK && SER != SRCLRB && SER != RCLK &&
                  SRCLK != SRCLRB && SRCLK != RCLK && SRCLRB != RCLK,
              "Two shift-register control pins are assigned to the same pin");

/**
 * User LEDs. The positional names below are how the LEDs sit on the board; note
 * that they run opposite to the schematic's D-numbering, which is a trap worth
 * keeping in mind when cross-referencing:
 *
 *   LED_TOP  PB8  net /LED3  schematic D3  -> AM indicator (12-hour mode only)
 *   LED_MID  PB7  net /LED2  schematic D2  -> 12-hour mode active
 *   LED_BOT  PB6  net /LED1  schematic D1  -> alarm armed (steady) / firing (blink)
 *
 * All three are active high: the cathodes tie to GND through their resistors.
 */
#define LED_BOT PB6
#define LED_MID PB7
#define LED_TOP PB8
#define BTN_SET PB5
#define BTN_PLUS PB4
#define BTN_MINUS PB3

// Utility types
enum ButtonState
{
  PRESSED,
  RELEASED,
  CLICKED,
  LONG_PRESSED,
  REPEATED,
  UNCHANGED
};

ShiftDisplay display(SER, SRCLK, SRCLRB, RCLK, OEB);
ShiftDisplayFSM stateMachine;

char serial_command_buffer_[32];
SerialCommands serial_commands_(&Serial, serial_command_buffer_, sizeof(serial_command_buffer_), "\r\n", " ");
void cmd_unrecognized(SerialCommands *sender, const char *cmd);
void cmd_test(SerialCommands *sender);
void cmd_set_time(SerialCommands *sender);
void cmd_get_time(SerialCommands *sender);
void cmd_set_offset(SerialCommands *sender);
void cmd_get_offset(SerialCommands *sender);
void cmd_get_mode(SerialCommands *sender);
void cmd_set_mode(SerialCommands *sender);
void cmd_get_alarm(SerialCommands *sender);
void cmd_set_alarm(SerialCommands *sender);
void cmd_alarm_enable(SerialCommands *sender);
void cmd_get_leds(SerialCommands *sender);
void cmd_get_bright(SerialCommands *sender);
void cmd_set_bright(SerialCommands *sender);
void cmd_get_disp(SerialCommands *sender);
void cmd_get_backup(SerialCommands *sender);
#ifdef SHIFT_SWEEP
void cmd_set_nops(SerialCommands *sender);
void cmd_set_pattern(SerialCommands *sender);
#endif
#ifdef SHIFT_ENGINE_VERIFY
void cmd_wave_verify(SerialCommands *sender);
void cmd_wave_level(SerialCommands *sender);
void cmd_wave_dump(SerialCommands *sender);
void cmd_wave_rate(SerialCommands *sender);
void cmd_wave_engine(SerialCommands *sender);
void cmd_wave_block(SerialCommands *sender);
void cmd_wave_reset(SerialCommands *sender);
void cmd_wave_tear(SerialCommands *sender);
void cmd_wave_fade(SerialCommands *sender);
#endif
void cmd_set_disp(SerialCommands *sender);

SerialCommand cmd_test_("TEST", cmd_test);
SerialCommand cmd_set_time_("ST", cmd_set_time);
SerialCommand cmd_get_time_("GT", cmd_get_time);
SerialCommand cmd_set_offset_("SO", cmd_set_offset);
SerialCommand cmd_get_offset_("GO", cmd_get_offset);
SerialCommand cmd_get_mode_("GM", cmd_get_mode);
SerialCommand cmd_set_mode_("SM", cmd_set_mode);
SerialCommand cmd_get_alarm_("GA", cmd_get_alarm);
SerialCommand cmd_set_alarm_("SA", cmd_set_alarm);
SerialCommand cmd_alarm_enable_("AE", cmd_alarm_enable);
SerialCommand cmd_get_leds_("GL", cmd_get_leds);
SerialCommand cmd_get_bright_("GI", cmd_get_bright);
SerialCommand cmd_set_bright_("SI", cmd_set_bright);
SerialCommand cmd_get_disp_("GD", cmd_get_disp);
SerialCommand cmd_set_disp_("SD", cmd_set_disp);
SerialCommand cmd_get_backup_("GB", cmd_get_backup);
#ifdef SHIFT_SWEEP
SerialCommand cmd_set_nops_("SN", cmd_set_nops);
SerialCommand cmd_set_pattern_("TP", cmd_set_pattern);
#endif
#ifdef SHIFT_ENGINE_VERIFY
/* Replays the waveform from the CPU, writing exactly the words and in exactly
   the order the two DMA channels will. Establishes that the buffer is right
   before any peripheral is configured -- debugging a DMA display by eye is hard
   enough without also wondering whether what it replays was ever correct. */
bool wave_verify = false;
SerialCommand cmd_wave_verify_("WV", cmd_wave_verify);
SerialCommand cmd_wave_level_("WL", cmd_wave_level);
SerialCommand cmd_wave_dump_("WD", cmd_wave_dump);
SerialCommand cmd_wave_rate_("WR", cmd_wave_rate);
SerialCommand cmd_wave_engine_("WE", cmd_wave_engine);
SerialCommand cmd_wave_block_("WB", cmd_wave_block);
SerialCommand cmd_wave_reset_("WX", cmd_wave_reset);
SerialCommand cmd_wave_tear_("WT", cmd_wave_tear);
SerialCommand cmd_wave_fade_("WF", cmd_wave_fade);
#endif

STM32RTC &rtc = STM32RTC::getInstance();
DateTimeBuffer_t date_time_buf = {0, 1, RTC_MONTH_JANUARY, 1, 0, 0, 0};
bool time_dirty = true;
int8_t timezoneOffset = -6; // CST

/**
 * Settings that outlive a power cut, held in the backup domain on VBAT.
 *
 * Register budget on the F103C8 is DR1..DR10, and most of it is already spoken
 * for: the core claims DR1 (RTC_BKP_INDEX), DR4 (HID_MAGIC_NUMBER_BKP_INDEX) and
 * DR10 in backup.h, and STM32RTC stores the F1's emulated date across DR6 and
 * DR7 (RTC_BKP_DATE). Writing any of those would corrupt someone else's state --
 * the date one in particular would surface as a clock bug, not a settings bug.
 * DR2, DR3 and DR5 are free.
 */
#define BKP_MAGIC_REG LL_RTC_BKP_DR2
#define BKP_FLAGS_REG LL_RTC_BKP_DR3
#define BKP_ALARM_REG LL_RTC_BKP_DR5
/* Low byte: indicator level, stored as-is. High byte: display level, stored
   offset by one so that zero means "never written".
   
   The low byte shipped first, and the high byte was left as zero. Storing the
   display level raw would make that zero indistinguishable from a deliberate
   level 0 -- the dimmest setting -- so every device already in the field would
   come up looking blank on the first boot after this change. The offset costs a
   byte of arithmetic and avoids resetting the settings that are already there. */
#define BKP_BRIGHT_REG LL_RTC_BKP_DR8
#define BKP_MAGIC_VALUE 0xC10CU

#define FLAG_MODE_12 0x1U
#define FLAG_ALARM_ARMED 0x2U

typedef struct
{
  bool mode12;
  bool alarmArmed;
  uint8_t alarmHour;
  uint8_t alarmMinute;
  uint8_t indicatorLevel; // index into led_gamma
  uint8_t displayLevel;   // index into disp_gamma
} Settings_t;

Settings_t settings = {false, false, 7, 0, 4, 5};

// SET gets its own config; see setup_user_btns() for why it must not share
// the repeat-press feature with PLUS/MINUS.
ButtonConfig setButtonConfig;
AceButton btnSet(BTN_SET);
AceButton btnPlus(BTN_PLUS);
AceButton btnMinus(BTN_MINUS);

ButtonState btnSetState = ButtonState::UNCHANGED;
ButtonState btnPlusState = ButtonState::UNCHANGED;
ButtonState btnMinusState = ButtonState::UNCHANGED;

// Values being edited. Copied in when an editor is entered and only written
// through on commit, so backing out discards them.
uint8_t edit_field[3] = {0, 0, 0};
MenuState edit_item = MENU_NONE;

volatile bool alarm_fire_request = false;

#ifdef SHIFT_SWEEP
/**
 * Measurement scaffolding, compiled only into the sweep build.
 *
 * The shift rate has to be established on the assembled board: the parts are
 * 74HC at 3.3 V and the chain is six deep, and the far end is not wired back, so
 * there is no electrical readback. The only instrument is the display itself,
 * which means the test pattern has to make corruption unmistakable.
 *
 * Two patterns, because there are two failure modes. All segments lit exposes a
 * dropped bit. Six distinct digits expose a stream that has shifted -- which the
 * all-lit pattern would hide completely, every digit being identical.
 */
extern volatile uint8_t shift_edge_nops;
uint8_t test_pattern = 0; // 0 = show the clock, 1 = 888888, 2 = 012345
#endif

// What the very first backup-register read returned at boot, captured before
// anything can overwrite it. If settings_load() misreads the magic on a cold
// start it rewrites defaults over the saved values, which destroys them
// permanently -- this is how to tell that apart from the registers themselves
// having been cleared.
uint32_t boot_magic_seen = 0xFFFFFFFFU;
uint32_t boot_flags_seen = 0xFFFFFFFFU;
uint32_t boot_alarm_seen = 0xFFFFFFFFU;
uint32_t boot_bright_seen = 0xFFFFFFFFU;

bool output_en = false;

uint32_t last_activity_ms = 0;

// What was last shifted out, so the display is only re-latched when it changes.
char last_rendered[7] = {0};
uint8_t last_rendered_dp = 0xFF;

#define BLINK_PERIOD_MS 300
#define BREATH_PERIOD_MS 2500

/* PWM_BITS, PWM_MAX_DUTY and PWM_FREQ_HZ moved to header.h: the display engine's
   timer constants are derived from PWM_FREQ_HZ, so it has to be visible to the
   ShiftDisplay library as well as to this file. */

/**
 * Indicator brightness levels, mapped to duty on a gamma curve. Luminous output
 * is linear in duty but perceived lightness is not -- roughly luminance^(1/2.2) --
 * so evenly spaced duty values feel bunched at the bottom and flat at the top.
 * A table beats pow() on a core with no FPU, and at eight entries it costs eight
 * bytes. The lowest entry is floored above the curve's own value so the dimmest
 * setting stays visible rather than reading as a failed LED.
 */
#define LED_LEVELS 8
static const uint16_t led_gamma[LED_LEVELS] = {64, 194, 473, 891, 1456, 2175, 3053, 4095};

/* The same curve for the display, with a higher floor: an indicator only has to
   be visible at its dimmest, whereas the display has to stay readable. */
#define DISP_LEVELS 8
static const uint16_t disp_gamma[DISP_LEVELS] = {128, 259, 546, 964, 1529, 2248, 3126, 4095};
#define MENU_TIMEOUT_MS 10000

// Function definitions
void setup_user_leds();
void setup_user_btns();
void setup_rtc();
void setup_usb();
void settings_load();
void settings_save();
void update_leds();
void update_display_brightness();
void render();
void handle_input();
void begin_edit();
void adjust_field(int8_t delta);
void commit_edit();

// IRQ Handlers and Event Callbacks
void handleEvent(AceButton *, uint8_t, uint8_t);
void irq_rtc_seconds(void *data);
void irq_timer_led();

/**
 * Write content to the display.
 *
 * With the waveform replay running, content goes into the buffer and the refresh
 * picks it up; shifting and latching here as well would fight the replay and show
 * as a flick once a second. Without it, this is the shipping path unchanged.
 */
static inline void display_write(const char *buf, uint8_t dp)
{
  // With the engine running -- or the CPU replay standing in for it -- content
  // goes into the waveform and the refresh picks it up. Shifting and latching
  // here as well would fight it. Without either, this is the shipping path.
  if (display.engineRunning())
  {
    display.setContent(buf, dp);
    return;
  }

#ifdef SHIFT_ENGINE_VERIFY
  if (wave_verify)
  {
    display.setContent(buf, dp);
    return;
  }
#endif

  display.writeDisplay(buf, dp);
  display.latch();
}

/**
 * The menu-exit fade.
 *
 * Leaving the menu, the six positions come up one at a time from the left
 * rather than the time snapping back all at once. Position p starts at
 * p x FADE_STAGGER_MS and ramps to full over FADE_RAMP_MS.
 *
 *   pos 0  ####----
 *   pos 1    ####----
 *   pos 2      ####----      STAGGER 110 ms, RAMP 260 ms, total 810 ms
 *   pos 3        ####----
 *   pos 4          ####----
 *   pos 5            ####----
 *
 * Those timings were chosen by eye from five candidates spanning 320 to 810 ms,
 * and the choice says something about the quantisation worry. The design expected
 * eight linear levels to be coarse -- the step from unlit to one slice is about
 * 39% of the perceptual range -- and expected speed to be what hid it, making a
 * slower fade the riskier one. The slowest candidate was preferred. So the
 * stepping is not the binding constraint at this size and brightness, and none of
 * the ranked remedies (ramping global ~OE underneath, then N = 16, then temporal
 * dither) has turned out to be needed.
 *
 * Driven from elapsed time rather than by counting steps, so a slow pass through
 * the loop skips levels and still finishes on schedule instead of stretching.
 *
 * It changes brightness only. Content is never recomputed or re-shifted for it:
 * per-digit levels are independent of the character buffer, which is what lets
 * this sit beside update_leds() rather than inside render(), leaving the
 * time_dirty path exactly as cheap as it was.
 */
#define FADE_STAGGER_MS 110UL
#define FADE_RAMP_MS 260UL
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
void loop()
{
  // Check buttons
  btnSet.check();
  btnPlus.check();
  btnMinus.check();

  // Check Serial for input
  serial_commands_.ReadSerial();

  if (alarm_fire_request)
  {
    alarm_fire_request = false;
    stateMachine.execute(Action::ALARM_FIRE);
  }

  handle_input();

  // Nothing pressed for a while: drop back to the clock rather than leaving the
  // device stranded in a submenu. Uncommitted edits are discarded.
  if (stateMachine.getState() != State::IDLE &&
      stateMachine.getState() != State::FIRING &&
      (millis() - last_activity_ms) > MENU_TIMEOUT_MS)
  {
    stateMachine.execute(Action::MENU_TIMEOUT);
  }

  /* The fade triggers on a transition, not a state. Backing out, committing an
     editor and timing out all arrive at IDLE through this one update(), so all
     three fade with no special-casing. FIRING -> IDLE deliberately does not:
     dismissing an alarm is not a moment to wait half a second for the time. */
  State state_before = stateMachine.getState();

  stateMachine.update();

  State state_after = stateMachine.getState();

  bool fade_just_began = false;

  if (state_after == State::IDLE &&
      (state_before == State::MENU || state_before == State::EDIT))
  {
    fade_begin();
    fade_just_began = fade_active;
  }

  if (stateMachine.takeCommit())
  {
    commit_edit();
  }

  render();
  update_leds();
  update_display_brightness();

  /* Anything that wants the display readable now ends the fade: a button, a
     return to the menu, an alarm firing.
     
     Not on the pass that started it, though. Leaving the menu is *caused* by a
     button, and the button states are not cleared until the end of the loop, so
     the press that triggered the fade is still latched here and would abort it
     immediately -- every time, for every route out of the menu. That is why this
     worked when driven from the serial command and never once from the buttons. */
  if (fade_active && !fade_just_began &&
      (stateMachine.getState() != State::IDLE ||
       btnSetState != ButtonState::UNCHANGED ||
       btnPlusState != ButtonState::UNCHANGED ||
       btnMinusState != ButtonState::UNCHANGED))
  {
    fade_abort();
  }

  update_display_fade();

#ifdef SHIFT_ENGINE_VERIFY
  /* Replay every slice back to back, continuously, exactly as the DMA engine
     will. Running it here rather than inside render() matters: the engine
     refreshes whether or not the time changed, and the latch-the-previous-slice
     arrangement only reads correctly when slices follow each other without a
     gap. */
  if (wave_verify)
  {
    for (uint8_t s = 0; s < ShiftDisplay::maxDigitLevel(); s++)
    {
      display.shiftSliceByHand(s);
    }
  }
#endif

  // reset the button states
  btnSetState = ButtonState::UNCHANGED;
  btnPlusState = ButtonState::UNCHANGED;
  btnMinusState = ButtonState::UNCHANGED;
}

/**
 * The indicators are PWM-driven, not switched. PB6/PB7/PB8 are TIM4_CH1/CH2/CH3,
 * which analogWrite() resolves through PinMap_TIM without this code naming the
 * timer; the core's defaults are 8-bit duty at 1 kHz.
 *
 * Every write to these pins goes through set_led() and nowhere else. A stray
 * digitalWrite would reconfigure its pin back to plain output and silently stop
 * the timer driving it.
 */
// Last duty written to each indicator, in LED_TOP, LED_MID, LED_BOT order.
// Cached because analogWrite() reconfigures the timer channel on every call,
// which is far too heavy to repeat once per loop for three pins -- and read
// back by GL, since digitalRead() on a PWM'd pin samples the live waveform.
static uint16_t led_duty[3] = {0, 0, 0};

static void apply_leds(uint16_t top, uint16_t mid, uint16_t bot)
{
  if (top != led_duty[0])
  {
    led_duty[0] = top;
    analogWrite(LED_TOP, top);
  }
  if (mid != led_duty[1])
  {
    led_duty[1] = mid;
    analogWrite(LED_MID, mid);
  }
  if (bot != led_duty[2])
  {
    led_duty[2] = bot;
    analogWrite(LED_BOT, bot);
  }
}

/**
 * A smooth fade up and down, scaled so the peak is the configured brightness
 * rather than full duty -- an alarm that overrode a deliberately dim setting
 * would do so at exactly the hour that choice was made for. The trough stays
 * above zero so a glance mid-breath never reads as "not armed".
 */
static uint16_t breath_duty(uint16_t peak)
{
  // The triangle runs over 0..1023 rather than the full 12-bit range: the
  // smoothstep below squares it, and 4095 would overflow 32 bits.
  const uint32_t SPAN = 1023U;
  uint32_t half = BREATH_PERIOD_MS / 2;
  uint32_t phase = millis() % BREATH_PERIOD_MS;
  uint32_t tri = (phase < half) ? (phase * SPAN / half)
                                : ((BREATH_PERIOD_MS - phase) * SPAN / half);
  if (tri > SPAN)
  {
    tri = SPAN;
  }

  // smoothstep, t^2 * (3 - 2t), so the fade eases in and out rather than
  // reversing sharply at the extremes.
  uint32_t smooth = tri * tri * (3U * SPAN - 2U * tri) / (SPAN * SPAN);

  // Then gamma-shape it. The levels are already gamma-mapped, but the breath
  // interpolates between them and needs the same correction for the same
  // reason: equal steps of duty are not equal steps of apparent brightness, so
  // a linear fade appears to race through the dim end and crawl at the top.
  uint32_t shaped = smooth * smooth / SPAN;

  uint16_t trough = peak / 8;
  if (trough == 0)
  {
    trough = 1;
  }
  if (peak <= trough)
  {
    return peak;
  }

  return trough + (uint16_t)(((uint32_t)(peak - trough) * shaped) / SPAN);
}

// The display level in force right now, previewing an edit in progress for the
// same reason the indicators do -- and here the thing being adjusted is the very
// thing you are looking at.
static uint8_t effective_display_level()
{
  if (stateMachine.getState() == State::EDIT && edit_item == MENU_DISP)
  {
    return (edit_field[0] < DISP_LEVELS) ? edit_field[0] : (DISP_LEVELS - 1);
  }
  return (settings.displayLevel < DISP_LEVELS) ? settings.displayLevel
                                               : (DISP_LEVELS - 1);
}

void update_display_brightness()
{
  uint16_t duty = disp_gamma[effective_display_level()];
  if (duty != display.getBrightness())
  {
    display.setBrightness(duty);
  }
}

// The level in force right now: an editor in progress previews its value so the
// choice is made by eye, and backing out restores the committed setting because
// this falls straight back to it.
static uint8_t effective_indicator_level()
{
  if (stateMachine.getState() == State::EDIT && edit_item == MENU_BRIGHT)
  {
    return (edit_field[0] < LED_LEVELS) ? edit_field[0] : (LED_LEVELS - 1);
  }
  return (settings.indicatorLevel < LED_LEVELS) ? settings.indicatorLevel
                                                : (LED_LEVELS - 1);
}

void setup_user_leds()
{
  analogWrite(LED_TOP, 0);
  analogWrite(LED_MID, 0);
  analogWrite(LED_BOT, 0);
}

void setup_user_btns()
{
  pinMode(BTN_SET, INPUT_PULLUP);
  pinMode(BTN_PLUS, INPUT_PULLUP);
  pinMode(BTN_MINUS, INPUT_PULLUP);

  /**
   * PLUS and MINUS: click, and hold-to-repeat while adjusting a field.
   *
   * SET: click, and long press to back out of a level. It needs a separate
   * config because AceButton::check() evaluates long-press and repeat-press in
   * the same pass, and kLongPressDelay and kRepeatPressDelay are both 1000 ms
   * by default. Sharing one config meant a held SET emitted kEventLongPressed
   * and then kEventRepeatPressed immediately after, the latter overwriting the
   * former in the button-state latch -- so holding SET did nothing at all.
   * Keeping repeat off SET removes the collision at its source.
   *
   * kFeatureDoubleClick is deliberately not enabled anywhere: nothing uses
   * double-click and it delays every click by the double-click window.
   */
  ButtonConfig *adjustConfig = ButtonConfig::getSystemButtonConfig();
  adjustConfig->setEventHandler(handleEvent);
  adjustConfig->setFeature(ButtonConfig::kFeatureClick);
  adjustConfig->setFeature(ButtonConfig::kFeatureRepeatPress);

  setButtonConfig.setEventHandler(handleEvent);
  setButtonConfig.setFeature(ButtonConfig::kFeatureClick);
  setButtonConfig.setFeature(ButtonConfig::kFeatureLongPress);
  // Without this, releasing after a long press would also emit a click and
  // advance the field the user was trying to leave.
  setButtonConfig.setFeature(ButtonConfig::kFeatureSuppressAfterLongPress);
  btnSet.setButtonConfig(&setButtonConfig);
}
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

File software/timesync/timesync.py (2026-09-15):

import serial
import ntplib
import csv
import os
import argparse
import datetime

from zoneinfo import ZoneInfo
from time import ctime, time
from dataclasses import dataclass
from serial.tools import list_ports

tz = ZoneInfo("America/Chicago")

@dataclass
class TimeSyncRun:
    ntp_time: int
    device_time: int
    run_time: int
    skew: int

def get_ntp_time(ntp_server="pool.ntp.org"):
    try:
        client = ntplib.NTPClient()
        response = client.request(ntp_server)
        
        return __apply_dst(response.tx_time)
    except ntplib.NTPException as e:
        print(f"Error fetching time from NTP server: {e}")
        exit(-1)

def __apply_dst(time: int):
    return time + __get_dst_offset()

def __get_dst_offset():
    now = datetime.datetime.now(tz)
    if now.dst() != datetime.timedelta(0):
        return 3600
    else:
        return 0

# USB descriptor of the STM32 Shift Clock's CDC interface. The ST-Link shares the
# vendor id but reports a different product id, so the two never collide.
STM32_CDC_VID = 0x0483
STM32_CDC_PID = 0x5740

def find_device_port():
    matches = [p for p in list_ports.comports()
               if p.vid == STM32_CDC_VID and p.pid == STM32_CDC_PID]

    if not matches:
        print(f"Error: no STM32 CDC device (USB {STM32_CDC_VID:04x}:{STM32_CDC_PID:04x}) found.")
        print("Check that the board is plugged in, or name a port with --com <port>.")
        exit(-1)

    if len(matches) > 1:
        print("Error: more than one STM32 CDC device found. Choose one with --com <port>:")
        for p in matches:
            print(f"  {p.device}  serial={p.serial_number}")
        exit(-1)

    return matches[0].device

def get_device_time():
    try:
        ser = serial.Serial(port, baud, timeout=1)
        command = "GT\r\n"

        ser.write(command.encode())

        response = ser.readline().decode().strip()
        return int(response)

    except serial.SerialException as e:
        print(f"Error getting time from device: {e}")
        exit(-1)

    finally:
        if ser.is_open:
            ser.close()

def set_device_time(time: int):
    try:
        ser = serial.Serial(port, baud, timeout=1)
        command = f"ST {time}\r\n"

        ser.write(command.encode())

        response = ser.readline().decode().strip()
        if response == "OK":
            return True
        else:
            print(f"Error: {response}")
            return False

    except serial.SerialException as e:
        print(f"Error setting device time: {e}")
        exit(-1)

    finally:
        if ser.is_open:
            ser.close()

def calculate_skew(time1: int, time2: int):
    return time1 - time2
        

def write_csv_header(file_path: str):
    try:
        with open(file_path, mode="w") as file:
            writer = csv.writer(file)
            writer.writerow(["Run Time", "NTP Time", "Device Time", "Skew"])
    except Exception as e:
        print(f"Error writing to csv file: {e}")
        exit(-1)

def write_csv_row(file_path: str, tsr: TimeSyncRun):
    if not os.path.exists(file_path):
        write_csv_header(file_path)
    try:
        with open(file_path, mode="a") as file:
            writer = csv.writer(file)
            writer.writerow([tsr.run_time, tsr.ntp_time, tsr.device_time, tsr.skew])
    except Exception as e:
        print(f"Error writing to csv file: {e}")

if __name__ == "__main__":

    parser = argparse.ArgumentParser()
    parser.add_argument("-H", "--human", action="store_true", help="Human readable output")
    parser.add_argument("-U", "--update", action="store_true", help="Update device time to NTP time")
    parser.add_argument("--csv", action="store_true", help="Write output to CSV file")
    parser.add_argument("--com", type=str, help="COM port for device")
    args = parser.parse_args()

    port = args.com if args.com is not None else find_device_port()
    
    baud = 115200

    run_time = int(time())
    ntp_time = get_ntp_time()
    ntp_time = int(ntp_time)
    device_time = get_device_time()

    skew = calculate_skew(ntp_time, device_time)

    if args.csv:
        tsr = TimeSyncRun(ntp_time, device_time, run_time, skew)
        write_csv_row("timesync.csv", tsr)

    if abs(skew) > 1 & args.update:
        print("Time skew detected, setting device time to NTP time")
        set_device_time(ntp_time)
        device_time = get_device_time()
        skew = calculate_skew(ntp_time, device_time)

    if args.human:
        print(f"NTP Time: {ctime(ntp_time)}")
        print(f"Device Time: {ctime(device_time)}")
        print(f"Skew: {skew}")
    else:
        print(f"{run_time},{ntp_time},{device_time},{skew}")

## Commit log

2024-05-30 initial commit and board rev 0
    [shift_display.kicad_sch, stm32-shift-display.kicad_pcb, stm32-shift-display.kicad_sch]
2024-05-30 Add license, readme, and file moves.
    [shift_display.kicad_sch, stm32-shift-display.kicad_pcb, stm32-shift-display.kicad_sch]
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2024-06-05 Update firmware for board rev 0
    [stm32-shift-display.kicad_pcb]
2024-06-21 Pre-autoroute on rev2
    [shift_display.kicad_sch, stm32-shift-display.kicad_pcb, stm32-shift-display.kicad_sch]
2024-06-22 Initial rev2 design, layout, routing, and mech done. Order submitted.
    [desk-stand-Body.step, shift_display.kicad_sch, stm32-shift-display.kicad_pcb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]
2024-07-09 documentation updates
    [stm32-shift-display.kicad_pcb]
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2026-09-15 Set timezone offset to CST and harden timesync error handling
    Work that predates the environment/docs pass and was already sitting
    uncommitted in the working tree; recorded here on its own so it stays
    separate from the tooling changes that follow.
    - firmware: timezoneOffset -5 (CDT) -> -6 (CST)
    - timesync: derive the DST offset from America/Chicago and apply it to
    the NTP time before comparing or sending
    - timesync: report which operation failed and exit non-zero instead of
    returning None/False into the caller
    [main.cpp, timesync.py]
2026-09-15 firmware: pin platform to ststm32@19.7.1
    Unpinned, PlatformIO resolves ststm32 20.0.0, whose Arduino core 4.x
    breaks the build outright: STM32duino RTC and Low Power fail to compile
    internally, and STM32RTC.h's `voidFuncPtr` (void (*)(void*)) conflicts
    with the core's (void (*)()), so main.cpp's rtc.attachSecondsInterrupt
    call no longer matches.
    Pinning backward is not an option either -- platforms contemporary with
    this source (17.x, 18.x) can no longer resolve their framework package
    from the registry (UnknownPackageError on framework-arduinoststm32
    ~4.20801.0). 19.7.1 is the newest platform still on the 2.x core line
    (framework-arduinoststm32 4.21200.0), where this source builds unmodifi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
2026-09-15 timesync: manage with uv and discover the board by USB descriptor
    The committed .venv was built from a Homebrew python@3.12.4 that does not
    exist on this machine, and its bin/python symlinks were gone, so the tool
    could not run at all. Replace it with a uv project that pins the
    interpreter (3.12.13) and the dependency resolution, rather than
    inheriting whatever python3 happens to be on PATH.
    requirements.txt is fully represented by pyproject.toml + uv.lock and is
    removed rather than kept as a second source of truth; `uv export
    --format requirements-txt` regenerates it if pip is ever needed.
    Port selection no longer falls back to a device node hardcoded for one
    machine. It enumerates via se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
    [timesync.py]
2026-09-15 Add dev environment readiness check, ignore local build/editor state
    check-dev-env.sh reports PlatformIO, uv, the Python environment, the
    ST-Link, and the board's CDC interface in one pass. It checks every
    prerequisite before exiting so one gap cannot hide another, names the
    install command for whatever is missing, and exits non-zero on any gap.
    USB enumeration goes through an absolute ioreg path, so a trimmed PATH
    reports "cannot look" rather than a false "not attached".
    .gitignore picks up .DS_Store, firmware/.pio/, .venv/, __pycache__, and
    local editor/agent state, so the working tree shows only real changes.
2026-09-15 docs: align README with the board, add DEVELOPMENT.md and CLAUDE.md
    docs/DEVELOPMENT.md is new and is the authority for commands: prerequisites,
    build and flash, the CDC command table, the rev 2 pin map, the timesync
    workflow, known defects, and what is still unimplemented. Every command in
    it was run on this machine; the two that could not be (uv's own installer,
    and pio device monitor, which refuses non-interactive stdin) say so.
    README: the board is called rev 2 here, matching the schematic, the Rev2
    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
2026-09-15 openspec: record the environment pass and its specs
    Archives align-docs-and-dev-env (4/4 artifacts, 46/46 tasks) and syncs its
    deltas into openspec/specs/ as the baseline future changes write against:
    dev-environment (7 requirements) and project-documentation (8 requirements),
    32 scenarios in total.
    Fills in config.yaml's context block so new changes inherit the stack, the
    platform pin, and the branch/licensing conventions instead of re-deriving them.
    Opens port-to-arduino-core-4 with the concrete core 4.x failures captured
    while they were reproducible. Its proposal is written; specs, design, and
    tasks are not.
    Also tracks the .claude/ openspec commands and skills; settings.local.json
    sta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
2026-09-15 openspec: plan the Arduino core 3.0.0 port
    Renames the change from port-to-arduino-core-4 and rewrites it. The
    original premise was wrong on two counts, both found by building the port
    in a scratch copy of firmware/ before committing to a plan.
    First, the core version. framework-arduinoststm32@4.30000.0 is PlatformIO's
    package version; the Arduino core inside it is 3.0.0 (platform.txt:
    version=3.0.0), just as 4.21200.0 is core 2.12.0. Conflating the two is
    what produced the "core 4.x" naming in docs/DEVELOPMENT.md, CLAUDE.md, and
    109d621's message. The docs are corrected as part of implementing this
    change; the merged commit message is left alone.
    Second, the scope. The port needs no firmw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
2026-09-15 Port to Arduino core 3.0.0
    Lifts the ststm32@19.7.1 pin. The firmware now builds against the current
    platform (ststm32 20.0.0, framework-arduinoststm32 4.30000.0, Arduino core
    3.0.0) with no source changes at all.
    The pin was never really about the core. STM32duino RTC 1.9.0 declared its
    own voidFuncPtr as void (*)(void*), colliding with the core's
    void (*)(void) in api/Common.h. RTC 2.0.0 drops that typedef and takes
    voidFuncPtrParam for attachSecondsInterrupt -- already the shape of
    irq_rtc_seconds(void *data), so main.cpp needed no edit. STM32duino Low
    Power did fail against core 3.0.0, but grep finds no reference to it in
    src/, lib/, or include/, so it is removed from lib_deps rather th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
2026-09-15 openspec: sync core-3 deltas and archive the change
    Syncs port-to-arduino-core-3's delta into openspec/specs/dev-environment
    and archives the change as complete (4/4 artifacts, 28/28 tasks).
    dev-environment goes 7 -> 9 requirements, 15 -> 22 scenarios:
    - MODIFIED "Firmware builds from a clean tree": a clean build now fetches
    three lib_deps, not four, since STM32duino Low Power was removed.
    - ADDED "The toolchain is not pinned to a superseded core line": the build
    must resolve against a currently published core, with ranges rather than
    pins to single releases, so a registry purge cannot strand it again.
    - ADDED "A toolchain change is verified on hardware": compiling proves the
    sourc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
2026-09-15 Complete the on-device menu, LED indicators, and a daily alarm
    The UI was scaffolding that could not run: ShiftDisplayFSM::update() committed
    currentState but never currentMenuState, so every menu transition below the top
    level was computed and discarded. handleEvent() matched only kEventClicked, so
    the long-press and repeat features already enabled in ButtonConfig produced
    events nothing read, and PLUS/MINUS were debounced every loop then thrown away.
    The three LEDs were driven LOW once at boot and never again.
    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
2026-09-15 openspec: sync the firmware specs and archive the menu change
    Syncs complete-menu-and-led-indicators' three deltas into openspec/specs/ and
    archives the change as complete (4/4 artifacts, 54/54 tasks).
    These are the first specs describing what the firmware does rather than how the
    project is built -- until now openspec/specs/ held only dev-environment and
    project-documentation, both about the workbench rather than the clock.
    clock-ui 7 requirements, 21 scenarios
    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
2026-09-15 openspec: propose display dimming
    Captures the second half of the brightness exploration. ~OE is on PA0 =
    TIM2_CH1 and TIM2 is unclaimed (the variant reserves TIM3 for tone and TIM4
    for servo), and the netlist shows ~OE as a single net across all six shift
    registers with a 10k pull-up, so the display blanks safely through reset and
    dims globally and uniformly.
    The static drive is what makes PWM dimming the good case here rather than a
    compromise: there is no refresh scan to beat against, so duty is the only
    variable and segment current stays at its design point at every brightness.
    Proposal only -- no specs, design or tasks yet.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
2026-09-15 Dim the indicator LEDs and breathe the alarm
    The three indicators were driven HIGH or LOW and nothing else -- glaring in a
    dark room, with no way to turn them down -- and a firing alarm blinked off the
    same square wave that drives the field-edit blink, reading as an error light.
    Board rev 2 remapped these pins for exactly this and nothing had used it; the
    intent was still in the source as the dead AlrmLEDTim stub, which this replaces.
    PB6/PB7/PB8 are TIM4_CH1/CH2/CH3, reached through analogWrite so the timer is
    never named. Eight gamma-mapped brightness levels cover all three indicators,
    adjustable from the menu with the LEDs themselves as the live preview, and
    persisted in the low byte of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
    [main.cpp]
2026-09-15 openspec: sync the LED dimming deltas and archive the change
    Applies indicator-led-dimming's two deltas and archives it as complete
    (4/4 artifacts, 32/32 tasks).
    Unlike the earlier changes in this repo these are not pure additions -- both
    carry MODIFIED requirements that replace existing blocks in place, so the main
    specs now describe what the board actually does rather than gaining a second
    contradictory copy:
    alarm "Firing is signalled visibly and can be dismissed"
    the bottom LED breathes rather than blinks, and firing must stay
    observable from a host -- which is how it gets verified
    5 requirements unchanged, 16 -> 19 scenarios
    clock-ui "The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
2026-09-15 Dim the display, and write glyphs as segments
    ~OE moves from a GPIO that was driven low once at startup to PWM on TIM2_CH1,
    giving eight gamma-mapped brightness levels across all six digits. It is one net
    across all six shift registers, which is why brightness is global and per-digit
    dimming is not on offer.
    The static drive is what makes this the good case rather than a compromise: six
    595s and 48 segment resistors with no multiplexing, so there is no refresh scan
    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
2026-09-16 Add a settings-storage diagnostic
    Settings have twice been reported as returning to defaults, and neither instance
    reproduced. After the fact the two possible causes are indistinguishable: backup
    storage that failed to retain, and firmware that misread the validity marker and
    rewrote defaults over good values. The second is worse and hides itself -- every
    boot afterwards reads a valid marker with default contents.
    GB reports the backup registers twice: what settings_load() read at start-up,
    captured before anything could overwrite it, and what they hold now. Only the
    start-up capture separates the two causes.
    A controlled power cycle with distinctive values in all four settings, both
    cable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
    [main.cpp]
2026-09-16 openspec: sync the display dimming deltas and archive the change
    Applies display-dimming's two deltas and archives it as complete (4/4 artifacts,
    37/37 tasks plus the two folded-in groups).
    clock-ui "The display shows the current time at rest" now says the time is
    shown at the configured brightness, and that brightness and content
    are independent -- changing one must not disturb the other
    + "Display brightness is user-settable"
    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
2026-09-16 Cut flash from 82.3% to 56.2% without changing behaviour
    17,092 bytes, verified byte-identical at every stage against output captured
    from the firmware before any of it was touched.
    integer date arithmetic 8,788
    print() instead of printf 3,632
    link-time optimisation 4,672
    The date figure is the one worth understanding. main.cpp called localtime(),
    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
2026-09-16 openspec: sync the flash reduction deltas and archive the change
    Applies reduce-flash-footprint's two deltas and archives it as complete
    (4/4 artifacts, 39/39 tasks).
    serial-command-console
    MODIFIED "The existing command set is preserved exactly" -- the commands
    keep their names, arguments, replies and framing, and the internal
    implementation may change freely provided the bytes on the wire do
    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
2026-09-16 Drive the shift-out through BSRR instead of digitalWrite
    A full 48-bit refresh goes from ~78 us to ~6.7 us, a shift clock of roughly
    615 kHz to about 7 MHz. The inner loop is ~9 instructions per bit against 117.
    digitalWrite spent about 35 cycles turning a pin number back into a port and a
    bit mask -- bounds check, two table lookups, bitfield extraction -- to reach a
    single store, and the answer never changed, because the pins are fixed at
    construction. begin() now resolves them once and precomputes the BSRR words. On
    this board the data and clock pins share a port, so one store presents a bit and
    drops the clock together; that is checked rather than assumed, with a fallback
    to separate wri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
    [main.cpp]
2026-09-16 openspec: sync the shift-out delta and archive the change
    Applies bsrr-shift-out's delta and archives it (4/4 artifacts, 31/31 tasks).
    clock-ui
    MODIFIED "The output-enable line has a single owner" -- the output-enable
    line shares a GPIO port with the data, clock, latch and clear
    lines, so code driving those must address only the pins it owns
    and never write the port as a whole
    ADDED "The shift-out stays within the shift registers' timing limits",
    requiring the rate to come from measurement on the assembled
    board, with the margin recorded, because the binding constraint
    is six stages of serial propagat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
2026-09-16 Blank the leading hour zero in 12-hour mode
    The clock showed 09 30 00 at half past nine. It now shows a blank, which is what
    every domestic clock does. 24-hour mode keeps its leading zero, where it belongs.
    The hours were already converted for display -- display_hours() returns 1-12 in
    12-hour mode and the RTC stays in 24-hour format regardless -- so the only thing
    missing was suppressing the tens digit when it is zero.
    Both places that render the time go through one helper. Inlining the conditional
    in the idle path and the alarm-flash path separately invites the follow-up bug
    where someone changes one and the flash quietly disagrees with the clock it is
    flashing; verified on the device th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
    [main.cpp]
2026-09-16 openspec: plan the DMA display engine
    Fills in the design, spec delta and tasks behind the proposal that was
    captured alongside bsrr-shift-out.
    Two things the proposal sketched turned out differently once the numbers
    were worked through.
    The waveform halves. A second DMA channel with memory increment disabled
    replays the constant SRCLK-high word forever, so only the data words need
    a buffer: 48 words per slice instead of 96, 1536 bytes at eight slices
    rather than the 3200 the proposal estimated. The latch costs nothing on
    top -- the RCLK bits ride in the first two words of each slice and latch
    the previous slice, which avoids both a third channel and the extra clock
    pulses that would push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
2026-09-16 Drop dimming the leading hour digit from the DMA plan
    The blank that blank-leading-hour-zero shipped is the better result, so
    the use the proposal was originally built around is gone. It moves from
    "deferred, decide later" to "not in scope", in the proposal, the design's
    non-goals and the task list.
    The spec delta never covered it, so no requirement changes. Task 7.5
    stays and gets more pointed: the blank is behaviour that already shipped
    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
2026-09-16 Reorder the fade's remedies: global ~OE ramp before more slices
    Working the perceptual arithmetic reversed the ranking. Perceived
    lightness goes as luminance^(1/2.2), so halving a step costs 4.6x the
    slices, and because a slice is locked to one ~OE period the frame rate is
    ~OE_freq/N -- resolution is bought by spending refresh rate. A 10% first
    step needs 158 slices: 30 KB the board does not have, at 25 Hz. N = 16 is
    the practical ceiling and still leaves a 28% step. No feasible slice count
    makes the appearance moment smooth.
    The appearance moment is also the wrong target. Going from unlit to
    dimmest-visible is a change in presence, not brightness; even 4096 levels
    has a first perceptible l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
2026-09-16 Build the refresh waveform, and find the board runs at 48 MHz
    Group 3 of dma-display-engine: the waveform buffer, the word builder, and
    a CPU replay that writes exactly the words the two DMA channels will, in
    exactly their order. Establishing that the buffer is right before any
    peripheral is configured matters here -- there is no readback on this
    chain, so a DMA display debugged by eye should not also have "was the
    buffer ever correct" as a live hypothesis.
    The board runs at 48 MHz, not 72. SystemCoreClock reports 48000000, and
    the runtime guard added in the previous commit is what found it: the first
    flashed build asserted 72 MHz and the device answered clkok=0. An F103 is
    usually assumed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
    [main.cpp]
2026-09-16 Verify the waveform on hardware, and measure what the CPU replay costs
    Tasks 3.3 and 3.4 pass. Replaying the waveform from the CPU -- writing
    exactly the words the two DMA channels will, in their order -- shows the
    correct time at 12:34:56 in 24-hour mode, with content in the right
    positions rather than shifted by one, so both the bit ordering and the
    latch-the-previous-slice arrangement are right. Per-digit dimming works:
    one digit steps visibly dimmer, a 1-2-3-4-6-8 gradient reads as a ramp,
    and a hand-driven fade read as a flourish rather than as steps.
    The replay did not flicker, which was not expected, so it got measured. One
    8-slice frame takes 111 us: 9,011 frames/second flat out, a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
    [main.cpp]
2026-09-16 Hand the display to TIM1 and DMA
    Group 4 of dma-display-engine. The engine drives the display; the
    bit-banged path stays compiled in behind SHIFT_ENGINE_DMA=0, and WE swaps
    them at runtime in the verify build.
    The trigger pairing differs from the design and the reason is worth
    keeping. The design had CH1 present data and CH2 raise the clock, which
    needs CCR1 = 0 -- a compare coinciding with the counter wrap, an edge case
    not worth betting a hard-to-debug peripheral on. The update event is the
    wrap, unambiguously, so data rides update and only the clock needs a
    compare, at mid-period where nothing is ambiguous:
    TIM1 update -> DMA1 ch5 -> GPIOA->BSRR 48 words/slice, incrementing
    TIM1 C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
    [main.cpp]
2026-09-16 Make the driver's entry points mean the same thing under the engine
    Group 5 of dma-display-engine, plus the per-digit rendering from group 6.
    The Print path would have broken silently. print() reaches shiftOutByte(),
    which now declines to fight the engine for the pins, so it would have
    returned success and displayed nothing. Nothing in main.cpp uses it, so
    that would have sat until someone did. It now moves the character buffer
    along instead, carrying the decimal points with their characters, which
    reproduces the streaming model the bit-banged version had.
    clear() has no callers at all, including the one inside write() that was
    already commented out. Reworked regardless so it means the sam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
    [main.cpp]
2026-09-16 Add the menu-exit fade, and validate the slice lock on hardware
    Groups 6 and 7 of dma-display-engine.
    The lock holds. Six digits at 4/8, 2/8 and 6/8 under the running engine
    showed no position standing out, and a dimmed digit held at five global
    brightness levels showed no beat. This is the design's central claim and
    the one thing reasoning could not settle: the engine is phase-locked, so a
    slice not spanning a whole ~OE period would give each digit a fixed share
    of the on-time that never averages away. The earlier free-running replay
    could not test this, because drift hid exactly the error in question.
    The fade triggers on a transition rather than a state. Backing out,
    committing an edito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
    [main.cpp]
2026-09-16 Stop the fade aborting itself on the pass that starts it
    The fade never once ran from the buttons. Leaving the menu is caused by a
    button press, and the button states are not cleared until the end of the
    loop, so the press that triggered the fade was still latched when the abort
    check ran a few lines later. fade_begin() at line 542, fade_abort() at 562,
    every time, by every route out of the menu.
    The abort now skips the pass that started the fade. A press arriving on any
    later pass still ends it, which is the behaviour that was wanted.
    Worth recording how this got through. WF -- the serial trigger added so the
    fade could be watched repeatedly -- exercised the timing, the ramp, the
    blanked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
    [main.cpp]
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

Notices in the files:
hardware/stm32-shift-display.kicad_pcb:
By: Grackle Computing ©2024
